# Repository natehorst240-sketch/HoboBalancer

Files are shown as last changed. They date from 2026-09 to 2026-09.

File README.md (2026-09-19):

# HoboBalancer

Hobby helicopter rotor-balancing instrumentation. KiCad 10 projects plus ESP32-S3
firmware.

> **Reference and troubleshooting only.** These boards report approximate RPM, 1/rev
> vibration magnitude, phase, stability and trends. Maintenance balancing remains with
> calibrated MicroVib / DynaVibe equipment. Neither the firmware nor the physical
> measurement accuracy has been validated on a bench, let alone on an aircraft. Nothing
> here is airworthiness-approved.

Open the projects in **KiCad 10.0.3 or later**. They use the KiCad 10 file format and
KiCad 9 will not open them.

## Projects

| Directory | Board | Revision | State |
|---|---|---|---|
| `.` (root) | `Balancer` — STM32 balancer | Rev A | Schematic only; `Balancer.kicad_pcb` is an empty stub |
| `BalancerREF/` | **HOBOVibe** — ESP32-S3 reference puck | **Rev G** | 50 × 50 mm, 4 layer, fully routed, DRC clean apart from three accepted warnings (see below) |
| `BalancerREF_OptHead/` | Optical tach head | **Rev B** | 25 × 50 mm, 2 layer, routed; no mounting holes yet |

Both boards are routed. On the main board `SYS`, `SYS_SW`, `BAT` and `USB_VBUS` had been
routed across In2.Cu, which is the +3V3 plane; those tracks were removed on 2026-09-18 so
the plane is whole again, and those four nets were then re-routed on the outer layers (PR #7,
merged with Rev G on 2026-09-19). The Rev G connections (U7 pass-through, R39) are routed too.
`BalancerREF/review/drc-review.rpt` (KiCad 10.0.6) shows 0 errors and 0 unconnected; what is
left is the GCT USB-C footprint's own peg-to-pad spacing (4), the ESP32 antenna overhanging
the edge by design (2) and the locally edited U1 footprint (1).
Placement was machine-generated and then adjusted by hand; look at it in pcbnew before
trusting it.

Both carry pick-and-place **fiducials** (1 mm dot, 2 mm mask opening): three per
populated face, at three of the four corners. Never four — a symmetric set gives the
placement machine no way to tell a 180°-rotated panel from a correct one. The main
board has them on both faces; the optical head is single-sided so its back has none.

### Track widths

Net classes are set in each `.kicad_pro`, sized from IPC-2221 at 1 oz outer copper and
a 10 °C rise (0.20 mm ≈ 0.74 A, 0.50 mm ≈ 1.45 A, 0.80 mm ≈ 2.03 A):

| Class | Track | Nets |
|---|---|---|
| Default | 0.20 mm | everything else |
| Power | 0.50 mm | `+3V3` `SYS` `SYS_SW` `BAT` `USB_VBUS` `GND` |
| Switch | 0.80 mm | `U6-L1` `U6-L2` — main board only |
| USB | 0.20 mm | `D+`/`D-` both sides, diff pair 0.20/0.15 |
| Emitter | 0.80 mm | `SYS_SW` `D1-A` `D1-K` — head board only |

The emitter resistor is sized at the **top** of the SYS_SW range, not at the battery.
The BQ24075 regulates OUT to 5.5 V, so R18 is 3.9 Ω for about 0.49 A at a full cell and
about 0.90 A worst case — under D1's 1 A absolute maximum. At the old 3.0 Ω the USB case
reached roughly 1.1 A.

Two caveats. **Switch clearance stays at 0.20 mm**, not the 0.25 the wider track might
suggest: the TPS63031's WSON-10 places its own L1/L2 pads 0.20 mm from its thermal
pad, so anything stricter fails inside the package and no routing choice can fix it.
And the **USB numbers are not an impedance solution** — real 90 Ω differential needs
the fab's actual stackup. The ESP32-S3's native USB is Full Speed (12 Mbps), where
that matters far less than it would at High Speed.

### BalancerREF (HOBOVibe)

The main puck. ESP32-S3-MINI-1, IIS3DWB vibration sensor on SPI, LM1815 magnetic tach
front end, BQ24075 charger with an integrated dynamic power path, TPS63031 buck-boost, and a
1x05 header for an optional u-blox-class GPS used by the in-flight logging mode.

Two measurement profiles: **MR-VERT** uses an external isolated two-wire VR pickup;
**TR-VERT** uses the optical tach against retroreflective tape.

50 × 50 mm, four layers, components on both faces: ICs, connectors, switches and test
points on the front, passives on the back so each decoupling cap sits under its IC's
power pins. M2.5 mounting holes at the four corners, on a 43.40 × 42.90 mm rectangle
centred on the board. U1's antenna deliberately overhangs the top edge, which puts
almost all of its keepout off the board — the wide band still reaches 0.44 mm inside
the top edge, which is why the mounting-hole rectangle is 0.5 mm shorter than it is
wide. The overhang is required anyway, because the aluminium bracket must not sit
behind a PCB antenna.

The puck mounts **vertically, ESP32 to the left and USB-C to the right**. `UP` and
`LEFT` markers on the front silkscreen record that; with the board vertical the
accelerometer's vertical axis is in-plane (stiff) and the flexible out-of-plane axis
carries lateral instead. Which sensor channel that is still needs recording from
DS12569's orientation figure — firmware can also identify it at runtime, since the
vertical axis reads a static 1 g when the puck is mounted upright.

Three switches: SW1 power slide, SW2 acquire, SW3 boot. There is no reset button —
SW1 feeds U6's VIN and EN, so the power slide already power-cycles the MCU. SW1 is a
Würth WS-SLTV rated 300 mA switching; steady draw through it is about 180 mA, but BLE
TX bursts and switch-on inrush exceed that briefly. That is accepted as reduced switch
life rather than designed out — see DATASHEET-VERIFICATION.md.

**Sleep is not low power.** The LM1815 draws 3.6 mA typical (6 mA max) and sits on the
always-on 3V3 rail, as do the head's op-amp and comparator, so a sleeping puck draws
milliamps and a 500 mAh cell lasts days rather than months. If flight logging ever
depends on long sleeps, the fix is a load switch on the LM1815 and the head supply.

**Power path and charging.** A BQ24075 runs the input: it charges the cell and powers
the system from the same input independently, so charge termination is correct while
the puck is running, and it will run with a defective or absent pack. R3 (3.57 k)
sets fast charge to about 249 mA — 0.5C for a 500 mAh cell — and R35 (1.6 k) sets the
resistor-programmed input limit to about 1.0 A.

Four pins go to the MCU. `CHG_EN1` (GPIO5) and `CHG_EN2` (GPIO18) select the input
current limit; `PGOOD_N` (GPIO21) and `CHG_STAT` (GPIO38) are open-drain status inputs
with 100 k pull-ups, both **active low**. Two things are easy to get wrong here:

- The datasheet's current-limit table is indexed **(EN2, EN1)**, the reverse of the
  order the pins are named in.
- Both EN pins have 285 k internal pulldowns, so the limit is USB100 — **100 mA** —
  until firmware deliberately raises it.

`PGOOD_N` is the USB-present signal. Earlier revisions tried to infer that by comparing
two ADC dividers, because a single reading of `SYS_SW` cannot answer it: SYS was fed
either from USB through a Schottky or from the cell through a PFET, and the ranges
overlap. The BQ24075 arbitrates the input itself and simply reports the answer, so
Rev E deleted the second divider (`BAT_SENSE`, R33/R34/C31) along with its 500 k ADC
source impedance and its ~2 µA standing drain on the cell.

`SUPPLY_SENSE` (`SYS_SW/2` on GPIO12) survives as the supply-voltage reading. While the
puck runs unplugged the BQ24075 connects OUT to the battery, so it reads the cell; while
charging it reads the input-derived rail instead, not the cell. It is on ADC2_CH1, the
converter shared with the radio — worth knowing, because it is now the only supply
measurement on the board.

See [`BalancerREF/README.md`](BalancerREF/README.md) for the circuit description and
[`BalancerREF/DATASHEET-VERIFICATION.md`](BalancerREF/DATASHEET-VERIFICATION.md) for
every pin mapping checked against the manufacturer tables.

### BalancerREF_OptHead

The optical tach front end, split onto its own board on 2026-09-11. It mounts at 90° to
the main PCB on the second leg of an aluminium L-bracket, on a pivot bolt so the emitter
can be aimed at the tape. The split exists because neither optical part has leads to
form — the XPEBRD-L1 is a ceramic SMD LED and the BPW34S is the surface-mount BPW34 — so
they need their own copper.

The cut is deliberately placed **after** the comparator. The cable then carries only DC
rails and digital edges; cutting at the photodiode would have put the 10 kΩ
transimpedance summing junction on a flying lead beside a wire switching 500 mA at
20 kHz.

Connected to the main board by a 7-way cable (`J5` on both). Ground is interleaved
between the two digital lines: emitter-pulse crosstalk onto `OPT_COMP` arrives inside
the synchronous gating window by definition, so the detection logic cannot reject it and
it has to be stopped at the connector.

25 × 50 mm, two layers, **every part on the front** so B.Cu can be a ground pour. Five
short signal crossings (`AMP_INV`, `OPT_AMP`, `CMP_OUT`, `OPT_COMP`, `OPT_LED_EN`) still
run on B.Cu, two of them directly under U8, and should move to the front before fab. The
board also has **no mounting or pivot hole yet**; the position depends on the bracket. A
solid back-side ground is worth more than a clean optical face: the transimpedance summing node is
the highest-impedance point in the design and sits beside a wire switching 500 mA at
20 kHz. The cost is that the baffle and the red acrylic window have to clear the
electronics.

D1 sits centred on the optical axis with PD1 18 mm directly below it. **That spacing
and the lens keepout radius are estimates** — both are constants at the top of
`scripts/build_pcb.py` and should be set from the real Ledil TINA holder before anyone
commits to them. The spacing is the one that affects performance: it sets baffle depth
and the parallax back to the tape at the 18–24 in working range.

Refill zones (`Edit → Fill All Zones`) after any edit made outside pcbnew; the scripts
here cannot drive KiCad's zone filler.

## Verification

Both boards carry a connectivity checker that compares an exported netlist against
circuit specifications written by hand — exact net membership, so an unintended short, a
bypassed series part or a reversed two-terminal part fails rather than passing quietly.

```bash
# main board
cd BalancerREF
kicad-cli sch export netlist --format kicadsexpr -o review/BalancerREF.net BalancerREF.kicad_sch
python scripts/verify_netlist.py     # PASS: 49 exact circuit nets, 293 pin endpoints

# optical head
cd ../BalancerREF_OptHead
kicad-cli sch export netlist --format kicadsexpr -o review/OptHead.net BalancerREF_OptHead.kicad_sch
python scripts/verify_head.py        # PASS: 16 exact circuit nets, 63 pin endpoints
```

Each board has its own spec. The main board's covers everything except the optical
chain and asserts that *every* pin in the netlist belongs to some named net, so a
wrong connector pinout or a missed part fails rather than passing quietly. Run these
against a freshly exported netlist — a stale `.net` will report a green that means
nothing.

Both sheets pass ERC at **0 errors and 0 warnings**. Removing a part leaves the wires
that used to reach its pins, so `BalancerREF/scripts/fix_dangling_wires.py` sweeps those:
it removes a wire only when one end touches nothing at all, never removes a wire carrying
a label (labels attach to wire bodies, so that would silently split a net - trimming the
dead tail back to the label is the fix there), and exports the netlist before and after
to prove no pin changed net. It checks its own geometry against KiCad's ERC first and
aborts if the two disagree.

Generator scripts under `scripts/` are guarded and refuse to run without
`--overwrite-hand-layout`: both sheets were laid out by hand after generation, and the
`.kicad_sch` files are the source of truth.

## Revisions

Hardware revisions are marked with git tags rather than in filenames, so the KiCad
project names stay stable across revisions. `git tag` lists them; `git checkout revD`
gets that snapshot.

| Tag | Board state |
|---|---|
| `revC` | single board, optical front end on the main PCB, no layout |
| `revD` | optical head split out; SW4 and R5 dropped; BAT sense divider added; both boards placed |
| `revE` | MCP73831 + D2 + Q3 + R27 + R31 replaced by a BQ24075; BAT sense divider removed |
| `revF` | PD1 polarity fix; R18 3.9 ohm; U9 Schmitt NAND; switcher and TIA placement |

Rev D was defined by the **battery/supply sensing change** — `BAT_SENSE` on GPIO4
alongside `SUPPLY_SENSE`, to let firmware tell USB from battery. The board split and the
two part deletions rode along in the same revision.

Rev E is the **charge-management change**, and it removed Rev D's divider again: with a
BQ24075 arbitrating the input, `PGOOD` answers "am I on USB?" directly and the
two-divider comparison had nothing left to do. Five discrete parts went with it.

Rev F is the **repo-review revision** — no new function, but a set of corrections that
had to land before any copper is routed. One of them cleans up after Rev E: removing the
USB Schottky raised `SYS_SW`, which pushed the head's emitter resistor past D1's absolute
maximum current. The others are a logic part run outside its input-transition spec and
three placement problems, the worst being a 2.4 MHz switching loop routed through vias.
Rev F is also the first revision of the optical head since it was created, so that board
moves from Rev A to **Rev B**.

Rev F also carries the one outright **functional** defect found so far: PD1 was wired
with its anode on the transimpedance summing node, which sends the signal the wrong way
through two inverting stages and leaves the comparator unable to trip at any light level.
The optical tach could never have worked. Flipping the detector fixes it without changing
anything else; `BalancerREF/DATASHEET-VERIFICATION.md` traces the chain stage by stage,
including why the connectivity checkers passed the whole time — they prove the netlist
matches the intent, not that the intent works.

Rev G is the **Reddit-review revision** (2026-09-19). Three schematic corrections on the
main board: the USB VBUS TVS (D3) was drawn forward biased, the USB data lines now pass
through the ESD array (U7) instead of hanging off it as stubs, and U9's OPT_COMP input
gets a pull-down so it does not float when the optical head is unplugged. The board
carries the new pad nets, and the USB pass-through and the new resistor are routed.

Two review items were checked and deliberately **not** changed — SW1's current rating
and U1's footprint. `BalancerREF/DATASHEET-VERIFICATION.md` records why, so they are not
re-raised at the next review.

## Not in this repo

Build output (`.pio/`, `build/`, `release/`), the firmware virtualenv, and the
point-in-time `*-backups/` and `archives/` zips are excluded — git tracks history
itself. Manufacturer datasheets in `BalancerREF/sources/` are included for reference
alongside the pin audits; `scripts/fetch_sources.py` re-fetches them from the URLs in
`sources/urls.json`.

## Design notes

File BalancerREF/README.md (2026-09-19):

# BalancerREF (HOBOVibe) — reference rotor-vibration puck

ESP32-S3 firmware is in [firmware/README.md](firmware/README.md), including build/flash instructions, MR-VERT/TR-VERT controls, BLE/USB protocol, and a MicroVib comparison logger. Its measurement accuracy remains subject to bench validation.

Open **BalancerREF.kicad_pro**, then **BalancerREF.kicad_sch**, in KiCad 10.0.3 or later (KiCad 10 format; KiCad 9 will not open it). One A2 schematic sheet, Rev G (2026-09-19), hand-laid-out in KiCad (title "HOBOVibe Hobby Helicopter Dynamic Balancer"). The PCB is 50 x 50 mm, four layers (In1 GND plane, In2 +3V3 plane), fully routed with both inner planes uncut (the power nets that had crossed the +3V3 plane were moved to the outer layers on 2026-09-18). The custom library and project library table travel with the schematic. Most symbols are standard KiCad 10 symbols; IIS3DWB, SN74LVC1G123, LM1815, TS3021 and BQ24075RGT have local definitions with pin mappings verified against the manufacturer tables (see DATASHEET-VERIFICATION.md). The embedded USB-C receptacle and potentiometer symbols were re-synced from the KiCad 10 library (`scripts/sync_kicad10_symbols.py`) because KiCad 10 renamed the USB-C shield pin and footprint pad from S1 to SH; the pre-sync project is archived in `archives/RevB-before-kicad10-symbol-sync-20260907-214948.zip`.

This is a reference/troubleshooting instrument for approximate RPM, 1/rev vibration magnitude, phase, stability and trends. Maintenance balancing remains with calibrated MicroVib/DynaVibe equipment. Firmware and physical performance have not been validated by schematic ERC.

## Review files

- `review/BalancerREF.pdf`: searchable vector rendering of the one-sheet schematic.
- `review/erc.rpt`: KiCad 10 ERC report, all severities included.
- `review/connectivity-check.txt`: independent exact-net comparison against the intended circuits.
- `review/IC-pin-audit.csv`: every IC physical pad, manufacturer function, resulting net and unused-pin explanation.
- `review/pin-net-connections.csv`: all component pin/net connections.
- `review/unused-pins.json`: reasons for every NC marker.
- `DATASHEET-VERIFICATION.md`: manufacturer sources, pinout decisions and calculations.

All local functional circuits use real wires. Labels carry signals between complete blocks. Test points stay beside their measured circuits. Ground symbols all represent the same common ground.

## Operating intent

| Profile | Tach input | IR emitter | Vibration |
|---|---|---|---|
| MR-VERT | External isolated two-wire VR pickup at J3 / J_MAG | Off | Internal IIS3DWB on SPI, all axes available |
| TR-VERT | Onboard pulsed-red synchronous-detection optical tach (retroreflective tape) | 20 kHz pulses | Same sensor |

### Rev G changes (2026-09-19)

Three corrections from a Reddit review of the Rev C sheet, all of which still applied
to Rev F. `scripts/rev_g_usb_esd_tvs_u9.py` edits the schematic and
`scripts/sync_board_rev_g.py` carries the result into the board.

- **D3 was backwards.** The SMF5.0A is a unidirectional TVS, and DATASHEET-VERIFICATION.md
  had recorded it as bidirectional with "either orientation valid". It was drawn cathode
  to GND, anode to VBUS: forward biased, so it would have clamped USB VBUS at a diode
  drop as soon as a cable went in. Cathode (pin 1) is now on USB_VBUS and the board
  footprint is rotated 180 to match.
- **USB data lines now go through U7.** The SRV05-4's pins 4 and 6 were marked NC, so
  D+/D- reached the array as stubs. Pin 6 is directly across from pin 1 and pin 4 across
  from pin 3, so the drawing now takes D- in at pin 1 and out at pin 6, D+ in at pin 3
  and out at pin 4, and the pads on the board carry those nets. The SRV05-4 has no
  internal path between its I/O pins, so both ends of each pair keep the same net name
  and the trace itself makes the through-connection: `scripts/route_rev_g.py` runs a
  0.2 mm track straight across the package from pin 3 to pin 4 and from pin 1 to pin 6.
- **U9 pin 1 no longer floats when the head is unplugged.** OPT_COMP arrives from the
  optical head through J5 pin 5 (driven via R32 on the head). In MR-VERT the head is
  normally not connected, leaving a CMOS input open. R39 100k to GND holds it low; it is
  placed on the back directly under the OPT_COMP trace just left of U9, so one via at each
  pad connects it. U9 pin 2 (via R29 from OPT_LED_EN) floats
  only during ESP32 reset, when the GPIO is still an input, and was left alone.
- `review/reddit/` re-rendered from the Rev G sheet at higher resolution (the old set
  was Rev C at roughly 200 DPI; see `scripts/render_review_images.py`).

### Rev F changes (2026-09-13)

Rev F is the **repo-review revision**: no new function, but several things that had to
be right before any copper is routed. Every claim was checked against the manufacturer
source, and two of them did not survive that check (see DATASHEET-VERIFICATION.md for
the full record, including what was deliberately NOT changed).

- **PD1 polarity corrected - the optical tach could never have worked.** The detector
  was wired cathode to +3V3 and anode to the transimpedance summing node. Reverse bias
  is correct that way, which is why it survived this long, but photocurrent leaves the
  ANODE, so it was injected into the summing node instead of pulled out of it. The
  inverting TIA then drove TIA_OUT down, the inverting second stage drove OPT_AMP UP
  from its 1.65 V idle, and U4 has OPT_AMP on IN- against a 1.016 V threshold on IN+.
  The comparator input sat 634 mV above the threshold and light pushed it further away,
  so the output never left its low state and TR-VERT had no tach at all. Cathode now
  goes to PD_TIA_IN and the anode to GND: same 1.65 V reverse bias, but TIA_OUT rises,
  OPT_AMP falls through the threshold, and the 470k hysteresis works as drawn. About
  5.3 uA of photocurrent trips it. Bonus: the emitter turn-off edge, which lands inside
  the gate window and cannot be rejected, now couples into the summing node in the
  non-detection direction - which matters because this revision also moved Q1 nearer
  PD1.
- **R18 3.0 -> 3.9 ohm on the head board.** The emitter runs from SYS_SW, and the
  BQ24075 regulates OUT to 5.5 V, so the old value gave about 1.1 A peak into D1's 1 A
  absolute maximum. The BOM note had only checked the 4.2 V battery case. This is a
  regression introduced by Rev E: the Schottky it removed had been holding SYS near
  4.55 V. 3.9 ohm keeps the 500 mA design point at a full cell and lands at about
  0.90 A worst case.
- **U9 SN74LVC1G08 -> SN74LVC1G132.** R29/C26 fed the AND gate a 0.47 us edge against a
  10 ns/V input transition spec. The 1G132 is a Schmitt NAND on the identical SOT-23-5
  pinout, so the footprint is untouched, and it conditions both inputs rather than only
  the RC branch. It inverts, so U10's trigger moved from B rising to ~A falling - the
  SN74LVC1G123 supports both edges.
- **Switching loop off the vias.** L1 and C4-C7 were on the back with U6 on the front,
  so a 2.4 MHz switching node and both its input and output caps reached the IC through
  vias. They moved to U6's face, and C1/C2/C3/C30 followed for the BQ24075. The
  "ICs front, passives back" rule does not survive contact with a switching converter.
  Two follow-on corrections came out of review: aim at the **pin**, not the net, and
  place the fastest part first. U6 pins 5-8 are all on SYS_SW, so targeting "the input
  net" had put the caps next to EN and PS/SYNC - logic inputs that happen to be strapped
  high - rather than VIN and VINA; and the 10u bulk had taken the close spot while the
  100n sat 4.4 mm out. C5 now sits 2.07 mm from VINA and C4 2.68 mm from VIN. C1, the
  100n bypass on the BQ24075's IN pin, turned out to be **24 mm away on the back of the
  board**, which is the same as not fitting it; it is now 5.3 mm out on the front.
  TP6 and TP10 were squatting immediately left of U6 - the side VIN and PGND are on -
  and were the reason the bulk input cap could not get near its pins. They moved beside
  the circuits they actually probe.
- **U1 decoupling at the pad.** C8 is now 0.38 mm from the 3V3 pad rather than about
  9 mm. Both caps stay on the back, since U1's body owns that part of the front.
- **Head board loop and TIA.** C20/R18/Q1 now cluster in 6.9 x 3.3 mm instead of
  spanning the board width, and R21/C21 moved from 4 mm off Q1 to 16 mm, sitting
  3.6/3.9 mm from U8 pins 1 and 2. The remaining ~8 mm up to D1 is set by its
  provisional lens keepout, which is why those parts sat at the board edges to begin
  with.
- **Firmware drives the charger.** EN1/EN2 were left to their internal pulldowns, so the
  input limit sat at USB100 - 100 mA covering system load and charge current together.
  `setupCharger()` selects USB500 at boot and status reports `input_present`/`charging`.
- Accepted rather than fixed, both recorded with numbers: SW1's 300 mA switching rating
  against a ~180 mA steady draw with larger transients, and the LM1815's 3.6 mA on the
  always-on rail making deep sleep a milliamp affair.

The head board is **Rev B** as of this revision - its first change since creation.

### Rev E changes (2026-09-13)

- **BQ24075 replaces the MCP73831 charger**, and D2, Q3, R27 and R31 go with it. The
  discrete Schottky-plus-PFET arrangement OR-ed USB against the battery; the BQ24075
  has an integrated dynamic power path (DPPM) that does it properly - system and
  charging powered independently, operation with a defective or absent cell, USB-IF
  inrush limiting, and VIN-DPM so a weak port sags instead of collapsing. Support
  parts: R3 3.57k sets ~249 mA fast charge (about 0.5C for a 500 mAh cell), R35 1.6k
  sets the ~1.0 A resistor-programmed input limit, R36 10k stands in for the absent
  pack thermistor on TS, R37/R38 100k pull up the open-drain status pins, C30 10 uF on
  OUT. TMR is deliberately left open for the default safety timers; CE and SYSOFF are
  tied low. All seventeen pins are checked against SLUS810N in DATASHEET-VERIFICATION.md.
- **Charger control on four GPIOs**: EN1 = GPIO5, EN2 = GPIO18, PGOOD = GPIO21,
  CHG = GPIO38. Note that the datasheet's current-limit table is indexed (EN2, EN1),
  the reverse of the naming order. Both EN pins have 285k internal pulldowns, so the
  part powers up in USB100 (100 mA). *Rev F added `setupCharger()`, which selects
  USB500 at boot; before that, firmware never drove these and the puck charged at
  100 mA - a limit that covers system load and charge current together.*
- **BAT sense divider removed**: R33, R34, C31 and the `BAT_SENSE` net are gone. They
  existed only to infer USB presence by comparing SYS_SW against BAT. PGOOD reports a
  valid input source directly from the device that arbitrates it, which is both simpler
  and more trustworthy, and dropping the divider retires a 500k ADC source impedance
  and a ~2 uA permanent drain on the cell. GPIO4 is an unused pin again.
  The trade is that `SUPPLY_SENSE` (GPIO12, ADC2_CH1) is now the board's only supply
  measurement, and ADC2 is the unit shared with the radio - which is precisely why the
  removed divider had been put on ADC1.
- **Wire stubs swept**: the optical split, SW4, R5 and the charger swap each left the
  wires that used to reach the deleted pins, connected to a live net at one end and to
  nothing at the other - 19 of them, plus one orphaned no-connect flag. 23 wires were
  removed and 2 were trimmed back to the label they carry (`BAT` and `OPT_LED_EN`,
  where deleting the wire would have taken the label with it). `scripts/fix_dangling_wires.py`
  exports the netlist before and after and refuses to keep any edit that moves a single
  pin to a different net. **ERC is now 0 errors and 0 warnings**, down from 20.
- **`/SYS` added to the Power net class** (0.50 mm). It is the BQ24075's OUT rail and
  carries the entire system load; it did not exist under the old topology and would
  otherwise have routed at the 0.20 mm default, rated 0.74 A.

**At Rev E firmware did not drive the charger.** `board.hpp` carried the four pins and
`tests/check_pinmap.py` verified them against the KiCad pad audit, but nothing read
PGOOD or raised the input current limit. Rev F fixed that - see the Rev F section
above.

### Rev D changes (2026-09-13)

- **BAT sense divider added** *(removed again in Rev E - the BQ24075's PGOOD pin
  reports input power directly)*: R33/R34 (1M) and C31 (100n) put `BAT/2` on GPIO4
  (ADC1_CH3) as `BAT_SENSE`. `SUPPLY_SENSE` alone cannot distinguish USB from battery
  because SYS is fed either from USB through D2 or from the cell through Q3, and the
  ranges overlap - a USB port at the low end of spec minus D2's drop sits near 4.30 V
  against a full cell at 4.20 V, inside divider tolerance plus ADC error. Comparing the
  two separates them: `SYS_SW > BAT + ~0.3 V` means USB present. 1M/1M rather than
  SUPPLY_SENSE's 100k/100k because this divider hangs on the cell even when the puck is
  switched off (~2 uA against ~21 uA); the resulting 500k source impedance means
  firmware must use a long sample time and multisample.
- **Optical front end split out** to `BalancerREF_OptHead` (2026-09-11), leaving J5, a
  7-way cable connector. D1/PD1 have no leads to form, so they need their own copper on
  the bracket's second leg. The cut sits after the comparator so the cable carries only
  DC rails and digital edges.
- **SW4 (RESET) removed**: SW1 feeds U6's VIN and EN, so the power slide already
  power-cycles the MCU. R4/C10/TP13 still hold EN high and keep it probeable.
- **R5 removed**: it duplicated R9's 10k BOOT pull-up on the same net. The BOOT net is
  now U1.4, R9.2, SW3.2, TP14.1.
- Board work: 50 x 50 mm four-layer, M2.5 corner mounting holes, fiducials on both
  faces, `UP`/`LEFT` orientation silkscreen, and net classes for track widths.

**Firmware 0.4.0 predates this revision.** It never gained a `BAT_SENSE` reader, which
Rev E made moot. The pin-map test no longer passes vacuously: it now asserts that every
pin in `board.hpp` is covered by the test.

### Rev C changes (2026-09-09)

- **Accelerometer**: LIS2DW12 (I2C) replaced by the ST IIS3DWB vibration sensor on 4-wire SPI: GPIO14 SCK, GPIO15 MOSI, GPIO16 MISO, GPIO17 CS, INT1 data-ready still on GPIO6. RES pads 2/3 to GND, 10/11 open, per DS12569. The IIS3DWB has no wake-on-motion, so deep-sleep wake moves to EXT1 on MAG_TACH (GPIO7) or the acquire button (GPIO10). Firmware 0.3.0 still targets the LIS2DW12 and needs the driver port before this revision is flashed.
- **Optical tach**: the DC infrared pair and trimpot are gone. D1 is a Cree XP-E2 red LED pulsed at 20 kHz / 5 us / about 500 mA from SYS_SW through Q1 (3 ohm 1206 series, 100 uF local reservoir). PD1 BPW34S is reverse-biased into a 10k transimpedance stage referenced to 1.65 V (U8A), then a x12 inverting AC stage (U8B, TLV9062). In the detection row, U4 TS3021 compares against a fixed 1.03 V threshold with 470k hysteresis, U9 (74LVC1G08) accepts a hit only while the RC-delayed emitter pulse is high (synchronous detection), and U10 (74LVC1G123, 100k / 1 nF, about 100 us retriggerable) stretches consecutive hits into one OPT_TACH edge per tape pass. Working range 18-24 in with retroreflective tape and the Ledil TINA lens; see PhotoTach-BOM.csv for the Digi-Key sourced parts. Threshold and delay values are bench-set.
- **Battery**: Q4 AO3401A between J2 and the BAT node blocks a reversed pack (gate to GND; body diode conducts at first contact, then the channel).
- **USB**: D3 SMF5.0A TVS on VBUS at the connector *(drawn reversed until Rev G)*.
- **ADC**: 100 nF on SUPPLY_SENSE at GPIO12.
- **GPS header J4** (added 2026-09-07) unchanged.
- The Rev C circuits were first produced by `scripts/build_schematic.py` (Rev B generator retained as `build_schematic_revb.py`, transformation in `patch_rev_c.py`) followed by `scripts/add_gps.py`, then the sheet was re-laid-out by hand in KiCad on 2026-09-09 into five blocks on A2 with the same connectivity (verified identical net membership). The generators are now guarded and refuse to run without `--overwrite-hand-layout`; the schematic file is the source of truth. Rev B final state archived in `archives/RevB-final-before-revc-20260909-030859.zip`.

J4 is a 1x05 2.54 mm header for an optional 3.3 V u-blox class GPS module used only by the in-flight logging mode: 1 VCC, 2 GND, 3 GPS TX to GPIO2 (UART1 RX), 4 GPS RX from GPIO1 (UART1 TX), 5 PPS to GPIO13. UART1 was chosen over the UART0 pads so ROM boot output never reaches the GPS. Added 2026-09-07 with `scripts/add_gps.py`; the pre-GPS project is archived in `archives/RevB-before-gps-20260907-230803.zip`.

J3 is two plated wire holes, not an aircraft connector: pin 1 MAG+, pin 2 MAG-. Its final hole spacing/strain relief is a PCB decision. The mating aircraft connector belongs on the external twisted-pair pigtail. MAG- is common ground; this front end is for a passive, isolated pickup, not an energized aircraft signal.

The 500 mAh battery must be a protected single-cell 4.2 V-charge LiPo pack. J2 pin 1 is positive; pin 2 is negative. Confirm the pack's JST polarity before connection. The PCB charger is not an overdischarge/protection circuit.

Revision B charges with SW1 either ON or OFF, at approximately 249 mA nominal. D2 and Q3 provide USB/battery power sharing: USB supplies the puck separately from the charger, allowing normal charge termination while running. SW1 is after the combined SYS rail and controls only the puck. Without USB, the battery automatically supplies SYS through Q3. With USB and SW1 ON, programming can work without a battery; hold BOOT while resetting if needed. Use a regulated 5 V USB source rated at least 1 A. This revision has no USB current-negotiated charging controller; unrestricted operation from a legacy computer port is not established.

The GPIO12 divider now measures switched supply voltage (`SUPPLY_SENSE = SYS_SW / 2`), rather than directly sensing USB VBUS. This prevents the divider from feeding an unpowered MCU with SW1 OFF. It is not a dedicated USB-presence signal. The original revision is preserved in `archives/RevA-before-independent-charging.zip`. Use `BalancerREF-Schematic-RevC.pdf` for the current preview; older RevB PDFs may still be open in a viewer.

The optical tach is modelled on an industrial retroreflective photoelectric sensor: pulsed emitter, synchronous detection, fixed threshold. Ambient light cannot coincide with the 5 us emitter windows, so sunlight and flickering lighting are rejected rather than trimmed out. A red acrylic window and an internal baffle between D1 and PD1 are still required. Insufficient reflection must produce an invalid measurement, not a balancing recommendation.

## GPIO allocation

| Signal | ESP32 GPIO | MINI-1 physical pad |
|---|---:|---:|
| ACCEL_SCK | 14 | 18 |
| ACCEL_MOSI | 15 | 19 |
| ACCEL_MISO | 16 | 20 |
| ACCEL_CS | 17 | 21 |
| ACCEL_DRDY | 6 | 10 |
| MAG_TACH | 7 | 11 |
| OPT_TACH | 8 | 12 |
| OPT_LED_EN (20 kHz PWM, emitter) | 9 | 13 |
| ACQUIRE_BUTTON | 10 | 14 |
| STATUS_LED | 11 | 15 |
| SUPPLY_SENSE | 12 | 16 |
| USB D- | 19 | 23 |
| USB D+ | 20 | 24 |
| GPS_UART_TX (to GPS RX, J4.4) | 1 | 5 |
| GPS_UART_RX (from GPS TX, J4.3) | 2 | 6 |
| GPS_PPS (J4.5) | 13 | 17 |
| BOOT | 0 | 4 |
| EN / RESET | — | 45 |

Use GPIO-matrix routing to MCPWM capture or RMT for tach timing. Keep Wi-Fi disabled during normal BLE acquisition. Sample the IIS3DWB at its fixed 26.7 kHz ODR (or decimate in firmware) and timestamp INT1 data-ready; its response is flat to 6.3 kHz so filter phase at rotor frequencies is negligible. Account for sensor/filter and optical delays when estimating phase. There is no hardware absolute-phase calibration.

## Scope before PCB (historical, written before Rev D; the PCB now exists)

Future target is approximately 50 × 40 mm. Place MEMS near the rigid mounting point, reserve the Espressif antenna keepout, and point the formed-lead optical parts through the LEFT edge. No board outline, copper, routing or PCB file is included. Inductor, formed-lead optics, switches and wire-hole footprints are intentionally left for mechanical selection in the PCB phase; IC footprints and the USB/JST connectors use library assignments.

Bench verification must establish useful pickup amplitude/range, optical working distance and ambient tolerance, RPM/phase repeatability, vibration noise floor and power/charging behavior. ERC checks wiring classes and connectivity; it does not establish measurement accuracy or EMC performance.

## Reproduce verification

The scripts use Python 3 with `sexpdata` and `pymupdf`, and an installed KiCad 10 symbol library. `build_schematic.py` is retired (guarded) because the sheet is hand-maintained; `final_review.py` runs the whole chain below on the current file and refreshes the review PNGs, hashes and PDF copies.

```powershell
& 'C:\Program Files\KiCad\10.0\bin\kicad-cli.exe' sch erc BalancerREF.kicad_sch -o review/erc.rpt --severity-all --exit-code-violations
& 'C:\Program Files\KiCad\10.0\bin\kicad-cli.exe' sch export netlist BalancerREF.kicad_sch -o review/BalancerREF.net
python scripts/verify_netlist.py
& 'C:\Program Files\KiCad\10.0\bin\kicad-cli.exe' sch export pdf BalancerREF.kicad_sch -o review/BalancerREF.pdf
```

The verifier checks complete net membership, not just that expected pairs connect. This catches unintended shorts, bypassed series components and supply capacitors accidentally attached to switching nodes. No ERC exclusions or severity downgrades are used. Three PWR_FLAG symbols identify USB input power, common source ground and power arriving through SW1. The regulator and charger outputs already declare their own power sources.

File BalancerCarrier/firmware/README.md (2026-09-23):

# BalancerCarrier firmware

Bench-test firmware for **BalancerCarrier**, the puck rebuilt as a carrier board around an **Unexpected Maker FeatherS3[D]** (ESP32-S3, 16 MB flash, 8 MB QSPI PSRAM). It is not interchangeable with the BalancerREF firmware: the pin map differs (see `src/board.hpp`), and a BalancerREF image drives pins that are inputs on this board. It is separate from the full analyzer project. The schematic and PCB files are not changed by this firmware project. No aircraft weight corrections are automatically calculated or applied.

Implemented: MR-VERT magnetic tach, TR-VERT optical tach/emitter, all three IIS3DWB axes over SPI, hardware timestamps, finite and continuous back-to-back acquisitions, autonomous in-flight logging with GPS tagging and tach/button-wake deep sleep, approximate 1/rev velocity magnitude and phase, stability flags, run trends, BLE, native USB JSON console, persistent per-profile settings, and MicroVib comparison proposals. Wi-Fi is never initialized.

The code can check signal consistency but cannot certify IPS accuracy. Physical sampling latency, sensor frequency response, tach integrity, BLE operation, power behavior, and comparison with calibrated equipment remain hardware acceptance tests. Default gain is 1 and phase offset is 0. The provisional Z axis must be explicitly confirmed or changed before a run is marked stable.

## Hardware support status

The FeatherS3[D] owns power, so the carrier has no charger pins:

- **Charging and USB** are the module's. There are no EN1/EN2/PGOOD/CHG signals; `status.charging` comes from the fuel gauge.
- **Battery voltage and charge state** come from the module's MAX17048 fuel gauge on its I2C bus (GPIO8 SDA, GPIO9 SCL, address 0x36; pull-ups fitted on the module). `battery_v` is the cell itself, including while charging.
- **USB present** is the module's VBUS divider on GPIO34 (`status.input_present`).
- **GPS power** is the module's LDO2 (NCP167, 700 mA) on GPIO39. It is off at reset, so the GPS is dead until firmware raises it; it is fed from VBUS, which ORs USB and battery, so it runs on battery.

`tests/check_pinmap.py` checks `board.hpp` against the carrier schematic's netlist, and the module-internal pins against their documented values.

## Carrier hardware

GPIO numbers are ESP32-S3 GPIOs, not FeatherS3 header pins. Accelerometer: ST IIS3DWB on SPI2 (GPIO12 SCK, 11 MOSI, 14 MISO, 17 CS, mode 3, 10 MHz), SPI-only per DS12569, fixed +/-16 g (see `src/accelscale.hpp`), LPF2 at ODR/10 (2.67 kHz). The sensor streams its fixed 26.667 kHz ODR into its FIFO with the watermark at 16 samples; INT1 (GPIO18) is the FIFO-threshold line and is timestamped by the same MCPWM capture channel that timestamped data-ready before. Each block is read in one 112-byte SPI transfer and averaged into a single 1666.7 Hz measurement sample whose timestamp is the capture tick minus 7.5 sample periods (the block mean). A block that is not exactly 16 entries, carries a non-accelerometer tag, or is read more than 500 us late is discarded and counted, so a missed interrupt shows up as a sample gap rather than a wrong number. The boxcar average adds 0.28 ms of deterministic delay (about 0.7 degrees at 390 RPM), the same class as the old LIS2DW12 filter lag and absorbed by the same calibration. The optical comparator input is GPIO35 and the status LED GPIO37. Emitter GPIO36 is a 20 kHz, 10 percent LEDC PWM when the TR-VERT profile is active and 0 otherwise; the receiver's synchronous detector uses the same pulse. The IIS3DWB has no wake-on-motion, so deep sleep wakes on EXT1 when MAG_TACH (GPIO1) or the acquire button (GPIO5) pulses low; both must stay on RTC GPIOs 0-21 for EXT1 to arm; the optical profile has no wake source while its emitter is off, which is fine because flight logging uses MR-VERT. The vendored driver is `vendor/iis3dwb_reg.c` (see UPSTREAM.txt); the LIS2DW12 driver is gone.

## Build and flash

Pinned platform: PlatformIO `espressif32@6.12.0`, ESP-IDF 5.5 family. The generic `esp32-s3-devkitc-1` board definition is used deliberately, with flash size (16 MB), PSRAM mode (quad) and console pinned in `platformio.ini` and `sdkconfig.defaults`; actual GPIOs are set for the carrier schematic in `src/board.hpp`. `esp_lcd` is excluded in `CMakeLists.txt`: it is unused, and xtensa GCC 14.2.0 segfaults compiling it. DIO flash is selected conservatively. The unmodified ST driver is vendored at a recorded commit with its license.

From this directory, using Python 3.11:

```powershell
python -m pip install platformio
python -m platformio run
python -m platformio run --target upload --upload-port COM5
```

The carrier build compiles cleanly (verified 2026-09-23, PlatformIO 6.2.0: RAM 15.7%, flash 22.8% of the 3 MB app partition, no warnings in project sources). `tools/package_release.py` copies the images from `.pio/build/balancercarrier`, a manifest and flashing instructions into `release/`.

Replace COM5 with the FeatherS3[D]'s native USB port. On first flash: hold BOOT on the module, tap RST, release BOOT, then upload. Reset once after flashing if it remains in download mode. The module powers and programs from USB with no battery, and charges the cell in hardware regardless of firmware.

Do not flash a whole merged image over an existing board if you intend to preserve its settings without first reviewing the image's NVS region. Normal PlatformIO upload leaves the NVS partition intact. No device has been flashed during development here.

## Controls

- Short acquire-button press: start a timed run; during a run, cancel it. Cancelled results are explicitly invalid.
- Hold acquire for two seconds while idle: switch MR-VERT/TR-VERT and save the profile. A hold during acquisition does not change profile.
- MR-VERT: optical emitter OFF; magnetic conditioner leading **falling** edge.
- TR-VERT: optical emitter ON, including idle; optical comparator **rising** edge as reflection pulls OPT_RAW down.
- One selected edge per revolution is assumed. Multiple teeth, multiple tape patches, or extra reflections must be corrected at the test setup; automatic harmonics identification is not implemented.
- LED: 2 Hz blink acquiring; solid after a stable run; fast blink for fault/poor quality; short periodic pulse while idle (faster heartbeat when BLE connected).

Sensor/sampling runs continuously so each acquisition begins with an already settled filter. A profile or configuration change requires idle state. The optical emitter follows the selected profile, so use MR-VERT or switch OFF when finished testing to conserve battery.

## USB or BLE commands

USB uses UTF-8 JSON, one object per newline, 115200 nominal baud. BLE advertises **BalancerREF** using Nordic UART Service:

| Function | UUID |
|---|---|
| Service | `6e400001-b5a3-f393-e0a9-e50e24dcca9e` |
| RX: write with response | `6e400002-b5a3-f393-e0a9-e50e24dcca9e` |
| TX: subscribe to notifications | `6e400003-b5a3-f393-e0a9-e50e24dcca9e` |

Each BLE write contains one complete JSON command, at most 255 bytes. Negotiate a sufficient MTU or use a client supporting long writes; small commands work at the default MTU. Results are fragmented to the negotiated MTU, at most 180 bytes per notification, and end with newline. Reassemble bytes through newline before decoding JSON; discard malformed/truncated lines. A dropped line is not a measurement. Disconnecting does not stop acquisition, but notifications are not replayed; `history` retains the last 20 stable results per profile in RAM. Settings persist across reboot, history does not. BLE has no pairing/authentication in this bench revision and accepts commands from its one connected client.

```json
{"cmd":"status"}
{"cmd":"profile","value":"TR-VERT"}
{"cmd":"config","axis":"Z","sign":1}
{"cmd":"start"}
{"cmd":"start","continuous":true}
{"cmd":"stop"}
{"cmd":"history"}
```

### Continuous acquisition

`{"cmd":"start","continuous":true}` acquires back to back: each `duration_s` window ends with a `result` and the next window begins immediately, with no settling gap because sampling never stops. Every result and status carries `continuous` and a `sequence` counter (1 for the first window of a session) so a client can detect a missed notification. Each window is an independent coherent average over its own revolutions; nothing is averaged across windows, and only stable windows enter `history`. The session ends on `stop`, on a short acquire-button press, or if the sensor fails; `stop` cancels the window in progress and returns it as a final result flagged `2048` (cancelled, invalid). Configuration, profile and history commands are refused for the whole session, exactly as during a single run. A single `start` without the flag behaves as before.

Select X/Y/Z only after matching package/PCB orientation to vertical. The `sign` setting maps the chosen sensor direction to positive up. A static orientation check can establish sign; it does not calibrate dynamic IPS or chart phase.

Configuration updates affect only the active profile, are checked before application, and commit atomically through NVS. A failed save keeps the prior active configuration. Unknown/duplicate keys, nonfinite numbers, and out-of-range values are rejected. Supplying `axis` explicitly confirms it. Configuration changes clear that profile's RAM history to avoid comparing incompatible settings.

| Key | Default | Accepted values |
|---|---:|---|
| `axis` | Z, unconfirmed | X, Y, Z |
| `sign` | +1 | +1 or -1 |
| `gain` | 1 | 0.1–10 |
| `phase_direction` | +1 | +1 or -1 |
| `phase_offset_deg` | 0 | -360–360 |
| `duration_s` | 12 | 6–30 |
| `min_rpm` | 120 | at least 120, below max_rpm |
| `max_rpm` | 6000 | at most 6000, above min_rpm |

Limit the RPM range to the test regime where a saved calibration was established. A constant phase offset is not assumed valid over all speeds. Configuration values are user-entered transforms, not evidence of calibrated accuracy.

## What IPS and phase mean here

The IIS3DWB runs at its fixed **26.667 kHz ODR, fixed +/-16 g, LPF2 ODR/10**, decimated by 16 in firmware to **1666.7 Hz** measurement samples (see the Carrier hardware section). Full scale, batch rate and FIFO mode are read back after configuration. SPI at 10 MHz.

The range is fixed at +/-16 g and never switched during a session, so no run can mix differently scaled samples. DS12569 states noise density is independent of full scale; at 0.488 mg/LSB the step is about 1/28 of the ~3.9 mg RMS per-sample noise, so the wide range costs no usable resolution (0.08 IPS at 300 RPM is ~6.5 mg peak). Clipping is judged on every raw FIFO sample before the 16-sample average, at 95% of full scale because LPF2 can round a saturated peak slightly low, and is tracked per axis. The per-revolution fit models DC and 1..4/rev together so strong 2/rev content does not leak into the 1/rev vector. Each tach edge is held until the first sample at or after it arrives, because a block's mean timestamp can precede an edge that was delivered first.

The two tachs and the FIFO-watermark line are captured by three channels of one MCPWM capture timer. ISR code only queues timestamps. A priority-22 task reads the sensor; analysis and USB/BLE use separate lower-priority tasks. Delayed sensor reads (>500 microseconds after the ISR timestamp), queue overflows, missing samples, and read failures invalidate the acquisition. Hardware timestamps do not remove the accelerometer's internal filter delay or an interrupt serviced too late; both are bench checks.

For each complete revolution, each axis is least-squares fitted to `DC + C*cos(theta) + S*sin(theta)` using sample angles interpolated between the actual bounding tach edges. DC/gravity is retained separately. This extracts the synchronous **1/rev component**, not overall broadband vibration. The three axes remain separate; vertical is not an XYZ vector magnitude.

For sinusoidal 1/rev motion, `velocity_peak = acceleration_peak / (2*pi*RPM/60)`. Acceleration is converted from g to inches/s². Velocity coefficients are integrated with the corresponding 90-degree phase shift. Peak IPS and RMS IPS are both output; for this fitted sinusoid RMS=peak/sqrt(2). There is no assumed MicroVib peak/RMS convention.

**Raw phase** means degrees of elapsed rotation from the selected tach edge to the positive velocity peak, increasing with time: `v(theta)=Vpeak*cos(theta-phase)`. It is not automatically a clock position on the manufacturer's balance chart. Signed acceleration phase is also included to distinguish acceleration and velocity conventions.

The adjusted outputs apply:

```
ips_peak = raw_axis_ips_peak * gain
ips_rms = ips_peak / sqrt(2)
signed_phase = wrap(raw_axis_velocity_phase + (sign < 0 ? 180 : 0))
adjusted_phase = wrap(phase_direction * signed_phase + phase_offset_deg)
```

Raw XYZ magnitudes/phases remain unchanged in every result. No 30-degree or two-o'clock geometric correction is silently inserted. Your provided rotor/weight information is preserved in `config/tail-rotor-reference.json` as user-supplied metadata for future reference visualization; it is not compiled into a correction algorithm.

## Reading quality flags

`valid` means no detected hard acquisition fault, not calibrated accuracy. `stable` additionally requires confirmed axis, period CV <=2%, and reasonably consistent per-revolution vibration vectors. `phase_valid` additionally requires a usable amplitude. `quality` summarizes the result:

- `stable_vector` (`phase_valid`): amplitude and phase both repeat. Only these runs feed run-to-run delta and the `compare` calibration.
- `direction_only` (`direction_valid` but not `stable`): phase repeats per revolution but amplitude varies (flag 128 without 4096). The phase is published for a rough correction; the amplitude must not be used for calibration or a final acceptance decision.
- `unreliable`: a hard fault (including selected-axis overrange), bad tach, unconfirmed axis, weak signal, or inconsistent angle (flag 4096). The adjusted phase is JSON null.

`raw_amplitude_scatter_ips_peak` and `per_rev_phase_scatter_deg` split `raw_vector_scatter_ips_peak` into its along-vector and across-vector parts. Each axis in `raw_axes` reports `clipped`; clipping on an unused axis is reported but does not invalidate the run. Raw values remain available for diagnosis and must be considered together with the flags.

| Bit | Meaning |
|---:|---|
| 1 | Missing/stale/out-of-range tach |
| 2 | Fewer than 8 usable complete revolutions |
| 4 | Sample gap, inconsistent sample count, or buffer capacity exceeded |
| 8 | Selected axis reached 95% of +/-16 g on any raw sample, including gravity (message: overrange) |
| 16 | Sensor I2C error |
| 32 | Capture or sample queue overflow |
| 64 | RPM period variation >2% |
| 128 | Vibration vector scatter (amplitude and phase combined) >20% of coherent amplitude, with 0.005 IPS floor |
| 256 | Weak phase: amplitude below 0.005 IPS or insufficient relative to measured vector scatter |
| 512 | Vertical axis not explicitly confirmed |
| 1024 | Late sample read, invalid time ordering, or degenerate fit |
| 2048 | Run cancelled |
| 4096 | Phase unstable: across-vector per-revolution scatter >20% of coherent amplitude (about 11 degrees), with 0.005 IPS floor |

Scatter is a repeatability metric, not a calibrated noise floor or statistical accuracy interval. There is no universal accept/reject balancing threshold. A periodic interference or extra tach pattern can be consistent yet wrong. The +/-16 g range includes static gravity: a clipped selected axis always invalidates the run and is never reported as a lower IPS result. Run-to-run delta is provided only for stable runs within 2% RPM under the same profile settings; the operator must also maintain the same physical mounting.

## In-flight logging (flight mode)

`{"cmd":"flight","value":true}` turns the puck into an autonomous logger; the setting persists and survives sleep. On every boot or wake in flight mode it starts continuous acquisition on the active profile, tags each window with the latest GPS fix, appends one terse JSON line per window to the `storage` SPIFFS partition (about 4.9 MB, roughly 16,000 windows), and never overwrites: once the partition passes 95 percent it stops recording and `status` reports `log.full`. BLE is not started in flight mode. The acquire button is inert; hold it two seconds to change profile only while idle. `{"cmd":"flight","value":false}` returns to bench behaviour (BLE comes back after a reboot).

**USB rules.** A USB data connection pauses autonomous acquisition and blocks sleep so the puck can be commanded and downloaded; unplugging resumes. A plain charger does not enumerate and does not pause it.

**Sleep.** After 3 minutes without a tach edge (and at least 3 minutes awake) the puck sends the GPS to backup mode, powers the IIS3DWB down and enters deep sleep armed on EXT1 (MAG_TACH GPIO1 or the acquire button GPIO5 going low). Rotor spin-up on the magnetic pickup or a button press wakes it; handling alone does not. The LM1815 stays powered, so sleep current is dominated by it (a few mA); budget about 260 mAh for a day of two flight hours plus eight dormant hours. Wake cause is written as a `boot` record and shown in `status.wake`.

**Level-flight gate.** Each record carries `lvl`, true only when the window was `stable`, at least 3 valid fixes arrived, mean ground speed was at least 2 m/s, speed spread was at most 1.5 m/s, circular course spread at most 10 degrees, and the sign-adjusted vertical DC was within 6 percent of 1 g. Turns, climbs, descents, hover and ground runs therefore log with `lvl:false` and can be filtered out. GPS gives ground speed, not airspeed; fly reciprocal headings if wind matters.

**Record format**, one line each, raw uncalibrated values:

```json
{"type":"log","seq":12,"run":40,"t":"2026-09-07T18:02:11Z","up":812345,"prof":"MR-VERT","ax":"Z","sg":1,"v":true,"s":true,"pv":true,"f":0,"rpm":388.20,"cv":0.0031,"m":[0.0120,0.0210,0.2345],"p":[10.0,20.0,123.4],"dc":[0.010,-0.020,0.998],"sc":0.0120,"fix":true,"lat":40.123456,"lon":-111.123456,"gs":20.30,"crs":84.0,"alt":1400.0,"sat":9,"lvl":true,"nfix":6,"gsm":20.30,"gss":0.60,"css":2.1}
{"type":"boot","t":null,"up":15,"note":"wake:motion"}
```

`m`/`p`/`dc` are per-axis X, Y, Z peak IPS, velocity phase in degrees and DC in g; `sc` is vector scatter; `gsm`/`gss`/`css` are the gate's mean speed, speed spread and course spread; `t` is GPS UTC or null before a fix. Flags `f` are the same bits as bench results.

**Download and erase.** `{"cmd":"download"}` streams `download_begin`, every stored line unchanged, then `download_end` with `complete` and the record count; a truncated last line from a power loss is skipped. `{"cmd":"erase"}` deletes the log and is never implied by a download. Both are refused while acquiring, so in flight mode plug in USB first. From the laptop:

```powershell
python tools/puck.py --port COM5 --flight on
python tools/puck.py --port COM5 --download flight.jsonl
python tools/puck.py --port COM5 --erase
```

The tool refuses to report success, and tells you not to erase, if the received count differs from the puck's.

**GPS.** J4 on the schematic: UART1, GPIO10 TX to module RX, GPIO7 RX from module TX, GPIO6 PPS (wired, unused by firmware), 3.3 V from the FeatherS3[D]'s LDO2 (enabled by firmware), 8N1 NMEA. Only RMC, which carries speed and course, feeds the level-flight gate, once per epoch; a GGA reporting no fix clears the fix so a lost RMC stream cannot leave a stale position counted as current. The reader auto-detects 38400 (u-blox M10/F10 default) or 9600 (Quectel L76-K, u-blox M8) by cycling every 4 s until checksum-valid sentences arrive; `status.gps.baud` shows the rate in use. Sleep sends both UBX-RXM-PMREQ (u-blox backup, wake on UART) and `$PMTK161,0` (Quectel standby, wake on any byte); each vendor ignores the other. Candidate modules: u-blox NEO-F10N (Digi-Key 672-NEO-F10N-00B-TR-ND is the bare LCC module and needs a carrier with an L1/L5 antenna path; the SparkFun NEO-F10N breakout is the drop-in form) or Quectel L76-K (2.7-3.4 V, internal LNA, passive patch antenna, about 25 mA tracking, roughly 0.5 mA in standby; the Waveshare L76K breakout brings out VCC/GND/TX/RX/PPS). RMC and GGA from any talker are parsed with checksum verification; `status.gps` reports presence, fix, satellites, speed and rejected sentences. Backup mode uses UBX-RXM-PMREQ and wakes on UART activity, which the firmware sends at boot; a non-u-blox module will simply ignore the sleep request and keep drawing its normal current. PPS is not used yet.

Nothing in this mode has run on hardware. Bench checks before trusting a flight log: GPS sentences appear in `status`, a window logs with a plausible `t`, sleep entry and motion wake, resume after USB unplug, and that `lvl` goes false when the puck is carried around by hand.

## MicroVib comparison and logging

Install the host tool dependencies in a virtual environment, then:

```powershell
python -m pip install -r tools/requirements.txt
python tools/puck.py --port COM5 --command '{"cmd":"config","axis":"Z","sign":1}'
python tools/puck.py --port COM5 --profile TR-VERT --acquire --log tail-runs.jsonl
python tools/puck.py --ble --profile MR-VERT --acquire --log main-runs.jsonl
python tools/puck.py --ble --acquire --continuous --runs 10 --log series.jsonl
```

`--continuous` collects `--runs` results (0 = until Ctrl+C) and then sends `stop`, logging the final cancelled partial as well.

The logger appends UTC receipt times around the untouched firmware objects. `tools/comparison-template.csv` records the reference instrument, mounting, tach, installed weights, RPM, and amplitude convention alongside a puck run. Pair measurements under matching conditions and repeat at multiple amplitudes/speeds. Do not assume two physically separate sensor mounts have identical response.

After a stable run, a reference comparison can propose a transform without applying it:

```json
{"cmd":"compare","reference_ips_peak":0.25,"reference_phase_deg":120}
```

These numbers are examples, not measured results. Enter peak IPS (convert RMS for the 1/rev sinusoid if necessary). A proposal reports `gain = reference_peak / raw_selected_peak` and the phase difference under the selected axis/sign/direction convention. Verify multiple paired measurements; then apply a chosen transform explicitly with `config`. A reference comparison does not establish a weight influence coefficient or authorize a maintenance balancing correction. A persistent opposite angle direction requires `phase_direction`, not merely a constant phase offset.

## Verification and first hardware checks

`tests/run_host_tests.sh` compiles and runs the exact firmware DSP code on a Linux host with GCC, AddressSanitizer and UndefinedBehaviorSanitizer. On this Windows workstation it runs under WSL. Tests cover synthetic velocity/phase recovery, DC and 2/rev rejection, raw/calibrated separation, sign/direction, timer rollover, missing samples/tach, glitches, clipping, weak signal, amplitude variation and RPM endpoints. A raw-path generator feeds int16 samples at the full 26.667 kHz ODR (gravity, 2/3-rev harmonics, datasheet noise, quantization and rail saturation) through the same `decodeBlock` and `Measurement` code across 300/500/1900/2200 RPM and 0.08/0.5/2.0 IPS, plus overrange, single-sample impacts on used and unused axes, and phase wander. `tools/sim.sh` runs the same raw-path generator (`tests/rawsim.hpp`) as a bench simulator, so vibration cases can be tried before live runs. With no arguments it runs every preset (clean, main-rotor minimum, tail-rotor maximum, heavy 2/rev, overrange, impacts, amplitude and phase wander, RPM drift, tach jitter/dropout/glitch, sample gap, weak signal, extra noise, unconfirmed axis) and checks each against its expected quality; `list` shows presets and settings; a preset name and/or `key=value` settings print one full result, e.g. `wsl sh tools/sim.sh rpm=390 ips=0.8 h2=1.2 tach_jitter=100`. It exercises the measurement code only, not task timing, SPI or the tach front end.

`tests/test_tools.py` checks fragmented transport parsing and logger protocol behavior.

Before useful rotor comparison, verify: sensor initialization and static XYZ sign; regular 1666.7 Hz FIFO-block interrupts and sub-500 us block reads with BLE active; known tach pulse frequency and single edge per revolution; injected vibration magnitude/phase over the intended RPM range; optical polarity and magnetic leading edge; button/LED operation; USB/BLE disconnects; retained settings after reset. Keep the mounting axis and measurement convention in every comparison record. No physical prototype results are claimed by software tests.

Source references: [ST IIS3DWB datasheet](https://www.st.com/resource/en/datasheet/iis3dwb.pdf), [ST driver repository](https://github.com/STMicroelectronics/iis3dwb-pid), [Espressif MCPWM capture](https://docs.espressif.com/projects/esp-idf/en/v5.5/esp32s3/api-reference/peripherals/mcpwm.html), [Espressif NimBLE](https://docs.espressif.com/projects/esp-idf/en/v5.5/esp32s3/api-reference/bluetooth/nimble/index.html). Upstream driver license/commit are included under `vendor/`.

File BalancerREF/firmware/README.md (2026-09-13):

# BalancerREF ESP32-S3 firmware

Bench-test firmware for the **BalancerREF Rev B reference puck**, ESP32-S3-MINI-1-N8, 8 MB flash, no PSRAM. It is separate from the full analyzer project. The schematic and PCB files are not changed by this firmware project. No aircraft weight corrections are automatically calculated or applied.

Implemented: MR-VERT magnetic tach, TR-VERT optical tach/emitter, all three IIS3DWB axes over SPI, hardware timestamps, finite and continuous back-to-back acquisitions, autonomous in-flight logging with GPS tagging and tach/button-wake deep sleep, approximate 1/rev velocity magnitude and phase, stability flags, run trends, BLE, native USB JSON console, persistent per-profile settings, and MicroVib comparison proposals. Wi-Fi is never initialized.

The code can check signal consistency but cannot certify IPS accuracy. Physical sampling latency, sensor frequency response, tach integrity, BLE operation, power behavior, and comparison with calibrated equipment remain hardware acceptance tests. Default gain is 1 and phase offset is 0. The provisional Z axis must be explicitly confirmed or changed before a run is marked stable.

## Hardware support status

The BQ24075 charger **is** driven, as of schematic Rev F. `board.hpp` carries the
four pins (`chgEn1`, `chgEn2`, `pgood`, `chgStat`), `tests/check_pinmap.py` verifies
them against the KiCad pin audit, and `setupCharger()` runs at boot:

- **Input current limit is set to USB500 at boot.** EN1/EN2 have 285 kOhm internal
  pull-downs, so the part powers up in USB100 - a 100 mA limit that has to cover
  system load *and* charge current, which an ESP32-S3 with BLE up largely consumes
  on its own. USB500 is the ceiling on purpose: 500 mA is the most a non-negotiated
  port must supply, and this board has no USB-PD or BC1.2. The resistor-programmed
  ~1.0 A setting stays a deliberate opt-in for a known wall adapter.
  SLUS810N Table 7-2 is indexed **(EN2, EN1)**, the reverse of the naming order.
- **`pgood` is the input-present signal**, and `chgStat` reports charging. Both are
  open-drain and **active low**, with 100k pull-ups on the board. `status` reports
  them as `input_present` and `charging`. `chgStat` goes high both when charging
  completes and when the charger is disabled, so it is not an input-present signal
  on its own.
- The Rev D SYS_SW-versus-BAT comparison and its divider are gone from the hardware,
  so `pgood` is the only way to detect an input. `supplyVolts()` reads the cell only
  while running on battery - while charging, OUT is driven from IN.

The rest of the firmware still targets Rev C behaviour; the sections below are
unchanged.

## Rev C hardware (firmware 0.4.0, 2026-09-09)

Firmware 0.4.0 targets schematic Rev C only. Accelerometer: ST IIS3DWB on SPI2 (GPIO14 SCK, 15 MOSI, 16 MISO, 17 CS, mode 3, 10 MHz), SPI-only per DS12569, +/-2 g, LPF2 at ODR/10 (2.67 kHz). The sensor streams its fixed 26.667 kHz ODR into its FIFO with the watermark at 16 samples; INT1 (GPIO6) is the FIFO-threshold line and is timestamped by the same MCPWM capture channel that timestamped data-ready before. Each block is read in one 112-byte SPI transfer and averaged into a single 1666.7 Hz measurement sample whose timestamp is the capture tick minus 7.5 sample periods (the block mean). A block that is not exactly 16 entries, carries a non-accelerometer tag, or is read more than 500 us late is discarded and counted, so a missed interrupt shows up as a sample gap rather than a wrong number. The boxcar average adds 0.28 ms of deterministic delay (about 0.7 degrees at 390 RPM), the same class as the old LIS2DW12 filter lag and absorbed by the same calibration. Emitter GPIO9 is a 20 kHz, 10 percent LEDC PWM when the TR-VERT profile is active and 0 otherwise; the receiver's synchronous detector uses the same pulse. The IIS3DWB has no wake-on-motion, so deep sleep wakes on EXT1 when MAG_TACH (GPIO7) or the acquire button (GPIO10) pulses low; the optical profile has no wake source while its emitter is off, which is fine because flight logging uses MR-VERT. The vendored driver is `vendor/iis3dwb_reg.c` (see UPSTREAM.txt); the LIS2DW12 driver is gone.

## Build and flash

Pinned platform: PlatformIO `espressif32@6.12.0`, ESP-IDF 5.5 family. The DevKitC N8 board definition supplies the matching processor/flash configuration; actual GPIOs are explicitly set for this custom schematic in `src/board.hpp`. DIO flash is selected conservatively. The unmodified ST driver is vendored at a recorded commit with its license.

From this directory, using Python 3.11:

```powershell
python -m pip install platformio==6.1.18
python -m platformio run
python -m platformio run --target upload --upload-port COM5
```

Firmware 0.4.0-reference compiles cleanly with this pinned toolchain (verified 2026-09-07, PlatformIO 6.1.18 from `../.venv-firmware`; 698 kB image). Earlier source had never been compiled and carried three warnings-as-errors and one driver signature mismatch, all fixed without changing behavior. `tools/package_release.py` copies the images and a manifest into `release/`.

Replace COM5 with the puck's native USB port. On first flash: switch ON, hold BOOT, press/release RESET, release BOOT, then upload. Reset once after flashing if it remains in download mode. GPIO19/20 are native USB D-/D+; BOOT is GPIO0. Rev B can power/program from USB with no battery. Charging is handled by hardware regardless of firmware or switch position. Firmware has no charger STAT input and cannot report charge completion.

Do not flash a whole merged image over an existing board if you intend to preserve its settings without first reviewing the image's NVS region. Normal PlatformIO upload leaves the NVS partition intact. No device has been flashed during development here.

## Controls

- Short acquire-button press: start a timed run; during a run, cancel it. Cancelled results are explicitly invalid.
- Hold acquire for two seconds while idle: switch MR-VERT/TR-VERT and save the profile. A hold during acquisition does not change profile.
- MR-VERT: optical emitter OFF; magnetic conditioner leading **falling** edge.
- TR-VERT: optical emitter ON, including idle; optical comparator **rising** edge as reflection pulls OPT_RAW down.
- One selected edge per revolution is assumed. Multiple teeth, multiple tape patches, or extra reflections must be corrected at the test setup; automatic harmonics identification is not implemented.
- LED: 2 Hz blink acquiring; solid after a stable run; fast blink for fault/poor quality; short periodic pulse while idle (faster heartbeat when BLE connected).

Sensor/sampling runs continuously so each acquisition begins with an already settled filter. A profile or configuration change requires idle state. The optical emitter follows the selected profile, so use MR-VERT or switch OFF when finished testing to conserve battery.

## USB or BLE commands

USB uses UTF-8 JSON, one object per newline, 115200 nominal baud. BLE advertises **BalancerREF** using Nordic UART Service:

| Function | UUID |
|---|---|
| Service | `6e400001-b5a3-f393-e0a9-e50e24dcca9e` |
| RX: write with response | `6e400002-b5a3-f393-e0a9-e50e24dcca9e` |
| TX: subscribe to notifications | `6e400003-b5a3-f393-e0a9-e50e24dcca9e` |

Each BLE write contains one complete JSON command, at most 255 bytes. Negotiate a sufficient MTU or use a client supporting long writes; small commands work at the default MTU. Results are fragmented to the negotiated MTU, at most 180 bytes per notification, and end with newline. Reassemble bytes through newline before decoding JSON; discard malformed/truncated lines. A dropped line is not a measurement. Disconnecting does not stop acquisition, but notifications are not replayed; `history` retains the last 20 stable results per profile in RAM. Settings persist across reboot, history does not. BLE has no pairing/authentication in this bench revision and accepts commands from its one connected client.

```json
{"cmd":"status"}
{"cmd":"profile","value":"TR-VERT"}
{"cmd":"config","axis":"Z","sign":1}
{"cmd":"start"}
{"cmd":"start","continuous":true}
{"cmd":"stop"}
{"cmd":"history"}
```

### Continuous acquisition

`{"cmd":"start","continuous":true}` acquires back to back: each `duration_s` window ends with a `result` and the next window begins immediately, with no settling gap because sampling never stops. Every result and status carries `continuous` and a `sequence` counter (1 for the first window of a session) so a client can detect a missed notification. Each window is an independent coherent average over its own revolutions; nothing is averaged across windows, and only stable windows enter `history`. The session ends on `stop`, on a short acquire-button press, or if the sensor fails; `stop` cancels the window in progress and returns it as a final result flagged `2048` (cancelled, invalid). Configuration, profile and history commands are refused for the whole session, exactly as during a single run. A single `start` without the flag behaves as before.

Select X/Y/Z only after matching package/PCB orientation to vertical. The `sign` setting maps the chosen sensor direction to positive up. A static orientation check can establish sign; it does not calibrate dynamic IPS or chart phase.

Configuration updates affect only the active profile, are checked before application, and commit atomically through NVS. A failed save keeps the prior active configuration. Unknown/duplicate keys, nonfinite numbers, and out-of-range values are rejected. Supplying `axis` explicitly confirms it. Configuration changes clear that profile's RAM history to avoid comparing incompatible settings.

| Key | Default | Accepted values |
|---|---:|---|
| `axis` | Z, unconfirmed | X, Y, Z |
| `sign` | +1 | +1 or -1 |
| `gain` | 1 | 0.1–10 |
| `phase_direction` | +1 | +1 or -1 |
| `phase_offset_deg` | 0 | -360–360 |
| `duration_s` | 12 | 6–30 |
| `min_rpm` | 120 | at least 120, below max_rpm |
| `max_rpm` | 6000 | at most 6000, above min_rpm |

Limit the RPM range to the test regime where a saved calibration was established. A constant phase offset is not assumed valid over all speeds. Configuration values are user-entered transforms, not evidence of calibrated accuracy.

## What IPS and phase mean here

The IIS3DWB runs at its fixed **26.667 kHz ODR, +/-2 g, LPF2 ODR/10**, decimated by 16 in firmware to **1666.7 Hz** measurement samples (see the Rev C hardware section). Full scale, batch rate and FIFO mode are read back after configuration. SPI at 10 MHz.

The two tachs and the FIFO-watermark line are captured by three channels of one MCPWM capture timer. ISR code only queues timestamps. A priority-22 task reads the sensor; analysis and USB/BLE use separate lower-priority tasks. Delayed sensor reads (>500 microseconds after the ISR timestamp), queue overflows, missing samples, and read failures invalidate the acquisition. Hardware timestamps do not remove the accelerometer's internal filter delay or an interrupt serviced too late; both are bench checks.

For each complete revolution, each axis is least-squares fitted to `DC + C*cos(theta) + S*sin(theta)` using sample angles interpolated between the actual bounding tach edges. DC/gravity is retained separately. This extracts the synchronous **1/rev component**, not overall broadband vibration. The three axes remain separate; vertical is not an XYZ vector magnitude.

For sinusoidal 1/rev motion, `velocity_peak = acceleration_peak / (2*pi*RPM/60)`. Acceleration is converted from g to inches/s². Velocity coefficients are integrated with the corresponding 90-degree phase shift. Peak IPS and RMS IPS are both output; for this fitted sinusoid RMS=peak/sqrt(2). There is no assumed MicroVib peak/RMS convention.

**Raw phase** means degrees of elapsed rotation from the selected tach edge to the positive velocity peak, increasing with time: `v(theta)=Vpeak*cos(theta-phase)`. It is not automatically a clock position on the manufacturer's balance chart. Signed acceleration phase is also included to distinguish acceleration and velocity conventions.

The adjusted outputs apply:

```
ips_peak = raw_axis_ips_peak * gain
ips_rms = ips_peak / sqrt(2)
signed_phase = wrap(raw_axis_velocity_phase + (sign < 0 ? 180 : 0))
adjusted_phase = wrap(phase_direction * signed_phase + phase_offset_deg)
```

Raw XYZ magnitudes/phases remain unchanged in every result. No 30-degree or two-o'clock geometric correction is silently inserted. Your provided rotor/weight information is preserved in `config/tail-rotor-reference.json` as user-supplied metadata for future reference visualization; it is not compiled into a correction algorithm.

## Reading quality flags

`valid` means no detected hard acquisition fault, not calibrated accuracy. `stable` additionally requires confirmed axis, period CV <=2%, and reasonably consistent per-revolution vibration vectors. `phase_valid` additionally requires a usable amplitude. The adjusted phase becomes JSON null when phase is not usable; raw values remain available for diagnosis and must be considered together with the flags.

| Bit | Meaning |
|---:|---|
| 1 | Missing/stale/out-of-range tach |
| 2 | Fewer than 8 usable complete revolutions |
| 4 | Sample gap, inconsistent sample count, or buffer capacity exceeded |
| 8 | Any accelerometer axis near +/-2 g full scale, including gravity |
| 16 | Sensor I2C error |
| 32 | Capture or sample queue overflow |
| 64 | RPM period variation >2% |
| 128 | Vibration vector scatter >20% of coherent amplitude, with 0.005 IPS floor |
| 256 | Weak phase: amplitude below 0.005 IPS or insufficient relative to measured vector scatter |
| 512 | Vertical axis not explicitly confirmed |
| 1024 | Late sample read, invalid time ordering, or degenerate fit |
| 2048 | Run cancelled |

Scatter is a repeatability metric, not a calibrated noise floor or statistical accuracy interval. There is no universal accept/reject balancing threshold. A periodic interference or extra tach pattern can be consistent yet wrong. The +/-2 g range includes static gravity: larger vibration can clip and must not be interpreted as a lower IPS result. Run-to-run delta is provided only for stable runs within 2% RPM under the same profile settings; the operator must also maintain the same physical mounting.

## In-flight logging (flight mode)

`{"cmd":"flight","value":true}` turns the puck into an autonomous logger; the setting persists and survives sleep. On every boot or wake in flight mode it starts continuous acquisition on the active profile, tags each window with the latest GPS fix, appends one terse JSON line per window to the `storage` SPIFFS partition (about 4.9 MB, roughly 16,000 windows), and never overwrites: once the partition passes 95 percent it stops recording and `status` reports `log.full`. BLE is not started in flight mode. The acquire button is inert; hold it two seconds to change profile only while idle. `{"cmd":"flight","value":false}` returns to bench behaviour (BLE comes back after a reboot).

**USB rules.** A USB data connection pauses autonomous acquisition and blocks sleep so the puck can be commanded and downloaded; unplugging resumes. A plain charger does not enumerate and does not pause it.

**Sleep.** After 3 minutes without a tach edge (and at least 3 minutes awake) the puck sends the GPS to backup mode, powers the IIS3DWB down and enters deep sleep armed on EXT1 (MAG_TACH GPIO7 or the acquire button GPIO10 going low). Rotor spin-up on the magnetic pickup or a button press wakes it; handling alone does not. The LM1815 stays powered, so sleep current is dominated by it (a few mA); budget about 260 mAh for a day of two flight hours plus eight dormant hours. Wake cause is written as a `boot` record and shown in `status.wake`.

**Level-flight gate.** Each record carries `lvl`, true only when the window was `stable`, at least 3 valid fixes arrived, mean ground speed was at least 2 m/s, speed spread was at most 1.5 m/s, circular course spread at most 10 degrees, and the sign-adjusted vertical DC was within 6 percent of 1 g. Turns, climbs, descents, hover and ground runs therefore log with `lvl:false` and can be filtered out. GPS gives ground speed, not airspeed; fly reciprocal headings if wind matters.

**Record format**, one line each, raw uncalibrated values:

```json
{"type":"log","seq":12,"run":40,"t":"2026-09-07T18:02:11Z","up":812345,"prof":"MR-VERT","ax":"Z","sg":1,"v":true,"s":true,"pv":true,"f":0,"rpm":388.20,"cv":0.0031,"m":[0.0120,0.0210,0.2345],"p":[10.0,20.0,123.4],"dc":[0.010,-0.020,0.998],"sc":0.0120,"fix":true,"lat":40.123456,"lon":-111.123456,"gs":20.30,"crs":84.0,"alt":1400.0,"sat":9,"lvl":true,"nfix":6,"gsm":20.30,"gss":0.60,"css":2.1}
{"type":"boot","t":null,"up":15,"note":"wake:motion"}
```

`m`/`p`/`dc` are per-axis X, Y, Z peak IPS, velocity phase in degrees and DC in g; `sc` is vector scatter; `gsm`/`gss`/`css` are the gate's mean speed, speed spread and course spread; `t` is GPS UTC or null before a fix. Flags `f` are the same bits as bench results.

**Download and erase.** `{"cmd":"download"}` streams `download_begin`, every stored line unchanged, then `download_end` with `complete` and the record count; a truncated last line from a power loss is skipped. `{"cmd":"erase"}` deletes the log and is never implied by a download. Both are refused while acquiring, so in flight mode plug in USB first. From the laptop:

```powershell
python tools/puck.py --port COM5 --flight on
python tools/puck.py --port COM5 --download flight.jsonl
python tools/puck.py --port COM5 --erase
```

The tool refuses to report success, and tells you not to erase, if the received count differs from the puck's.

**GPS.** J4 on the schematic: UART1, GPIO1 TX to module RX, GPIO2 RX from module TX, GPIO13 PPS (wired, unused by firmware), 3.3 V, 8N1 NMEA. The reader auto-detects 38400 (u-blox M10/F10 default) or 9600 (Quectel L76-K, u-blox M8) by cycling every 4 s until checksum-valid sentences arrive; `status.gps.baud` shows the rate in use. Sleep sends both UBX-RXM-PMREQ (u-blox backup, wake on UART) and `$PMTK161,0` (Quectel standby, wake on any byte); each vendor ignores the other. Candidate modules: u-blox NEO-F10N (Digi-Key 672-NEO-F10N-00B-TR-ND is the bare LCC module and needs a carrier with an L1/L5 antenna path; the SparkFun NEO-F10N breakout is the drop-in form) or Quectel L76-K (2.7-3.4 V, internal LNA, passive patch antenna, about 25 mA tracking, roughly 0.5 mA in standby; the Waveshare L76K breakout brings out VCC/GND/TX/RX/PPS). RMC and GGA from any talker are parsed with checksum verification; `status.gps` reports presence, fix, satellites, speed and rejected sentences. Backup mode uses UBX-RXM-PMREQ and wakes on UART activity, which the firmware sends at boot; a non-u-blox module will simply ignore the sleep request and keep drawing its normal current. PPS is not used yet.

Nothing in this mode has run on hardware. Bench checks before trusting a flight log: GPS sentences appear in `status`, a window logs with a plausible `t`, sleep entry and motion wake, resume after USB unplug, and that `lvl` goes false when the puck is carried around by hand.

## MicroVib comparison and logging

Install the host tool dependencies in a virtual environment, then:

```powershell
python -m pip install -r tools/requirements.txt
python tools/puck.py --port COM5 --command '{"cmd":"config","axis":"Z","sign":1}'
python tools/puck.py --port COM5 --profile TR-VERT --acquire --log tail-runs.jsonl
python tools/puck.py --ble --profile MR-VERT --acquire --log main-runs.jsonl
python tools/puck.py --ble --acquire --continuous --runs 10 --log series.jsonl
```

`--continuous` collects `--runs` results (0 = until Ctrl+C) and then sends `stop`, logging the final cancelled partial as well.

The logger appends UTC receipt times around the untouched firmware objects. `tools/comparison-template.csv` records the reference instrument, mounting, tach, installed weights, RPM, and amplitude convention alongside a puck run. Pair measurements under matching conditions and repeat at multiple amplitudes/speeds. Do not assume two physically separate sensor mounts have identical response.

After a stable run, a reference comparison can propose a transform without applying it:

```json
{"cmd":"compare","reference_ips_peak":0.25,"reference_phase_deg":120}
```

These numbers are examples, not measured results. Enter peak IPS (convert RMS for the 1/rev sinusoid if necessary). A proposal reports `gain = reference_peak / raw_selected_peak` and the phase difference under the selected axis/sign/direction convention. Verify multiple paired measurements; then apply a chosen transform explicitly with `config`. A reference comparison does not establish a weight influence coefficient or authorize a maintenance balancing correction. A persistent opposite angle direction requires `phase_direction`, not merely a constant phase offset.

## Verification and first hardware checks

`tests/run_host_tests.sh` compiles and runs the exact firmware DSP code on a Linux host with GCC, AddressSanitizer and UndefinedBehaviorSanitizer. On this Windows workstation it runs under WSL. Tests cover synthetic velocity/phase recovery, DC and 2/rev rejection, raw/calibrated separation, sign/direction, timer rollover, missing samples/tach, glitches, clipping, weak signal, amplitude variation and RPM endpoints. `tests/test_tools.py` checks fragmented transport parsing and logger protocol behavior.

Before useful rotor comparison, verify: sensor initialization and static XYZ sign; regular 1666.7 Hz FIFO-block interrupts and sub-500 us block reads with BLE active; known tach pulse frequency and single edge per revolution; injected vibration magnitude/phase over the intended RPM range; optical polarity and magnetic leading edge; button/LED operation; USB/BLE disconnects; retained settings after reset. Keep the mounting axis and measurement convention in every comparison record. No physical prototype results are claimed by software tests.

Source references: [ST IIS3DWB datasheet](https://www.st.com/resource/en/datasheet/iis3dwb.pdf), [ST driver repository](https://github.com/STMicroelectronics/iis3dwb-pid), [Espressif MCPWM capture](https://docs.espressif.com/projects/esp-idf/en/v5.5/esp32s3/api-reference/peripherals/mcpwm.html), [Espressif NimBLE](https://docs.espressif.com/projects/esp-idf/en/v5.5/esp32s3/api-reference/bluetooth/nimble/index.html). Upstream driver license/commit are included under `vendor/`.

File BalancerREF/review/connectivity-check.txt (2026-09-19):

PASS: 49 exact circuit nets; 288 pin endpoints; 140 IC pads; 30 documented unused pins.

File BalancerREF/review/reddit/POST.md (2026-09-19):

# Draft follow-up for r/PCB "Design and Board Review" (thread 1wjh9hl)

Draft, 2026-09-19, written from the repo docs for the Rev G sheet. Paste-ready but
check it reads like you before posting. Images to attach are in this folder:
`HOBOVibe-RevG-full-sheet.png`, `01`..`05` block crops, `board-main-top.png`,
`board-main-bottom.png`, `board-head-top.png`.

## Replies to the first round

**Sand-Junior** (U9 float, D3 backwards, USB through the ESD IC): all three were
right and are fixed in Rev G. D3 was drawn cathode-to-GND, which would have clamped
VBUS through a forward diode; the SMF5.0A is unidirectional and the design notes had
it down as bidirectional, which is how it survived review. The SRV05-4 now has D-
in on pin 1 / out on pin 6 and D+ in on pin 3 / out on pin 4 (same net both ends, the
part has no internal I/O path, the trace makes the through-connection). U9's
OPT_COMP input comes from the optical head over a cable and floated whenever the head
was unplugged; it now has a 100k pull-down.

**z2amiller** (DPI, two-sided assembly): new images at 400/600 DPI. Your read of the
assembly was right: every IC, connector, switch and test point is on the front (32
parts) and the back is 0603 resistors and capacitors plus one SOT-23 (41 parts). The
exceptions are the switching-loop caps and inductor for the buck-boost and the
charger's input caps, which sit on the front next to their pins. The head board is
single-sided. Plan is PCBA or hotplate the front and hand-solder the back.

**Sam__** (explain each section): below.

## What it is

A rotor track-and-balance instrument for RC helicopters: a 50 x 50 mm "puck" that
straps to the frame and a separate 25 x 50 mm optical tach head. It reports RPM,
1/rev vibration magnitude and phase, over BLE or USB. It is meant for troubleshooting
and trend-watching, not as a replacement for calibrated balancing gear, and nothing
has been bench-validated yet. Second PCB, so please assume nothing is obvious to me.

Two measurement profiles: **MR-VERT** (main rotor) uses an external two-wire
variable-reluctance pickup for the 1/rev; **TR-VERT** (tail rotor) uses the optical
head against a strip of retroreflective tape.

## Section by section (main board, Rev G)

**MCU: ESP32-S3-MINI-1 (U1).** Chosen for BLE plus native USB, and because the
module carries its own antenna and flash. USB goes straight to the module's D+/D-
through 22 R series resistors (R6/R7). The 1x05 header J4 is an optional u-blox-class
GPS (3V3, GND, RX, TX, PPS) for an in-flight logging mode. Three switches: SW1 power
slide, SW2 acquire, SW3 boot. No reset button on purpose: SW1 feeds the regulator's
VIN and EN, so the power slide already power-cycles the MCU.

**USB and power input (J1, U7, D3, U5).** USB-C receptacle with 5.1k CC pull-downs
for a UFP. SRV05-4 ESD array on D+/D- (data lines routed through it, see above) and an
SMF5.0A 5 V TVS on VBUS. The charger is a BQ24075: it has an integrated power path,
so the system is powered from USB while the cell charges independently and the puck
runs with a flat or absent pack. R3 3.57k sets about 249 mA fast charge (0.5C for the
500 mAh cell), R35 1.6k sets the ~1.0 A resistor-programmed input limit. EN1/EN2 go
to GPIOs; the part powers up in USB100 (100 mA) because both pins have internal
pull-downs, and firmware raises it to USB500 at boot. PGOOD (open drain, 100k pull-up)
is the "USB present" signal to the MCU; an earlier revision tried to infer that from
two ADC dividers and it did not work reliably. TS gets a fixed 10k because the pack
has no thermistor; CE and SYSOFF are tied low; TMR left open for the default safety
timers.

**Battery (J2, Q4).** Single-cell 500 mAh LiPo with its own protection. Q4 AO3401A is
reverse-polarity protection in the battery lead (gate to GND: body diode conducts on
first contact, then the channel).

**3.3 V rail (U6).** TPS63031 buck-boost at 2.4 MHz, because a single Li-ion cell
crosses 3.3 V during discharge and the USB case is 5 V. Input 10 u + 100 n, output
2 x 22 u, 1.5 uH inductor. SW1 sits between the charger's SYS output and the
regulator. SUPPLY_SENSE is SYS_SW/2 into GPIO12 (100k/100k, 100 nF); it reads the
cell when unplugged and the input-derived rail when charging.

**Vibration sensor (U2).** ST IIS3DWB on 4-wire SPI. It is a wideband vibration
sensor rather than a motion accelerometer: fixed 26.7 kHz ODR, flat to 6.3 kHz, so
filter phase at rotor frequencies is negligible. INT1 data-ready goes to a GPIO. The
puck mounts vertically (UP / LEFT arrows on the silk) so the stiff in-plane axis is
vertical.

**Main rotor tach (U3).** LM1815 variable-reluctance sensor interface. The VR pickup
arrives on J3 through two 10k 1206 pulse-rated resistors in series into the LM1815's adaptive-threshold input; output
pulled up to 3V3 and read by a GPIO (MAG_TACH). It is the old automotive part but it
handles the huge amplitude range of a VR sensor without a comparator threshold to
tune. Downside noted below: it draws 3.6 mA typical on the always-on rail.

**Optical tach.** Modelled on an industrial retroreflective photoelectric sensor:
pulsed emitter plus synchronous detection, so ambient light and flickering lamps
cannot coincide with the emitter windows. The analog front end lives on the separate
head board (D1 and PD1 have no leads to form, so they need their own copper on the
bracket): D1 Cree XP-E2 red LED pulsed at 20 kHz / 5 us / about 500 mA by Q1 AO3400A
through R18 3.9 R from SYS_SW, with a 100 uF local reservoir; PD1 BPW34S reverse-
biased into a 10k transimpedance stage referenced to 1.65 V (U8A TLV9062), then a x12
inverting AC-coupled gain stage (U8B); U4 TS3021 comparator against a fixed ~1.03 V
threshold with 470k hysteresis. The cut between the boards is after the comparator so
the 7-way cable carries only DC rails and digital edges. Back on the main board U9
(SN74LVC1G132 Schmitt NAND) gates the comparator output against an RC-delayed copy of
the emitter pulse (R29 1k / C26 470 pF, about 0.5 us to match receiver latency) and
U10 (SN74LVC1G123, 100k / 1 nF, about 100 us retriggerable) stretches consecutive hits
into one OPT_TACH edge per tape pass. A red acrylic window and a baffle between D1 and
PD1 are part of the mechanical design.

**Board.** 50 x 50 mm, four layers: outer signal, In1 solid GND, In2 +3V3 plane. ICs,
connectors, switches and test points on the front; passives on the back under their
IC's pins, except the switching-loop parts noted above. Three fiducials per populated
face, deliberately asymmetric. M2.5 mounting holes at the corners; the ESP32
antenna overhangs the top edge so its keepout is off the board and away from the
aluminium bracket. Net classes: 0.2 mm default, 0.5 mm power, 0.8 mm for the
buck-boost switch node. USB pair is 0.2/0.15 but not an impedance solution; the S3's
native USB is Full Speed.

## Known open items (so nobody has to find them)

- Routing is complete and DRC is clean except for three understood warnings (the
  USB-C footprint's own peg-to-pad spacing, the antenna overhang, a locally edited
  module footprint). Placement was machine-generated and then hand-adjusted, so a
  layout eye on it is welcome.
- Sleep is not low power: the LM1815 and the head's op-amp/comparator sit on the
  always-on 3V3 rail, so a sleeping puck draws milliamps.
- SW1 is rated 300 mA switching against about 180 mA steady draw with BLE bursts
  above that; accepted as reduced switch life for now.
- ERC shows 144 "endpoint off grid" warnings from two symbols sitting on a half-grid
  (U7, J1). Cosmetic, not yet cleaned up.

Full KiCad 10 project, ERC/DRC reports, pin audit and datasheet notes:
https://github.com/natehorst240-sketch/HoboBalancer

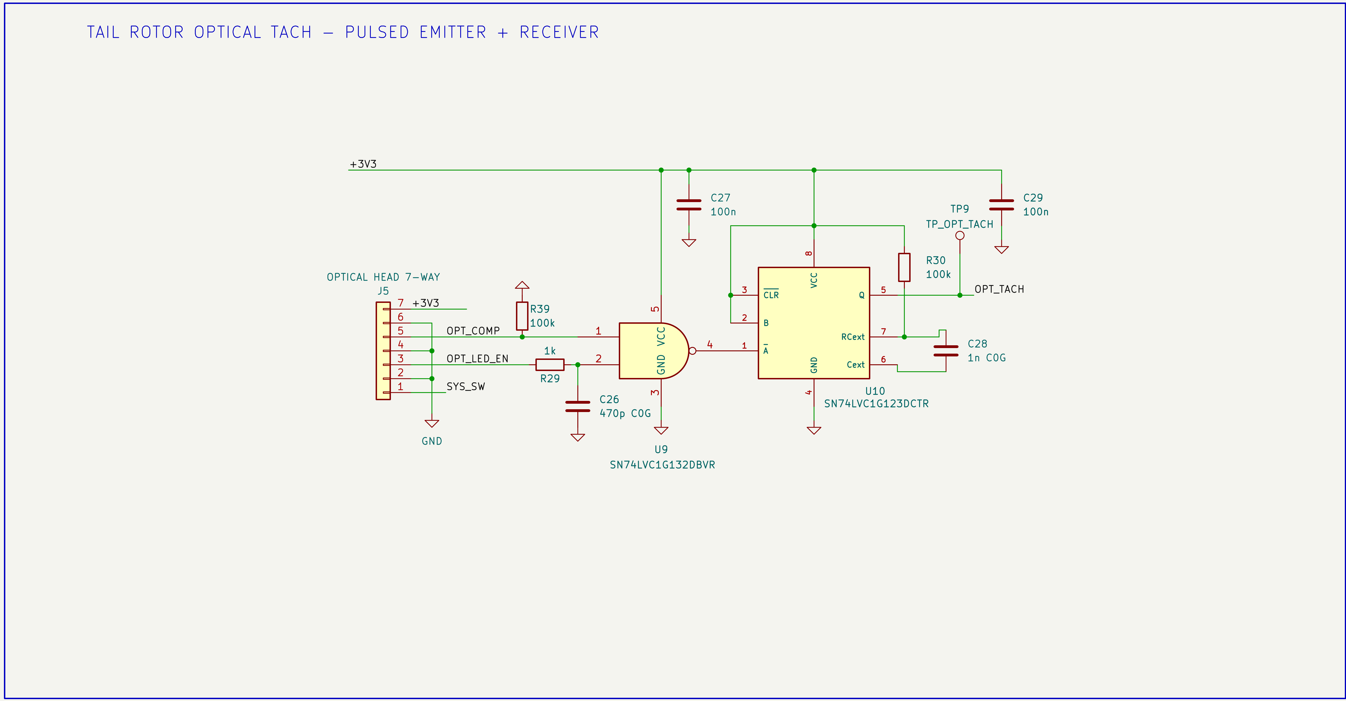
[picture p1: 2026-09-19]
BalancerREF/review/reddit/03-optical-tach.png

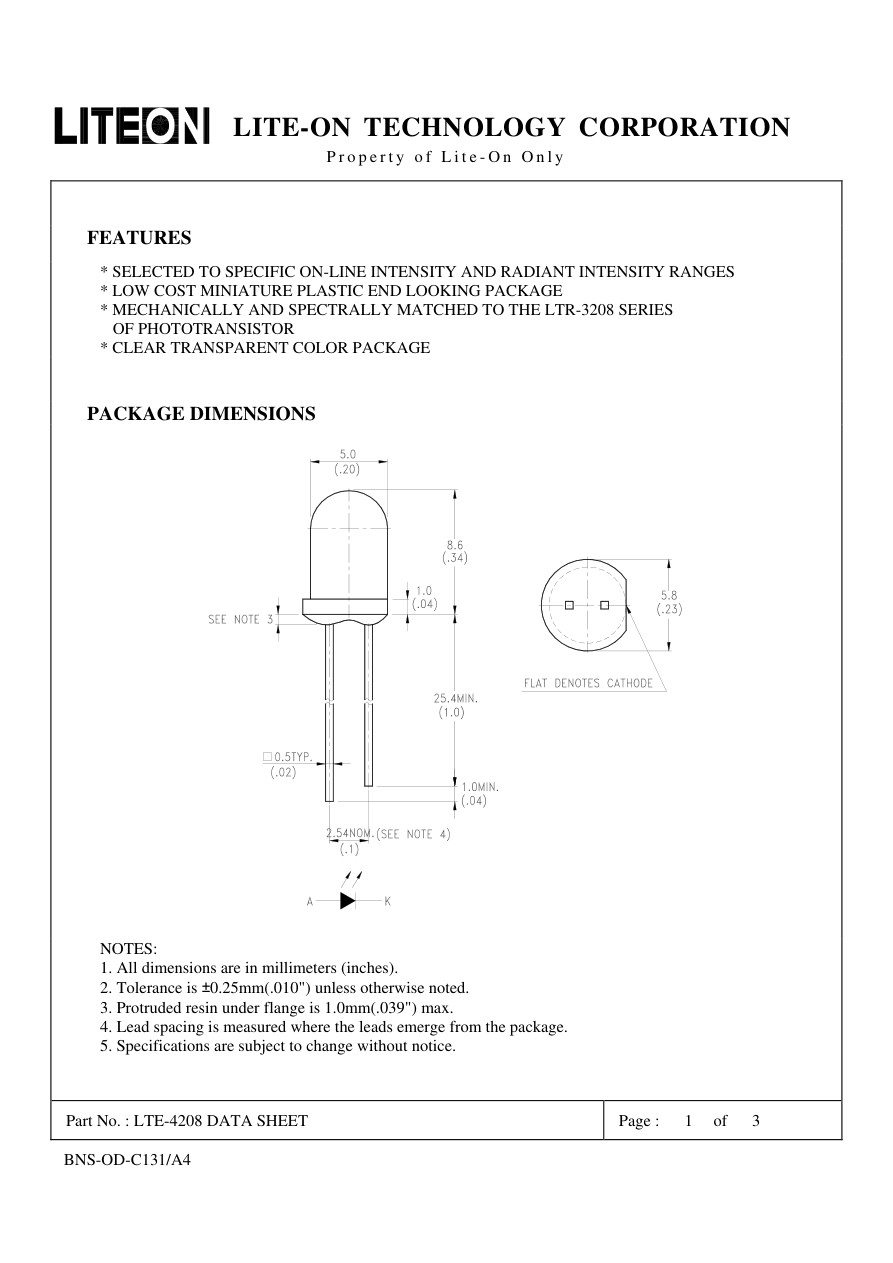
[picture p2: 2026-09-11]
BalancerREF/review/lte-pinout.png

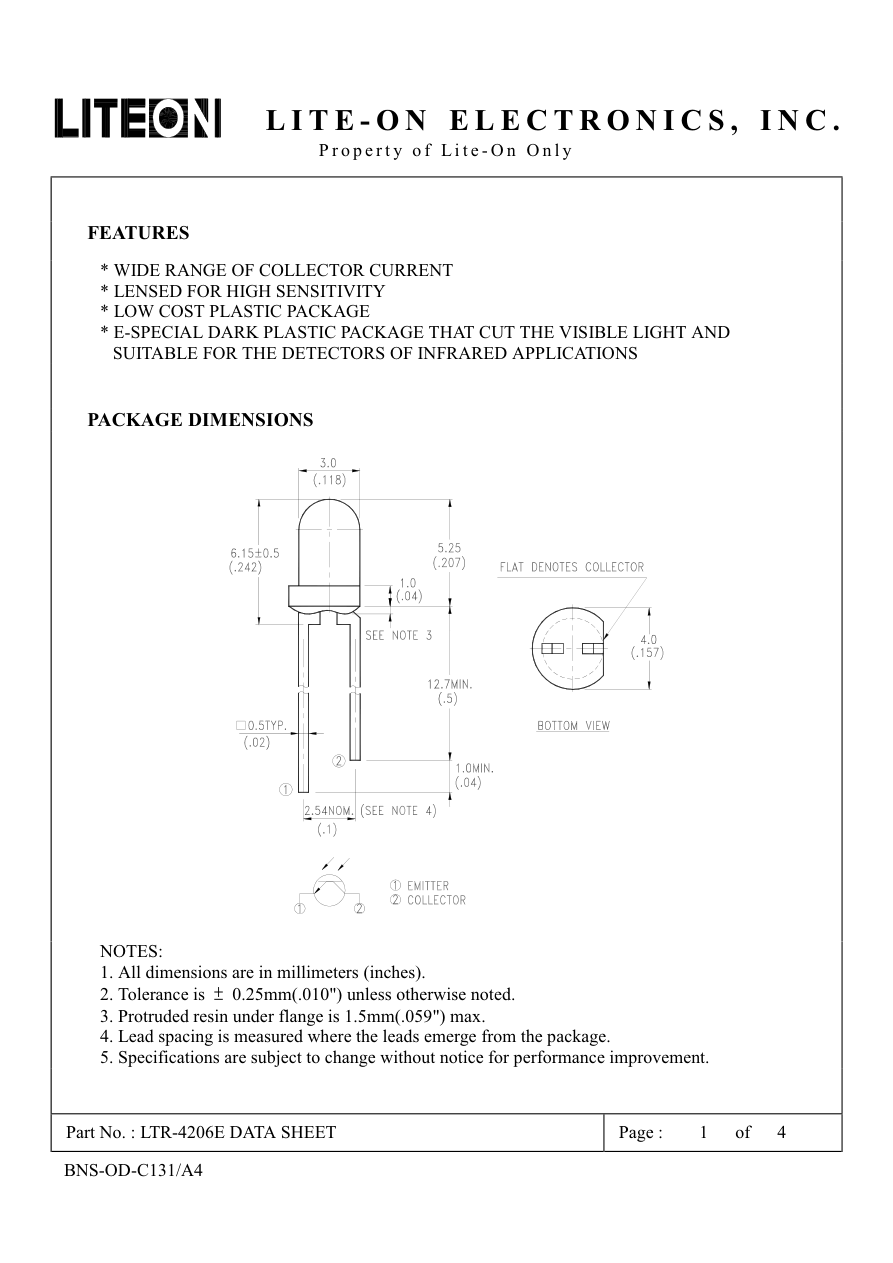
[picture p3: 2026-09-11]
BalancerREF/review/ltr-pinout.png

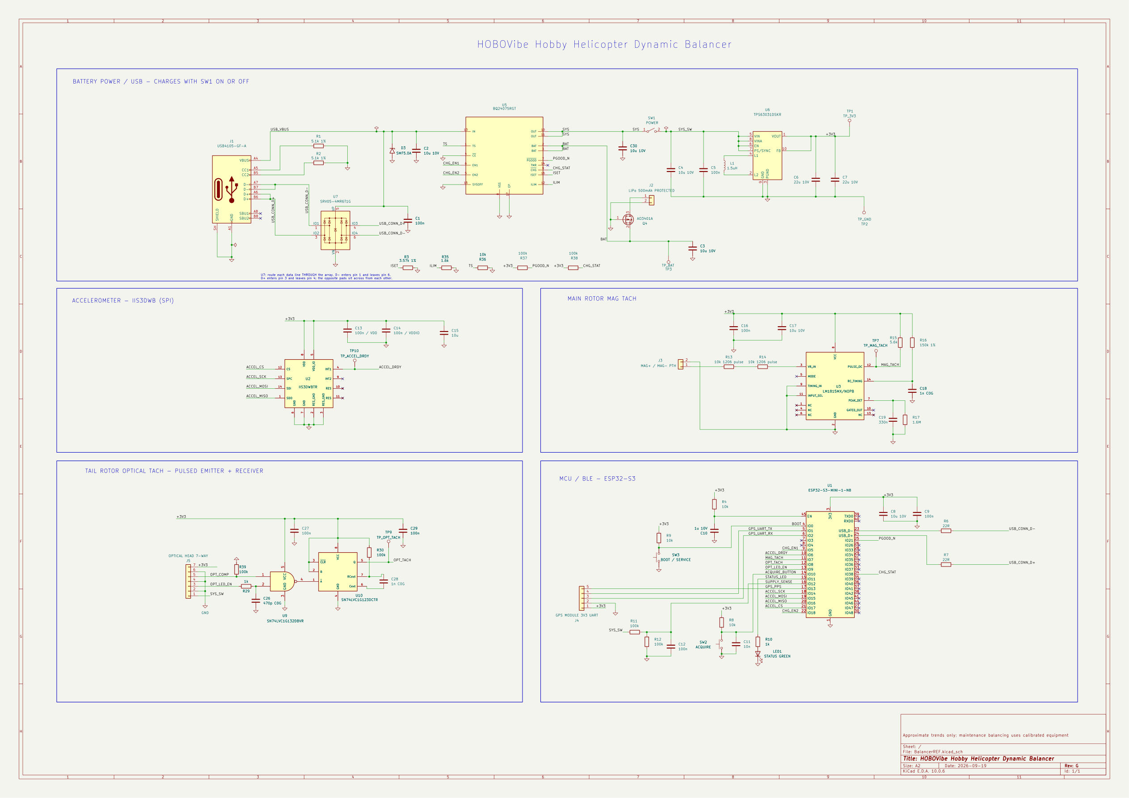
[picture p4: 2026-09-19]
BalancerREF/review/overview.png

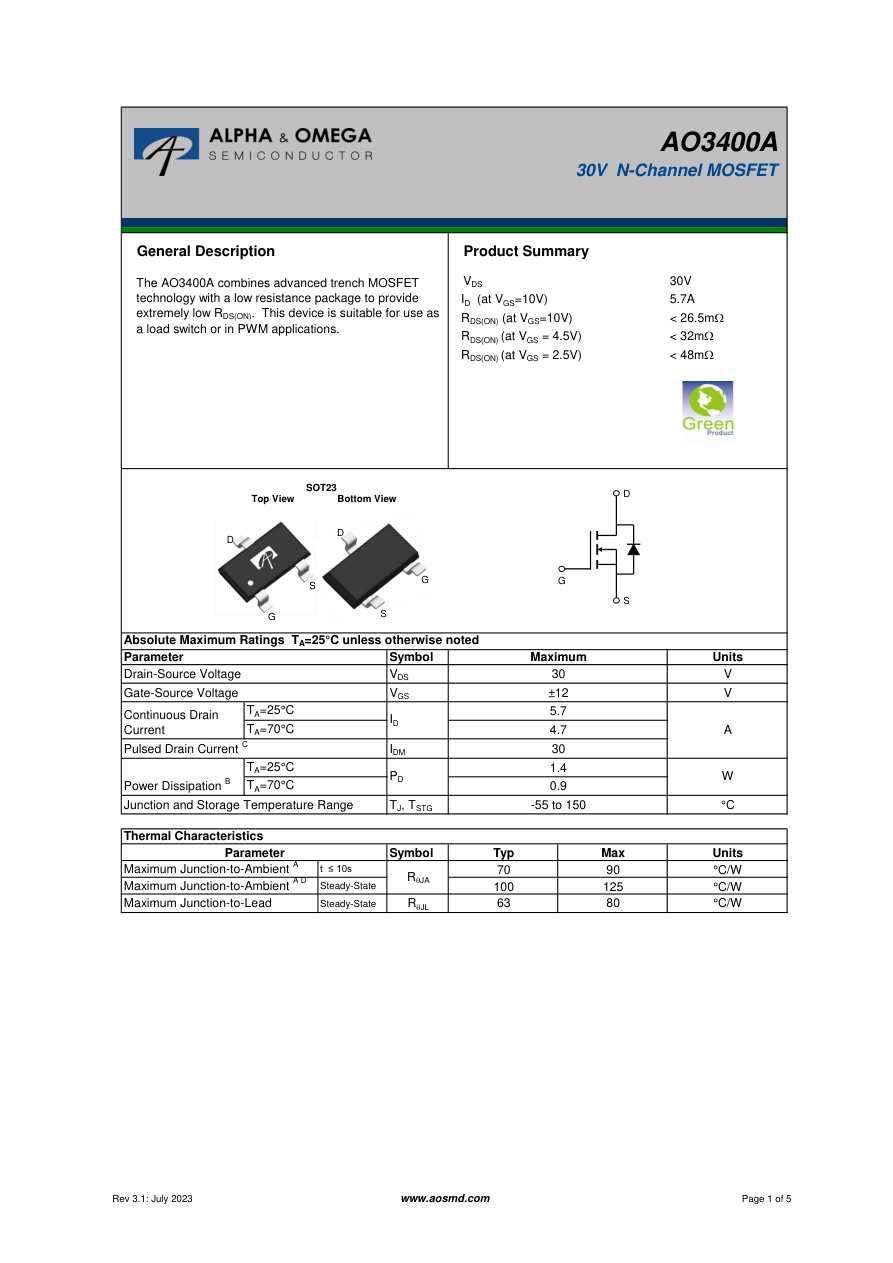
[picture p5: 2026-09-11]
BalancerREF/review/ao-pinout.png

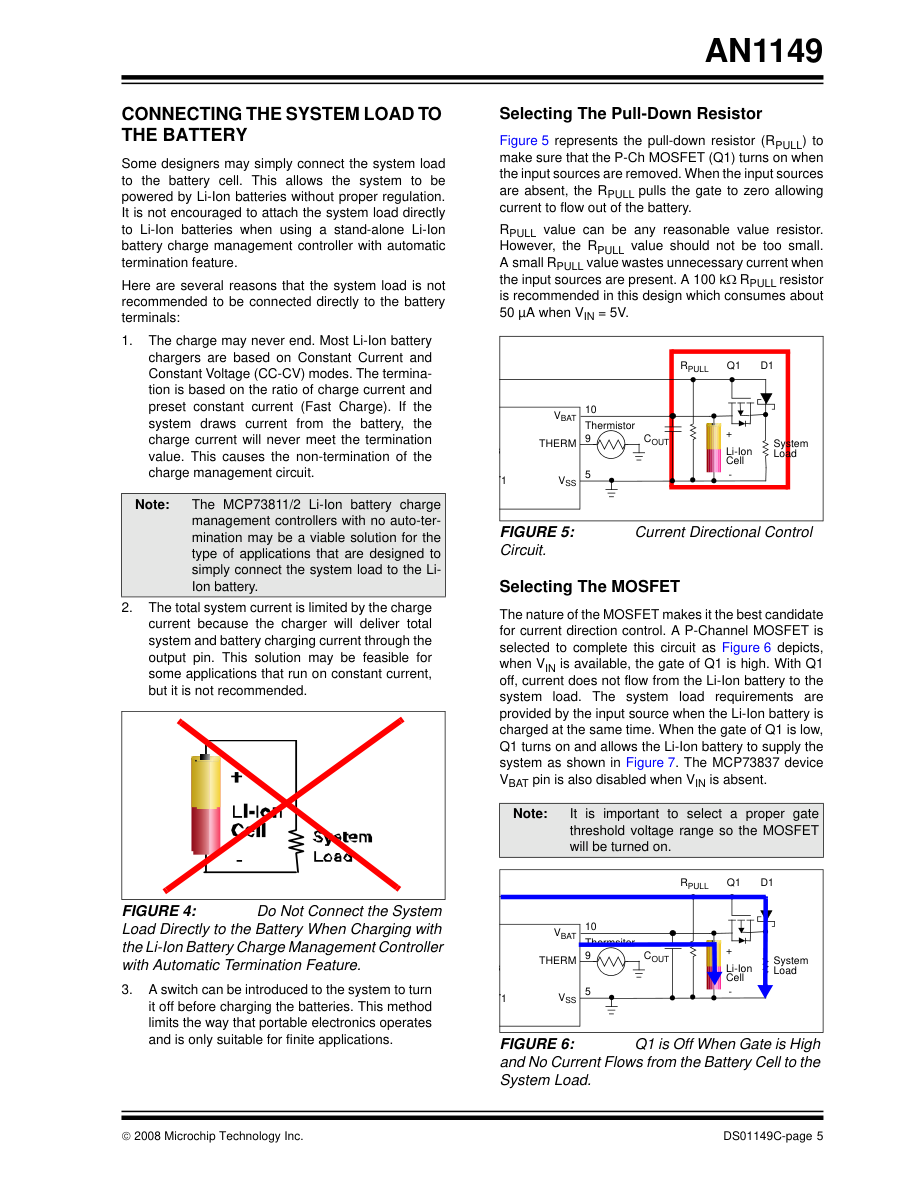
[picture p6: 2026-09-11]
BalancerREF/review/AN1149-pinout.png

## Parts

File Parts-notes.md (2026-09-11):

# Balancer Rev A schematic

The single A1 sheet contains 111 physical components (104 plus the U9 display buck section added 2026-09-08), with real KiCad wire segments and explicit junctions within circuits. Local net labels connect the sections. The separate Hirose microSD socket is removed; the Newhaven module provides microSD. USB-C is charge-only and J5 is the SWD interface. The board file has not been updated from this schematic.

## Display supply

DS1 J2.2 VIN is powered from U9, a TPS62260DDCR 600 mA buck on +5V, output +3V3_DISP = 0.6 x (1 + R32 453k / R33 100k) = 3.32 V, with L3 2.2 uH (DFE322520FD-2R2M), C43 10 uF in, C44 10 uF out, C45 22 pF feed-forward. The NHD-2.8C-CSXP-BREAKOUT datasheet specifies VDD 3.0-3.6 V, 200 mA typical / 280 mA maximum; 5 V must not be applied.

The display signal map uses WRX, J1.3, for LCD D/C. J1.2 is left open because it is the clock alias; J2.13 supplies SCK. For 4-wire SPI, close module R2/R3/R5 and open R1/R4/R6 per the current manufacturer interface table. Touch and card-detect are unused.

## Electrical implementation

- U8 pin 21 is VDDA, not VDD. It and VREF+ pin 20 connect to +3V3_A. MCU VDD pins 24/36/48 and VBAT pin 1 connect to +3V3, with decouplers provided. NRST is the PG10/NRST pin.
- Q1 SST507 is 1.8 mA nominal. Pins 2 and 3 are wired together to ACCEL_ICP. C1 is the specified 1 uF / 50 V AC-coupling part. BAT54S D1 clamps only the ADC-side signal after the OPA2320 and R5; no low-voltage TVS is placed on the raw ICP line. The second BAT54S from the original placement list is omitted because the supplied Rev A circuit uses one.
- The VCM divider capacitors are parallel to ground. The OPA2320 includes both follower circuits and its power unit. C4 connects differentially across ADC inputs 3 and 4. ADC pins 7-10 are explicitly NC, and CAP has 220 nF to GND.
- X1 drives the ADC clock and MCU HSE through separate 33 ohm resistors. MCU firmware must enable HSE bypass and TIM2_CH1 on PA0, and compensate ADC/analog filter delay when calculating phase.
- All analog and digital grounds use one electrical GND net. The analog region is annotated AGND; there is no split ground island or conflicting AGND net.
- BQ24074 EN1 connects to OUT and EN2 to ground for USB500 mode. The 10 kohm TS resistor disables battery temperature sensing as specified. The power switch is after OUT, allowing charging while the instrument is switched off.
- F1 uses Bourns MF-MSMF010-2, 100 mA hold / 300 mA trip, 1812. FB2 filters the tach supply. External button pullups and two LED series resistors are included.

## Footprints and purchasing details

All 100 PCB components have footprints with matching symbol-pin and footprint-pad number sets. Parts-footprint-map.csv lists the current references, values, MPNs, and footprints; RevA-pin-connections.csv lists every physical symbol pin and its connection or NC status.

The specified ICs, oscillator, inductors, diode, ferrites, AC-coupling capacitor, USB connector, and 24 V bulk capacitors retain their selected manufacturer parts. Newly specified generic resistors, capacitors, LEDs, buttons, and headers have package footprints but still require purchasing MPN selection. Resistors use 0805 with a 1% selection requirement. Capacitors use 0805, or 1210 for the generic 10/22 uF parts; select parts that meet the stated voltage, dielectric and effective capacitance requirements. C23/C24 are the selected C2012X7R1H225K125AC 2.2 uF / 50 V parts.

J1/J2 are panel-mounted MS3112E8-4S solder-cup receptacles, BT1 is the off-board Adafruit battery, and SW1 is the off-board power switch. They are included in the BOM and excluded from PCB placement. No PCB land pattern exists for those panel receptacles; the board-to-panel harness landing arrangement still needs mechanical selection. J4 is the battery's JST-PH board mate; J6 is the switch's board header. Verify the actual pack's red BAT+ and black GND wires against J4 before mating. Select SW1 for at least 1 A DC.

DS1's custom footprint represents the module mating interface with two 1x20 headers and four mounting holes, viewed from the display side. Pad numbers J1.1-J1.20 and J2.1-J2.20 identify the module's separate headers. Header drill/pad sizes are 1.0/1.8 mm for 2.54 mm pitch, mounting holes 3.2 mm, row separation 78.70 mm, and module envelope 69.03 x 85.20 mm. Final header purchasing and standoff clearance remain mechanical integration choices. The inductor land patterns follow Murata's drawings; SS14FL uses MCC DO-221AC, not SMA/SOD-123F.

## Verification

KiCad 10.0.3 successfully opens, renders, and exports the schematic. An exported netlist was compared against the authored pin-to-net manifest, checking missing pins, opens, unintended connected NC pins, and shorts between intended nets. No discrepancies were found. ERC reports zero errors and zero warnings as of 2026-09-08; the earlier DISPLAY_VIN_PENDING warning is resolved because DS1 J2.2 now connects to +3V3_DISP from U9. No ERC exclusions were added to hide circuit findings. The buck section was added with `.codex-parts/add_display_buck.py`; the prior state is in Balancer-backups/before-display-buck-20260908-060647. Matching pin/pad numbers verifies connectivity compatibility; it does not replace final mechanical, power/thermal, or bench validation.

Checks and source downloads are retained in .codex-parts. The schematic and project state before this installation are backed up at Balancer-backups/before-rev-a-install-20260906-183830.

## Manufacturer references

- [STM32G491 datasheet](https://www.st.com/resource/en/datasheet/stm32g491ce.pdf)
- [ADS131M02 datasheet](https://www.ti.com/lit/ds/symlink/ads131m02.pdf)
- [OPA2320 datasheet](https://www.ti.com/lit/ds/symlink/opa320.pdf)
- [Newhaven exact module datasheet](https://newhavendisplay.com/content/specs/NHD-2.8C-CSXP-BREAKOUT.pdf)
- [Newhaven exact module product page](https://newhavendisplay.com/tft-breakout-module-with-sunlight-readable-2-8-inch-ips-tft-display-capacitive-touchscreen/)
- [DSS MicroVib cable pinouts](https://www.dssmicro.com/faqs/faq_mv1_cable_repair_pinouts.htm)
- [ECS oscillator](https://ecsxtal.com/store/pdf/ECS-2520MVLC.pdf)
- [BQ24074 datasheet](https://www.ti.com/lit/ds/symlink/bq24074.pdf)
- [TPS61023 datasheet](https://www.ti.com/lit/ds/symlink/tps61023.pdf)
- [TPS61041 datasheet](https://www.ti.com/lit/ds/symlink/tps61041.pdf)
- [74LVC1G17 datasheet](https://www.diodes.com/datasheet/download/74LVC1G17.pdf)
- [USB4105 drawing](https://gct.co/files/drawings/usb4105.pdf)
- [Bourns resettable fuse](https://bourns.com/docs/product-datasheets/mf-msmf.pdf)
- [Murata LQH32PN land pattern](https://search.murata.co.jp/Ceramy/image/img/P02/JELF243A-0061.pdf)
- [Murata DFE322520FD land pattern](https://pim.murata.com/asset/pim4/inductor/J(E)TE243A-9104_PDF_INDUCTOR)
- [Adafruit battery](https://www.adafruit.com/product/258)

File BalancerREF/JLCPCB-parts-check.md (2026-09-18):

# JLCPCB / LCSC assembly check, Rev F BOM

Stock figures marked with a date are from LCSC/JLCPCB listings on that day; everything
else is unchecked. Re-check before ordering. "Basic" parts carry no per-part feeder fee;
everything else is "extended" (about $3 per unique part). Resistors are 0603 and
capacitors 0805 (C20 is 1210) in the current schematic; both sizes are JLCPCB basic for
common values.

| Ref | Part | LCSC / JLCPCB | Action |
|---|---|---|---|
| U1 | ESP32-S3-MINI-1-N8 | C2913206, ~2000 in stock, ~$3.14 (2026-09-09) | order as is (extended) |
| U2 | IIS3DWBTR | C717702, in stock, ~$16 (2026-09-09) | order as is (extended) |
| U3 | LM1815MX/NOPB | C2878578, only 3 in stock, ~$2.78 (2026-09-09) | consign from Digi-Key, or accept quantity risk |
| U4 | TS3021IYLT (head) | not listed; TS3021ILT C1509142 in stock (2026-09-09) | substitute TS3021ILT: same SOT-23-5 pinout, non-automotive grade |
| U5 | BQ24075RGTR | not checked | verify at order time; QFN-16, expected extended |
| U6 | TPS63031DSKR | C15516, ~6k in stock, ~$0.62 (2026-09-09) | order as is |
| U7 | SRV05-4MR6T1G | C604719, only 20 in stock, ~$1.94 (2026-09-09) | order early or consign; any SRV05-4 equivalent in SOT-23-6 with the same pinout is acceptable |
| U8 | TLV9062IDR (head) | not checked | verify at order time |
| U9 | SN74LVC1G132DBVR | not checked | verify at order time. NOT the 1G08: the circuit depends on Schmitt inputs and NAND polarity |
| U10 | SN74LVC1G123DCTR | C123302, in stock, ~$0.14 (2026-09-09) | order as is |
| Q1 (head), Q4 | AO3400A / AO3401A | JLCPCB basic | order as is |
| D1 (head) | XPEBRD-L1 (Cree XP-E2 red) | not carried by LCSC | consign from Digi-Key, or hand-place after assembly |
| D3 | SMF5.0A | expected extended | verify at order time |
| PD1 (head) | BPW34S | LCSC stocks VBPW34S C145262 (2026-09-09), Vishay's current PN for the same SMD part | use VBPW34S; same footprint |
| J1 | USB4105-GF-A | USB4105-GF-A-120 C5184243 and -060 C3025063 in stock (2026-09-09) | use -120 or -060: same connector, different packaging quantity |
| J2 | JST B2B-PH-K-S | JLCPCB basic | order as is |
| J4 | 1x05 2.54 header | basic | order as is or hand-solder |
| J5 (both boards) | JST SM07B-GHS-TB | not checked | verify at order time |
| L1 | DFE201612PD-1R5M=P2 | not checked | verify; many 2016 1.5 uH alternatives exist if not |
| SW1 | Wurth 450301014042 | not expected at LCSC | hand-solder (through-hole) or consign |
| SW2, SW3 | 6 mm tactile | many basic options | choose an LCSC basic tactile matching the assigned footprint |
| R3, R35, R36 | 3.57k 1%, 1.6k, 10k (charger set resistors) | basic 0603 | order as is; R3 must be 1% |
| R13, R14 | 10k 1206 pulse | basic 1206 | order as is |
| R18 (head) | 3R9 1206 0.5 W | basic 1206 | order as is (was 3R0 before Rev F) |
| C20 (head) | 100 uF 10 V 1210 | verify | 10 V rating is deliberate: SYS_SW can reach 5.5 V |
| TP1-3, 7, 9, 10 | test pads | no part | none |

**Practical order plan:** let JLCPCB place everything they stock, hand-solder or consign
D1, SW1, and if quantity is short, U3 and U7. Upload the exported BOM and CPL to their
tool for the definitive basic/extended split; this table is a pre-check, not a quote.

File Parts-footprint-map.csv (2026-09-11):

Reference | Value | Manufacturer Part Number | Footprint | PCB Component | Notes
J3 | USB4105-GF-A | USB4105-GF-A | Connector_USB:USB_C_Receptacle_GCT_USB4105-xx-A_16P_TopMnt_Horizontal | Yes
R16 | 5.1k |  | Resistor_SMD:R_0805_2012Metric | Yes | 0805 resistor; select purchasing MPN for stated value, 1%
R17 | 5.1k |  | Resistor_SMD:R_0805_2012Metric | Yes | 0805 resistor; select purchasing MPN for stated value, 1%
U4 | BQ24074RGTR | BQ24074RGTR | Package_DFN_QFN:VQFN-16-1EP_3x3mm_P0.5mm_EP1.6x1.6mm | Yes
R11 | 10k |  | Resistor_SMD:R_0805_2012Metric | Yes | 0805 resistor; select purchasing MPN for stated value, 1%
R18 | 1.18k |  | Resistor_SMD:R_0805_2012Metric | Yes | 0805 resistor; select purchasing MPN for stated value, 1%
R19 | 46.4k |  | Resistor_SMD:R_0805_2012Metric | Yes | 0805 resistor; select purchasing MPN for stated value, 1%
R20 | 3.01k |  | Resistor_SMD:R_0805_2012Metric | Yes | 0805 resistor; select purchasing MPN for stated value, 1%
R21 | 1.78k |  | Resistor_SMD:R_0805_2012Metric | Yes | 0805 resistor; select purchasing MPN for stated value, 1%
R22 | 100k |  | Resistor_SMD:R_0805_2012Metric | Yes | 0805 resistor; select purchasing MPN for stated value, 1%
R23 | 100k |  | Resistor_SMD:R_0805_2012Metric | Yes | 0805 resistor; select purchasing MPN for stated value, 1%
C6 | 1u / 10V |  | Capacitor_SMD:C_0805_2012Metric | Yes | Select purchasing MPN; verify effective capacitance at operating bias
C7 | 4.7u / 10V |  | Capacitor_SMD:C_0805_2012Metric | Yes | Select purchasing MPN; verify effective capacitance at operating bias
C8 | 4.7u / 10V |  | Capacitor_SMD:C_0805_2012Metric | Yes | Select purchasing MPN; verify effective capacitance at operating bias
U5 | TPS61023DRLR | TPS61023DRLR | Package_TO_SOT_SMD:SOT-563 | Yes
L1 | 1uH / DFE322520FD | DFE322520FD-1R0M=P2 | Balancer_Parts:L_Murata_DFE322520FD | Yes
R12 | 732k |  | Resistor_SMD:R_0805_2012Metric | Yes | 0805 resistor; select purchasing MPN for stated value, 1%
R13 | 100k |  | Resistor_SMD:R_0805_2012Metric | Yes | 0805 resistor; select purchasing MPN for stated value, 1%
C9 | 10p / C0G |  | Capacitor_SMD:C_0805_2012Metric | Yes | Select purchasing MPN; verify effective capacitance at operating bias
C10 | 10u / 10V |  | Capacitor_SMD:C_1210_3225Metric | Yes | Select purchasing MPN; verify effective capacitance at operating bias
C11 | 100n / 50V |  | Capacitor_SMD:C_0805_2012Metric | Yes | Select purchasing MPN; verify effective capacitance at operating bias
C12 | 22u / 10V |  | Capacitor_SMD:C_1210_3225Metric | Yes | Select purchasing MPN; verify effective capacitance at operating bias
C13 | 22u / 10V |  | Capacitor_SMD:C_1210_3225Metric | Yes | Select purchasing MPN; verify effective capacitance at operating bias
C14 | 100n / 50V |  | Capacitor_SMD:C_0805_2012Metric | Yes | Select purchasing MPN; verify effective capacitance at operating bias
U6 | TLV75533PDBVR | TLV75533PDBVR | Package_TO_SOT_SMD:SOT-23-5 | Yes
C15 | 1u / 10V |  | Capacitor_SMD:C_0805_2012Metric | Yes | Select purchasing MPN; verify effective capacitance at operating bias
C16 | 4.7u / 10V |  | Capacitor_SMD:C_0805_2012Metric | Yes | Select purchasing MPN; verify effective capacitance at operating bias
C17 | 100n / 50V |  | Capacitor_SMD:C_0805_2012Metric | Yes | Select purchasing MPN; verify effective capacitance at operating bias
FB1 | BLM21PG221SN1D | BLM21PG221SN1D | Inductor_SMD:L_0805_2012Metric | Yes
C18 | 4.7u / 10V |  | Capacitor_SMD:C_0805_2012Metric | Yes | Select purchasing MPN; verify effective capacitance at operating bias
C19 | 100n / 50V |  | Capacitor_SMD:C_0805_2012Metric | Yes | Select purchasing MPN; verify effective capacitance at operating bias
U7 | TPS61041DBVR | TPS61041DBVR | Package_TO_SOT_SMD:SOT-23-5 | Yes
L2 | 10uH / LQH32PN100MN0L | LQH32PN100MN0L | Balancer_Parts:L_Murata_LQH32PN | Yes
D2 | SS14FL-TP | SS14FL-TP | Balancer_Parts:D_MCC_DO-221AC | Yes
R14 | 1.85M |  | Resistor_SMD:R_0805_2012Metric | Yes | 0805 resistor; select purchasing MPN for stated value, 1%
R15 | 100k |  | Resistor_SMD:R_0805_2012Metric | Yes | 0805 resistor; select purchasing MPN for stated value, 1%
C20 | 10p / C0G |  | Capacitor_SMD:C_0805_2012Metric | Yes | Select purchasing MPN; verify effective capacitance at operating bias
C21 | 4.7u / 10V |  | Capacitor_SMD:C_0805_2012Metric | Yes | Select purchasing MPN; verify effective capacitance at operating bias
C22 | 100n / 50V |  | Capacitor_SMD:C_0805_2012Metric | Yes | Select purchasing MPN; verify effective capacitance at operating bias
C23 | 2.2u / 50V | C2012X7R1H225K125AC | Capacitor_SMD:C_0805_2012Metric | Yes | Select purchasing MPN; verify effective capacitance at operating bias
C24 | 2.2u / 50V | C2012X7R1H225K125AC | Capacitor_SMD:C_0805_2012Metric | Yes | Select purchasing MPN; verify effective capacitance at operating bias
C25 | 100n / 50V |  | Capacitor_SMD:C_0805_2012Metric | Yes | Select purchasing MPN; verify effective capacitance at operating bias
J1 | ACCEL / MS3112E8-4S | MS3112E8-4S |  | No
Q1 | SST507 / 1.8mA | SST507 SOT-23 3L ROHS | Package_TO_SOT_SMD:SOT-23 | Yes
C1 | 1u / 50V X7R | C0805C105K5RACTU | Capacitor_SMD:C_0805_2012Metric | Yes | Select purchasing MPN; verify effective capacitance at operating bias
R1 | 10k |  | Resistor_SMD:R_0805_2012Metric | Yes | 0805 resistor; select purchasing MPN for stated value, 1%
U2 | OPA2320AIDR | OPA2320AIDR | Package_SO:SOIC-8_3.9x4.9mm_P1.27mm | Yes
R2 | 1M |  | Resistor_SMD:R_0805_2012Metric | Yes | 0805 resistor; select purchasing MPN for stated value, 1%
R3 | 10k |  | Resistor_SMD:R_0805_2012Metric | Yes | 0805 resistor; select purchasing MPN for stated value, 1%
R4 | 10k |  | Resistor_SMD:R_0805_2012Metric | Yes | 0805 resistor; select purchasing MPN for stated value, 1%
C2 | 10u / 10V |  | Capacitor_SMD:C_1210_3225Metric | Yes | Select purchasing MPN; verify effective capacitance at operating bias
C3 | 100n / 50V |  | Capacitor_SMD:C_0805_2012Metric | Yes | Select purchasing MPN; verify effective capacitance at operating bias
C26 | 100n / 50V |  | Capacitor_SMD:C_0805_2012Metric | Yes | Select purchasing MPN; verify effective capacitance at operating bias
C27 | 1u / 10V |  | Capacitor_SMD:C_0805_2012Metric | Yes | Select purchasing MPN; verify effective capacitance at operating bias
U1 | ADS131M02IPWR | ADS131M02IPWR | Package_SO:TSSOP-20_4.4x6.5mm_P0.65mm | Yes
R5 | 1k |  | Resistor_SMD:R_0805_2012Metric | Yes | 0805 resistor; select purchasing MPN for stated value, 1%
R6 | 1k |  | Resistor_SMD:R_0805_2012Metric | Yes | 0805 resistor; select purchasing MPN for stated value, 1%
C4 | 10n / C0G |  | Capacitor_SMD:C_0805_2012Metric | Yes | Select purchasing MPN; verify effective capacitance at operating bias
D1 | BAT54S | BAT54S | Package_TO_SOT_SMD:SOT-23 | Yes
R24 | 1k |  | Resistor_SMD:R_0805_2012Metric | Yes | 0805 resistor; select purchasing MPN for stated value, 1%
R25 | 1k |  | Resistor_SMD:R_0805_2012Metric | Yes | 0805 resistor; select purchasing MPN for stated value, 1%
C28 | 1u / 10V |  | Capacitor_SMD:C_0805_2012Metric | Yes | Select purchasing MPN; verify effective capacitance at operating bias
C29 | 1u / 10V |  | Capacitor_SMD:C_0805_2012Metric | Yes | Select purchasing MPN; verify effective capacitance at operating bias
C30 | 220n / 16V |  | Capacitor_SMD:C_0805_2012Metric | Yes | Select purchasing MPN; verify effective capacitance at operating bias
X1 | ECS 8.192MHz | ECS-2520MVLC-081.92-BN-TR3 | Oscillator:Oscillator_SMD_ECS_2520MV-xxx-xx-4Pin_2.5x2.0mm | Yes
R7 | 33 |  | Resistor_SMD:R_0805_2012Metric | Yes | 0805 resistor; select purchasing MPN for stated value, 1%
R8 | 33 |  | Resistor_SMD:R_0805_2012Metric | Yes | 0805 resistor; select purchasing MPN for stated value, 1%
C31 | 100n / 50V |  | Capacitor_SMD:C_0805_2012Metric | Yes | Select purchasing MPN; verify effective capacitance at operating bias
U8 | STM32G491CET6 | STM32G491CET6 | Package_QFP:LQFP-48_7x7mm_P0.5mm | Yes
C32 | 100n / 50V |  | Capacitor_SMD:C_0805_2012Metric | Yes | Select purchasing MPN; verify effective capacitance at operating bias
C33 | 100n / 50V |  | Capacitor_SMD:C_0805_2012Metric | Yes | Select purchasing MPN; verify effective capacitance at operating bias
C34 | 100n / 50V |  | Capacitor_SMD:C_0805_2012Metric | Yes | Select purchasing MPN; verify effective capacitance at operating bias
C35 | 100n / 50V |  | Capacitor_SMD:C_0805_2012Metric | Yes | Select purchasing MPN; verify effective capacitance at operating bias
C36 | 4.7u / 10V |  | Capacitor_SMD:C_0805_2012Metric | Yes | Select purchasing MPN; verify effective capacitance at operating bias
C37 | 1u / 10V |  | Capacitor_SMD:C_0805_2012Metric | Yes | Select purchasing MPN; verify effective capacitance at operating bias
C38 | 100n / 50V |  | Capacitor_SMD:C_0805_2012Metric | Yes | Select purchasing MPN; verify effective capacitance at operating bias
R26 | 100k |  | Resistor_SMD:R_0805_2012Metric | Yes | 0805 resistor; select purchasing MPN for stated value, 1%
R27 | 10k |  | Resistor_SMD:R_0805_2012Metric | Yes | 0805 resistor; select purchasing MPN for stated value, 1%
C39 | 100n / 50V |  | Capacitor_SMD:C_0805_2012Metric | Yes | Select purchasing MPN; verify effective capacitance at operating bias
J2 | TACH / MS3112E8-4S | MS3112E8-4S |  | No
R9 | 4.7k |  | Resistor_SMD:R_0805_2012Metric | Yes | 0805 resistor; select purchasing MPN for stated value, 1%
U3 | 74LVC1G17W5-7 | 74LVC1G17W5-7 | Package_TO_SOT_SMD:SOT-23-5 | Yes
R10 | 10k |  | Resistor_SMD:R_0805_2012Metric | Yes | 0805 resistor; select purchasing MPN for stated value, 1%
C5 | 1n / C0G |  | Capacitor_SMD:C_0805_2012Metric | Yes | Select purchasing MPN; verify effective capacitance at operating bias
C40 | 100n / 50V |  | Capacitor_SMD:C_0805_2012Metric | Yes | Select purchasing MPN; verify effective capacitance at operating bias
F1 | 100mA hold / MF-MSMF010-2 | MF-MSMF010-2 | Fuse:Fuse_1812_4532Metric | Yes
FB2 | BLM21PG221SN1D | BLM21PG221SN1D | Inductor_SMD:L_0805_2012Metric | Yes
C41 | 10u / 10V |  | Capacitor_SMD:C_1210_3225Metric | Yes | Select purchasing MPN; verify effective capacitance at operating bias
C42 | 100n / 50V |  | Capacitor_SMD:C_0805_2012Metric | Yes | Select purchasing MPN; verify effective capacitance at operating bias
DS1 | NHD-2.8C-CSXP-BREAKOUT | NHD-2.8C-CSXP-BREAKOUT | Balancer_Parts:NHD-2.8C-CSXP-BREAKOUT | Yes
BT1 | Adafruit 258 / 1200mAh | Adafruit 258 |  | No
J4 | BATTERY JST-PH | B2B-PH-K-S | Connector_JST:JST_PH_B2B-PH-K_1x02_P2.00mm_Vertical | Yes
SW1 | POWER / >=1A DC |  |  | No | Off-board power switch; select mechanical part, rated at least 1A DC
J6 | POWER SWITCH |  | Connector_PinHeader_2.54mm:PinHeader_1x02_P2.54mm_Vertical | Yes
J5 | SWD / ST-LINK |  | Connector_PinHeader_2.54mm:PinHeader_1x05_P2.54mm_Vertical | Yes
SW2 | ACQUIRE |  | Button_Switch_THT:SW_PUSH_6mm | Yes
R28 | 10k |  | Resistor_SMD:R_0805_2012Metric | Yes | 0805 resistor; select purchasing MPN for stated value, 1%
SW3 | BACK / FUNCTION |  | Button_Switch_THT:SW_PUSH_6mm | Yes
R29 | 10k |  | Resistor_SMD:R_0805_2012Metric | Yes | 0805 resistor; select purchasing MPN for stated value, 1%
R30 | 1k |  | Resistor_SMD:R_0805_2012Metric | Yes | 0805 resistor; select purchasing MPN for stated value, 1%
D3 | GREEN |  | LED_SMD:LED_0805_2012Metric | Yes
R31 | 1k |  | Resistor_SMD:R_0805_2012Metric | Yes | 0805 resistor; select purchasing MPN for stated value, 1%
D4 | RED |  | LED_SMD:LED_0805_2012Metric | Yes
TP1 | SWO |  | TestPoint:TestPoint_Pad_D1.5mm | Yes
U9 | TPS62260DDCR | TPS62260DDCR | Package_TO_SOT_SMD:SOT-23-5 | Yes | 3.3 V display buck; 600 mA
L3 | 2.2uH | DFE322520FD-2R2M=P2 | Balancer_Parts:L_Murata_DFE322520FD | Yes
C43 | 10u / 10V |  | Capacitor_SMD:C_1210_3225Metric | Yes | Select purchasing MPN; buck input cap
C44 | 10u / 10V |  | Capacitor_SMD:C_1210_3225Metric | Yes | Select purchasing MPN; buck output cap
C45 | 22p |  | Capacitor_SMD:C_0805_2012Metric | Yes | Feed-forward across R32
R32 | 453k |  | Resistor_SMD:R_0805_2012Metric | Yes | 0805 resistor; 1%
R33 | 100k |  | Resistor_SMD:R_0805_2012Metric | Yes | 0805 resistor; 1%

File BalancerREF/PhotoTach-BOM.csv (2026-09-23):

Board | Ref | Qty | Description | Manufacturer | MPN | DigiKey PN / page | Approx unit USD | Notes
OptHead | D1 | 1 | Red 625 nm high-power LED, 1 A max, Vf 2.2 V, 3535 | Cree LED | XPEBRD-L1-0000-00501 | XPEBRD-L1-0000-00501CT-ND | 1.50 | Pulsed 500 mA, 5 us at 20 kHz (10 percent duty); visible aiming spot; any XPEBRD-L1 bin works
OptHead | PD1 | 1 | Si PIN photodiode, SMD DIL 4.5x4 mm, 7.02 mm2, peak 620 nm, IR-filtered 400-690 nm, tr 90 ns | ams OSRAM | SFH 2440 | SFH 2440, or SFH 2440-Z for tape and reel | 1.30 | CHANGED 2026-09-21. Was BPW34S. Osram SMD version is discontinued, and Vishay BPW34S is LEADED (doc 81521: "packed in tubes, specifications like BPW34"), so the old line paired an SMD footprint with a through-hole part number. SFH 2440 is pad-identical to Osram_BPW34S-SMD so there is no layout change; peak 620 nm matches the 625 nm emitter, and its 400-690 nm window blocks the IR the BPW34 (peak 900 nm) was most sensitive to. NOT SFH 2430: 200 us rise time, 1000 pF, unusable for tach phase.
OptHead | LENS1 | 1 | 9.9 mm TINA spot lens 10-15 deg with adhesive holder for Cree XP-E | Ledil | FA10887_TINA-RS | 711-1113-ND | 3.50 | Holder included; adhesive to PCB. Carclo 10193 and 10003 were out of stock 2026-09-09
OptHead | LENS1-ALT | 0 | LISA2 spot lens 15-24 deg with pin holder (alternate) | Ledil | FP11055_LISA2-RS-PIN | 711-1105-ND | 3.00 | Wider beam: about 8 in wide at 24 in; more aim tolerance
OptHead | U8 | 1 | Dual 10 MHz RRIO CMOS op amp, SOIC-8 | Texas Instruments | TLV9062IDR | 296-47857-1-ND | 0.65 | REF WAS WRONG: listed as U4, but U4 on this board is the TS3021. A: transimpedance 10k; B: AC-coupled gain 20. VSSOP TLV9062IDGKR was out of stock 2026-09-09, same die
OptHead | U8-ALT | 0 | Dual 10 MHz op amp, SOIC-8, drop-in alternate | Microchip | MCP6292-E/SN | MCP6292-E/SN-ND | 0.70 | Same pinout and bandwidth class; use if the TLV9062 runs out
OptHead | U4 | 1 | Comparator, push-pull, SOT-23-5 | STMicroelectronics | TS3021IYLT | already in Rev B BOM | 0.45 | REF WAS WRONG: listed as U5, but U5 on BalancerREF is the BQ24075 charger. Fixed divider threshold plus 470k hysteresis; RV1 deleted
OptHead | Q1 | 1 | N-channel MOSFET 30 V 5.7 A, SOT-23 | Alpha and Omega | AO3400A | already in Rev B BOM | 0.20 | Switches the LED pulse current; gate driven from OPT_LED_EN through R19
OptHead | J5 | 1 | JST GH 7-way horizontal, 1.25 mm pitch | JST | SM07B-GHS-TB | 455-1650-1-ND | 0.60 | To main board: VBAT, GND, OPT_LED_EN, GND, OPT_COMP, GND, +3V3
OptHead | R18 | 1 | 3.9 ohm 1206 0.5 W pulse resistor | generic | any 1206 3R9 1 percent | search "3.9 ohm 1206 0.5W" | 0.10 | Sets about 490 mA peak at a full 4.2 V cell; size at the top of the VBAT range. MUST stay 1206: the pulse withstand is a function of body size, not resistance
OptHead | R19 | 1 | 100 ohm 0603 | generic | any | stock | 0.01 | ADDED - had no BOM line. Gate series resistor for Q1
OptHead | R20 | 1 | 100k 0603 | generic | any | stock | 0.01 | ADDED - had no BOM line
OptHead | R21 | 1 | 10k 0603 1 percent | generic | any | stock | 0.01 | Transimpedance feedback
OptHead | R22, R23 | 2 | 10k and 120k 0603 1 percent | generic | any | stock | 0.02 | Gain stage. WAS WRONG: BOM said 200k; schematic R23 is 120k
OptHead | R24, R25 | 2 | 10k 0603 1 percent, qty 2 | generic | any | stock | 0.02 | ADDED - had no BOM line. OPT_VREF mid-rail divider; without these the op amp has no reference
OptHead | R26, R27 | 2 | 22k and 10k 0603 1 percent | generic | any | stock | 0.02 | Comparator threshold divider. Values are fixed in the schematic now; the BOM previously said "set on bench"
OptHead | R28 | 1 | 470k 0603 | generic | any | stock | 0.01 | Comparator hysteresis. The old BOM note mis-referenced this as R26; R26 is the 22k threshold leg
OptHead | R32 | 1 | 33 ohm 0603 | generic | any | stock | 0.01 | ADDED - had no BOM line
OptHead | C20 | 1 | 100 uF 10 V low-ESR, 1210 | generic | any | search "100uF 10V 1210" | 0.30 | Local reservoir for the 5 us 500 mA pulses; place at R18. WAS WRONG: BOM said 6.3 V, schematic is 10 V
OptHead | C21 | 1 | 22 pF 0805 C0G | generic | any | stock | 0.01 | CHANGED 2026-09-21 from 10 pF. TIA stability: SFH 2440 roughly doubles junction capacitance (135 pF vs ~72 pF at zero bias), so Cf_min = sqrt(Cin/(2*pi*Rf*GBW)) rises to about 12.3 pF with R21 10k and the TLV9062 10 MHz GBW; the fitted 10 pF would peak. 22 pF still leaves 723 kHz. Package WAS WRONG: BOM said 0603, schematic is 0805.
OptHead | C22 | 1 | 10 nF 0805 X7R | generic | any | stock | 0.01 | AC coupling into the gain stage. Package WAS WRONG: BOM said 0603, schematic is 0805
OptHead | C23, C24, C25 | 3 | 100 nF 0805, qty 3 | generic | any | stock | 0.03 | Decoupling for U4 and U8. Package WAS WRONG: BOM said 0603, schematic is 0805
BalancerREF | U9 | 1 | Single 2-input NAND gate, Schmitt inputs, SOT-23-5 | Texas Instruments | SN74LVC1G132DBVR | 296-13321-1-ND | 0.12 | Synchronous gate: comparator NAND delayed emitter pulse. MUST be the 1G132, not the 1G08 it replaced
BalancerREF | U10 | 1 | Retriggerable monostable, Schmitt inputs, SSOP-8 | Texas Instruments | SN74LVC1G123DCTR | digikey.com/en/products/detail/texas-instruments | 0.55 | REF WAS WRONG: listed as U7, but U7 on BalancerREF is the SRV05-4 ESD array. Trigger is pin 1 A falling, with B and CLR held high
BalancerREF | R29, C26 | 2 | 1k 0603 and 470 pF 0805 C0G | generic | any | stock | 0.02 | Delays the emitter pulse copy about 0.5 us into the gate to match receiver latency
BalancerREF | R30, C28 | 2 | 10k 0603 and 10 nF 0805 C0G | generic | any | stock | 0.02 | CHANGED 2026-09-20 from 100k / 1 nF. One-shot timing: 10k/10n is the characterised row in TI SCES586E section 5.8, tw 100-110 us guaranteed across all four supply voltages. 100k is ten times beyond the largest Rext TI characterises.
BalancerREF | R39, R40 | 2 | 100k 0603, qty 2 | generic | any | stock | 0.02 | R39 holds OPT_COMP low when the head is unplugged from J5; R40 holds the R29/C26 strobe low
mechanical | WINDOW | 1 | Red-tinted acrylic window, 3 mm, covering LED and photodiode | enclosure part | n/a | McMaster or Tap Plastics | 2.00 | Long-pass filter; keep an internal baffle between LED and photodiode. Less critical now that the SFH 2440 blocks IR itself
mechanical | TAPE | 1 | Retroreflective tape, 25 mm wide | 3M | 3M 7610 or Banner BRT-THG-2X2 | not a Digi-Key item | 10.00 | Required: ordinary reflective tape returns far too little at 24 in

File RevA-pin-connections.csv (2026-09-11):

Reference | Pin | Pin Name | Connected Net
J3 | A1 | GND | GND
J3 | A4 | VBUS | USB_VBUS
J3 | A5 | CC1 | CC1
J3 | A6 | D+ | NC
J3 | A7 | D- | NC
J3 | A8 | SBU1 | NC
J3 | A9 | VBUS | USB_VBUS
J3 | A12 | GND | GND
J3 | B1 | GND | GND
J3 | B4 | VBUS | USB_VBUS
J3 | B5 | CC2 | CC2
J3 | B6 | D+ | NC
J3 | B7 | D- | NC
J3 | B8 | SBU2 | NC
J3 | B9 | VBUS | USB_VBUS
J3 | B12 | GND | GND
J3 | SH | SHIELD | GND
R16 | 1 |  | CC1
R16 | 2 |  | GND
R17 | 1 |  | CC2
R17 | 2 |  | GND
U4 | 1 | TS | TS_FIXED
U4 | 2 | BAT | BAT+
U4 | 3 | BAT | BAT+
U4 | 4 | ~{CE} | GND
U4 | 5 | EN2 | GND
U4 | 6 | EN1 | SYS_OUT
U4 | 7 | ~{PGOOD} | PGOOD
U4 | 8 | VSS | GND
U4 | 9 | ~{CHG} | CHG
U4 | 10 | OUT | SYS_OUT
U4 | 11 | OUT | SYS_OUT
U4 | 12 | ILIM | BQ_ILIM
U4 | 13 | IN | USB_VBUS
U4 | 14 | TMR | BQ_TMR
U4 | 15 | ITERM | BQ_ITERM
U4 | 16 | ISET | BQ_ISET
U4 | 17 | VSS | GND
R11 | 1 |  | TS_FIXED
R11 | 2 |  | GND
R18 | 1 |  | BQ_ILIM
R18 | 2 |  | GND
R19 | 1 |  | BQ_TMR
R19 | 2 |  | GND
R20 | 1 |  | BQ_ITERM
R20 | 2 |  | GND
R21 | 1 |  | BQ_ISET
R21 | 2 |  | GND
R22 | 1 |  | +3V3
R22 | 2 |  | PGOOD
R23 | 1 |  | +3V3
R23 | 2 |  | CHG
C6 | 1 |  | USB_VBUS
C6 | 2 |  | GND
C7 | 1 |  | BAT+
C7 | 2 |  | GND
C8 | 1 |  | SYS_OUT
C8 | 2 |  | GND
U5 | 3 | VIN | SYS_RAW
U5 | 2 | EN | SYS_RAW
U5 | 4 | GND | GND
U5 | 5 | SW | BOOST5_SW
U5 | 6 | VOUT | +5V
U5 | 1 | FB | BOOST5_FB
L1 | 1 | 1 | SYS_RAW
L1 | 2 | 2 | BOOST5_SW
R12 | 1 |  | +5V
R12 | 2 |  | BOOST5_FB
R13 | 1 |  | BOOST5_FB
R13 | 2 |  | GND
C9 | 1 |  | +5V
C9 | 2 |  | BOOST5_FB
C10 | 1 |  | SYS_RAW
C10 | 2 |  | GND
C11 | 1 |  | SYS_RAW
C11 | 2 |  | GND
C12 | 1 |  | +5V
C12 | 2 |  | GND
C13 | 1 |  | +5V
C13 | 2 |  | GND
C14 | 1 |  | +5V
C14 | 2 |  | GND
U6 | 1 | IN | +5V
U6 | 2 | GND | GND
U6 | 3 | EN | +5V
U6 | 4 | NC | NC
U6 | 5 | OUT | +3V3
C15 | 1 |  | +5V
C15 | 2 |  | GND
C16 | 1 |  | +3V3
C16 | 2 |  | GND
C17 | 1 |  | +3V3
C17 | 2 |  | GND
FB1 | 1 |  | +3V3
FB1 | 2 |  | +3V3_A
C18 | 1 |  | +3V3_A
C18 | 2 |  | GND
C19 | 1 |  | +3V3_A
C19 | 2 |  | GND
U7 | 1 | SW | BOOST24_SW
U7 | 2 | GND | GND
U7 | 3 | FB | BOOST24_FB
U7 | 4 | EN | +5V
U7 | 5 | VIN | +5V
L2 | 1 | 1 | +5V
L2 | 2 | 2 | BOOST24_SW
D2 | 1 | K | +24V_ICP
D2 | 2 | A | BOOST24_SW
R14 | 1 |  | +24V_ICP
R14 | 2 |  | BOOST24_FB
R15 | 1 |  | BOOST24_FB
R15 | 2 |  | GND
C20 | 1 |  | +24V_ICP
C20 | 2 |  | BOOST24_FB
C21 | 1 |  | +5V
C21 | 2 |  | GND
C22 | 1 |  | +5V
C22 | 2 |  | GND
C23 | 1 |  | +24V_ICP
C23 | 2 |  | GND
C24 | 1 |  | +24V_ICP
C24 | 2 |  | GND
C25 | 1 |  | +24V_ICP
C25 | 2 |  | GND
J1 | A | A | NC
J1 | B | B | GND
J1 | C | C | NC
J1 | D | D | ACCEL_ICP
Q1 | 1 | A | +24V_ICP
Q1 | 2 | K | ACCEL_ICP
Q1 | 3 | K | ACCEL_ICP
C1 | 1 |  | ACCEL_ICP
C1 | 2 |  | ACCEL_AC
R1 | 1 |  | ACCEL_AC
R1 | 2 |  | ACCEL_BIASED
U2 | 1 |  | ACCEL_BUFFERED
U2 | 2 | - | ACCEL_BUFFERED
U2 | 3 | + | ACCEL_BIASED
U2 | 5 | + | VCM_RAW
U2 | 6 | - | VCM_1V65
U2 | 7 |  | VCM_1V65
U2 | 4 | V- | GND
U2 | 8 | V+ | +3V3_A
R2 | 1 |  | ACCEL_BIASED
R2 | 2 |  | VCM_1V65
R3 | 1 |  | +3V3_A
R3 | 2 |  | VCM_RAW
R4 | 1 |  | VCM_RAW
R4 | 2 |  | GND
C2 | 1 |  | VCM_RAW
C2 | 2 |  | GND
C3 | 1 |  | VCM_RAW
C3 | 2 |  | GND
C26 | 1 |  | +3V3_A
C26 | 2 |  | GND
C27 | 1 |  | +3V3_A
C27 | 2 |  | GND
U1 | 1 | AVDD | +3V3_A
U1 | 2 | AGND | GND
U1 | 3 | AIN0P | ADC_AIN0P
U1 | 4 | AIN0N | ADC_AIN0N
U1 | 6 | AIN1P | ADC_AIN1P
U1 | 5 | AIN1N | ADC_AIN1N
U1 | 7 | NC | NC
U1 | 8 | NC | NC
U1 | 9 | NC | NC
U1 | 10 | NC | NC
U1 | 20 | DVDD | +3V3
U1 | 19 | DGND | GND
U1 | 18 | CAP | ADC_CAP
U1 | 17 | CLKIN | ADC_CLK_8M192
U1 | 16 | DIN | SPI1_MOSI
U1 | 15 | DOUT | SPI1_MISO
U1 | 14 | SCLK | SPI1_SCK
U1 | 13 | ~{DRDY} | ADC_DRDY
U1 | 12 | ~{CS} | ADC_CS
U1 | 11 | ~{SYNC/RESET} | ADC_RESET
R5 | 1 |  | ACCEL_BUFFERED
R5 | 2 |  | ADC_AIN0P
R6 | 1 |  | VCM_1V65
R6 | 2 |  | ADC_AIN0N
C4 | 1 |  | ADC_AIN0P
C4 | 2 |  | ADC_AIN0N
D1 | 1 | A | GND
D1 | 2 | K | +3V3_A
D1 | 3 | COM | ADC_AIN0P
R24 | 1 |  | ADC_AIN1P
R24 | 2 |  | GND
R25 | 1 |  | ADC_AIN1N
R25 | 2 |  | GND
C28 | 1 |  | +3V3_A
C28 | 2 |  | GND
C29 | 1 |  | +3V3
C29 | 2 |  | GND
C30 | 1 |  | ADC_CAP
C30 | 2 |  | GND
X1 | 4 | VDD | +3V3
X1 | 1 | EN | +3V3
X1 | 3 | OUT | CLK_SOURCE
X1 | 2 | GND | GND
R7 | 1 |  | CLK_SOURCE
R7 | 2 |  | ADC_CLK_8M192
R8 | 1 |  | CLK_SOURCE
R8 | 2 |  | MCU_HSE
C31 | 1 |  | +3V3
C31 | 2 |  | GND
U8 | 1 | VBAT | +3V3
U8 | 2 | PC13 | NC
U8 | 3 | PC14 | NC
U8 | 4 | PC15 | NC
U8 | 5 | PF0/OSC_IN | MCU_HSE
U8 | 6 | PF1/OSC_OUT | NC
U8 | 7 | PG10/~{NRST} | NRST
U8 | 8 | PA0 | TACH_CAPTURE
U8 | 9 | PA1 | BTN_ACQUIRE
U8 | 10 | PA2 | BTN_BACK
U8 | 11 | PA3 | CHG
U8 | 12 | PA4 | ADC_CS
U8 | 13 | PA5 | SPI1_SCK
U8 | 14 | PA6 | SPI1_MISO
U8 | 15 | PA7 | SPI1_MOSI
U8 | 16 | PB0 | ADC_DRDY
U8 | 17 | PB1 | ADC_RESET
U8 | 18 | PB2 | PGOOD
U8 | 19 | VSSA | GND
U8 | 20 | VREF+ | +3V3_A
U8 | 21 | VDDA | +3V3_A
U8 | 22 | PB10 | LCD_RST
U8 | 23 | VSS | GND
U8 | 24 | VDD | +3V3
U8 | 25 | PB11 | LCD_DC
U8 | 26 | PB12 | LCD_CS
U8 | 27 | PB13 | SPI2_SCK
U8 | 28 | PB14 | SPI2_MISO
U8 | 29 | PB15 | SPI2_MOSI
U8 | 30 | PA8 | NC
U8 | 31 | PA9 | NC
U8 | 32 | PA10 | NC
U8 | 33 | PA11 | NC
U8 | 34 | PA12 | NC
U8 | 35 | VSS | GND
U8 | 36 | VDD | +3V3
U8 | 37 | PA13 | SWDIO
U8 | 38 | PA14 | SWCLK
U8 | 39 | PA15 | NC
U8 | 40 | PB3 | SWO
U8 | 41 | PB4 | RUN_LED
U8 | 42 | PB5 | FAULT_LED
U8 | 43 | PB6 | NC
U8 | 44 | PB7 | NC
U8 | 45 | PB8/BOOT0 | BOOT0
U8 | 46 | PB9 | SD_CS
U8 | 47 | VSS | GND
U8 | 48 | VDD | +3V3
C32 | 1 |  | +3V3
C32 | 2 |  | GND
C33 | 1 |  | +3V3
C33 | 2 |  | GND
C34 | 1 |  | +3V3
C34 | 2 |  | GND
C35 | 1 |  | +3V3
C35 | 2 |  | GND
C36 | 1 |  | +3V3
C36 | 2 |  | GND
C37 | 1 |  | +3V3_A
C37 | 2 |  | GND
C38 | 1 |  | +3V3_A
C38 | 2 |  | GND
R26 | 1 |  | BOOT0
R26 | 2 |  | GND
R27 | 1 |  | +3V3
R27 | 2 |  | NRST
C39 | 1 |  | NRST
C39 | 2 |  | GND
J2 | A | A | +5V_TACH
J2 | B | B | GND
J2 | C | C | NC
J2 | D | D | TACH_SIG
R9 | 1 |  | TACH_SIG
R9 | 2 |  | TACH_IN
U3 | 1 | NC | NC
U3 | 2 |  | TACH_IN
U3 | 3 | GND | GND
U3 | 4 |  | TACH_CAPTURE
U3 | 5 | VCC | +3V3
R10 | 1 |  | +5V_TACH
R10 | 2 |  | TACH_IN
C5 | 1 |  | TACH_IN
C5 | 2 |  | GND
C40 | 1 |  | +3V3
C40 | 2 |  | GND
F1 | 1 |  | +5V
F1 | 2 |  | TACH_FUSED
FB2 | 1 |  | TACH_FUSED
FB2 | 2 |  | +5V_TACH
C41 | 1 |  | +5V_TACH
C41 | 2 |  | GND
C42 | 1 |  | +5V_TACH
C42 | 2 |  | GND
DS1 | J1.1 | GND | GND
DS1 | J1.2 | DCX/SCL | NC
DS1 | J1.3 | WRX/DCX | LCD_DC
DS1 | J1.4 | RDX | NC
DS1 | J1.5 | DB0 | NC
DS1 | J1.6 | DB1 | NC
DS1 | J1.7 | DB2 | NC
DS1 | J1.8 | DB3 | NC
DS1 | J1.9 | DB4 | NC
DS1 | J1.10 | DB5 | NC
DS1 | J1.11 | DB6 | NC
DS1 | J1.12 | DB7 | NC
DS1 | J1.13 | DB8 | NC
DS1 | J1.14 | DB9 | NC
DS1 | J1.15 | DB10 | NC
DS1 | J1.16 | DB11 | NC
DS1 | J1.17 | DB12 | NC
DS1 | J1.18 | DB13 | NC
DS1 | J1.19 | DB14 | NC
DS1 | J1.20 | DB15 | NC
DS1 | J2.1 | GND | GND
DS1 | J2.2 | VIN | +3V3_DISP
DS1 | J2.3 | TP_SDA | NC
DS1 | J2.4 | TP_SCL | NC
DS1 | J2.5 | TP_INT | NC
DS1 | J2.6 | ~{TP_RST} | NC
DS1 | J2.7 | IM0 | NC
DS1 | J2.8 | IM1 | NC
DS1 | J2.9 | IM2 | NC
DS1 | J2.10 | SDO | SPI2_MISO
DS1 | J2.11 | SDA | SPI2_MOSI
DS1 | J2.12 | ~{CSX} | LCD_CS
DS1 | J2.13 | SCL/DCX | SPI2_SCK
DS1 | J2.14 | ~{RST} | LCD_RST
DS1 | J2.15 | BLK_NC | NC
DS1 | J2.16 | GND | GND
DS1 | J2.17 | TE_NC | NC
DS1 | J2.18 | SD_SDO | SPI2_MISO
DS1 | J2.19 | ~{SD_CS} | SD_CS
DS1 | J2.20 | SD_CD | NC
BT1 | 1 | + | BAT+
BT1 | 2 | - | GND
J4 | 1 | Pin_1 | GND
J4 | 2 | Pin_2 | BAT+
SW1 | 1 | A | SYS_OUT
SW1 | 2 | B | SYS_RAW
J6 | 1 | Pin_1 | SYS_OUT
J6 | 2 | Pin_2 | SYS_RAW
J5 | 1 | Pin_1 | +3V3
J5 | 2 | Pin_2 | SWDIO
J5 | 3 | Pin_3 | GND
J5 | 4 | Pin_4 | SWCLK
J5 | 5 | Pin_5 | NRST
SW2 | 1 | 1 | BTN_ACQUIRE
SW2 | 2 | 2 | GND
R28 | 1 |  | +3V3
R28 | 2 |  | BTN_ACQUIRE
SW3 | 1 | 1 | BTN_BACK
SW3 | 2 | 2 | GND
R29 | 1 |  | +3V3
R29 | 2 |  | BTN_BACK
R30 | 1 |  | RUN_LED
R30 | 2 |  | D3_A
D3 | 1 | K | GND
D3 | 2 | A | D3_A
R31 | 1 |  | FAULT_LED
R31 | 2 |  | D4_A
D4 | 1 | K | GND
D4 | 2 | A | D4_A
TP1 | 1 | 1 | SWO
U9 | 1 | VIN | +5V
U9 | 2 | GND | GND
U9 | 3 | EN | +5V
U9 | 4 | FB | DISP_FB
U9 | 5 | SW | DISP_SW
L3 | 1 | 1 | DISP_SW
L3 | 2 | 2 | +3V3_DISP
C43 | 1 |  | +5V
C43 | 2 |  | GND
C44 | 1 |  | +3V3_DISP
C44 | 2 |  | GND
C45 | 1 |  | +3V3_DISP
C45 | 2 |  | DISP_FB
R32 | 1 |  | +3V3_DISP
R32 | 2 |  | DISP_FB
R33 | 1 |  | DISP_FB
R33 | 2 |  | GND

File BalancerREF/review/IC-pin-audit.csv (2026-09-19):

Reference | Physical pad | Manufacturer function | KiCad net | Unused rationale
U1 | 1 | GND | GND
U1 | 2 | GND | GND
U1 | 3 | 3V3 | /+3V3
U1 | 4 | GPIO0 | /BOOT
U1 | 5 | GPIO1 | /GPS_UART_TX
U1 | 6 | GPIO2 | /GPS_UART_RX
U1 | 7 | GPIO3 | unconnected-(U1-IO3-Pad7) | Unused GPIO; retain default strap states on GPIO3/45/46
U1 | 8 | GPIO4 | unconnected-(U1-IO4-Pad8) | Unused GPIO; BAT_SENSE removed once the BQ24075 PGOOD pin made it redundant
U1 | 9 | GPIO5 | /CHG_EN1
U1 | 10 | GPIO6 | /ACCEL_DRDY
U1 | 11 | GPIO7 | /MAG_TACH
U1 | 12 | GPIO8 | /OPT_TACH
U1 | 13 | GPIO9 | /OPT_LED_EN
U1 | 14 | GPIO10 | /ACQUIRE_BUTTON
U1 | 15 | GPIO11 | /STATUS_LED
U1 | 16 | GPIO12 | /SUPPLY_SENSE
U1 | 17 | GPIO13 | /GPS_PPS
U1 | 18 | GPIO14 | /ACCEL_SCK
U1 | 19 | GPIO15 | /ACCEL_MOSI
U1 | 20 | GPIO16 | /ACCEL_MISO
U1 | 21 | GPIO17 | /ACCEL_CS
U1 | 22 | GPIO18 | /CHG_EN2
U1 | 23 | GPIO19/USB_D- | Net-(U1-USB_D-)
U1 | 24 | GPIO20/USB_D+ | Net-(U1-USB_D+)
U1 | 25 | GPIO21 | /PGOOD_N
U1 | 26 | GPIO26 | unconnected-(U1-IO26-Pad26) | Unused GPIO; retain default strap states on GPIO3/45/46
U1 | 27 | GPIO47 | unconnected-(U1-IO47-Pad27) | Unused GPIO; retain default strap states on GPIO3/45/46
U1 | 28 | GPIO33 | unconnected-(U1-IO33-Pad28) | Unused GPIO; retain default strap states on GPIO3/45/46
U1 | 29 | GPIO34 | unconnected-(U1-IO34-Pad29) | Unused GPIO; retain default strap states on GPIO3/45/46
U1 | 30 | GPIO48 | unconnected-(U1-IO48-Pad30) | Unused GPIO; retain default strap states on GPIO3/45/46
U1 | 31 | GPIO35 | unconnected-(U1-IO35-Pad31) | Unused GPIO; retain default strap states on GPIO3/45/46
U1 | 32 | GPIO36 | unconnected-(U1-IO36-Pad32) | Unused GPIO; retain default strap states on GPIO3/45/46
U1 | 33 | GPIO37 | unconnected-(U1-IO37-Pad33) | Unused GPIO; retain default strap states on GPIO3/45/46
U1 | 34 | GPIO38 | /CHG_STAT
U1 | 35 | GPIO39 | unconnected-(U1-IO39-Pad35) | Unused GPIO; retain default strap states on GPIO3/45/46
U1 | 36 | GPIO40 | unconnected-(U1-IO40-Pad36) | Unused GPIO; retain default strap states on GPIO3/45/46
U1 | 37 | GPIO41 | unconnected-(U1-IO41-Pad37) | Unused GPIO; retain default strap states on GPIO3/45/46
U1 | 38 | GPIO42 | unconnected-(U1-IO42-Pad38) | Unused GPIO; retain default strap states on GPIO3/45/46
U1 | 39 | TXD0/GPIO43 | unconnected-(U1-TXD0-Pad39) | Unused GPIO; retain default strap states on GPIO3/45/46
U1 | 40 | RXD0/GPIO44 | unconnected-(U1-RXD0-Pad40) | Unused GPIO; retain default strap states on GPIO3/45/46
U1 | 41 | GPIO45 | unconnected-(U1-IO45-Pad41) | Unused GPIO; retain default strap states on GPIO3/45/46
U1 | 42 | GND | GND
U1 | 43 | GND | GND
U1 | 44 | GPIO46 | unconnected-(U1-IO46-Pad44) | Unused GPIO; retain default strap states on GPIO3/45/46
U1 | 45 | EN | Net-(U1-EN)
U1 | 46 | GND | GND
U1 | 47 | GND | GND
U1 | 48 | GND | GND
U1 | 49 | GND | GND
U1 | 50 | GND | GND
U1 | 51 | GND | GND
U1 | 52 | GND | GND
U1 | 53 | GND | GND
U1 | 54 | GND | GND
U1 | 55 | GND | GND
U1 | 56 | GND | GND
U1 | 57 | GND | GND
U1 | 58 | GND | GND
U1 | 59 | GND | GND
U1 | 60 | GND | GND
U1 | 61 | GND | GND
U1 | 62 | GND | GND
U1 | 63 | GND | GND
U1 | 64 | GND | GND
U1 | 65 | GND | GND
U2 | 1 | SDO/SA0 | /ACCEL_MISO
U2 | 2 | RES->VDDIO_or_GND | GND
U2 | 3 | RES->VDDIO_or_GND | GND
U2 | 4 | INT1 | /ACCEL_DRDY
U2 | 5 | VDD_IO | /+3V3
U2 | 6 | GND | GND
U2 | 7 | GND | GND
U2 | 8 | VDD | /+3V3
U2 | 9 | INT2 | unconnected-(U2-INT2-Pad9) | INT2 unused
U2 | 10 | RES->VDDIO_or_open | unconnected-(U2-RES-Pad10) | Reserved pad: leave unconnected per ST DS12569
U2 | 11 | RES->VDDIO_or_open | unconnected-(U2-RES-Pad11) | Reserved pad: leave unconnected per ST DS12569
U2 | 12 | CS | /ACCEL_CS
U2 | 13 | SPC/SCL | /ACCEL_SCK
U2 | 14 | SDI/SDA | /ACCEL_MOSI
U3 | 1 | NC | unconnected-(U3-NC-Pad1) | No internal connection per TI
U3 | 2 | GND | GND
U3 | 3 | VIN | Net-(U3-VR_IN)
U3 | 4 | NC | unconnected-(U3-NC-Pad4) | No internal connection per TI
U3 | 5 | MODE | unconnected-(U3-MODE-Pad5) | Intentional open selects adaptive Mode 1 per TI; not a missing bias
U3 | 6 | NC | unconnected-(U3-NC-Pad6) | No internal connection per TI
U3 | 7 | PEAK_DETECTOR | Net-(U3-PEAK_DET)
U3 | 8 | VCC | /+3V3
U3 | 9 | TIMING_INPUT | GND
U3 | 10 | GATED_OUTPUT | unconnected-(U3-GATED_OUT-Pad10) | Unused gated output; using open-collector reference pulse on pin 12
U3 | 11 | INPUT_SELECT | GND
U3 | 12 | REFERENCE_PULSE_OC | /MAG_TACH
U3 | 13 | NC | unconnected-(U3-NC-Pad13) | No internal connection per TI
U3 | 14 | RC_TIMING | Net-(U3-RC_TIMING)
U5 | 1 | TS | /TS
U5 | 2 | BAT | /BAT
U5 | 3 | BAT | /BAT
U5 | 4 | CE | GND
U5 | 5 | EN2 | /CHG_EN2
U5 | 6 | EN1 | /CHG_EN1
U5 | 7 | PGOOD | /PGOOD_N
U5 | 8 | VSS | GND
U5 | 9 | CHG | /CHG_STAT
U5 | 10 | OUT | /SYS
U5 | 11 | OUT | /SYS
U5 | 12 | ILIM | /ILIM
U5 | 13 | IN | /USB_VBUS
U5 | 14 | TMR | unconnected-(U5-TMR-Pad14) | TMR left open: sets the default pre-charge and fast-charge safety timers (SLUS810N Table 7-1)
U5 | 15 | SYSOFF | GND
U5 | 16 | ISET | /ISET
U5 | 17 | EP_VSS | GND
U6 | 1 | VOUT | /+3V3
U6 | 2 | L2 | Net-(U6-L2)
U6 | 3 | PGND | GND
U6 | 4 | L1 | Net-(U6-L1)
U6 | 5 | VIN | /SYS_SW
U6 | 6 | EN | /SYS_SW
U6 | 7 | PS/SYNC | /SYS_SW
U6 | 8 | VINA | /SYS_SW
U6 | 9 | GND | GND
U6 | 10 | FB | /+3V3
U6 | 11 | EXPOSED_PAD/PGND | GND
U7 | 1 | I/O | /USB_CONN_D-
U7 | 2 | VN/GND | GND
U7 | 3 | I/O | /USB_CONN_D+
U7 | 4 | I/O | /USB_CONN_D+
U7 | 5 | VP | /USB_VBUS
U7 | 6 | I/O | /USB_CONN_D-
U9 | 1 | A | /OPT_COMP
U9 | 2 | B | Net-(C26-Pad1)
U9 | 3 | GND | GND
U9 | 4 | Y | Net-(U10-~{A})
U9 | 5 | VCC | /+3V3
U10 | 1 | A | Net-(U10-~{A})
U10 | 2 | B | /+3V3
U10 | 3 | CLR | /+3V3
U10 | 4 | GND | GND
U10 | 5 | Q | /OPT_TACH
U10 | 6 | Cext | Net-(U10-Cext)
U10 | 7 | Rext/Cext | Net-(U10-RCext)
U10 | 8 | VCC | /+3V3

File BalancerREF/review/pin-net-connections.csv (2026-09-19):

Reference | Pin | Net
C1 | 1 | /USB_VBUS
C1 | 2 | GND
C10 | 1 | Net-(U1-EN)
C10 | 2 | GND
C11 | 1 | /ACQUIRE_BUTTON
C11 | 2 | GND
C12 | 1 | /SUPPLY_SENSE
C12 | 2 | GND
C13 | 1 | /+3V3
C13 | 2 | GND
C14 | 1 | /+3V3
C14 | 2 | GND
C15 | 1 | /+3V3
C15 | 2 | GND
C16 | 1 | /+3V3
C16 | 2 | GND
C17 | 1 | /+3V3
C17 | 2 | GND
C18 | 1 | Net-(U3-RC_TIMING)
C18 | 2 | GND
C19 | 1 | Net-(U3-PEAK_DET)
C19 | 2 | GND
C2 | 1 | /USB_VBUS
C2 | 2 | GND
C26 | 1 | Net-(C26-Pad1)
C26 | 2 | GND
C27 | 1 | /+3V3
C27 | 2 | GND
C28 | 1 | Net-(U10-RCext)
C28 | 2 | Net-(U10-Cext)
C29 | 1 | /+3V3
C29 | 2 | GND
C3 | 1 | /BAT
C3 | 2 | GND
C30 | 1 | /SYS
C30 | 2 | GND
C4 | 1 | /SYS_SW
C4 | 2 | GND
C5 | 1 | /SYS_SW
C5 | 2 | GND
C6 | 1 | /+3V3
C6 | 2 | GND
C7 | 1 | /+3V3
C7 | 2 | GND
C8 | 1 | /+3V3
C8 | 2 | GND
C9 | 1 | /+3V3
C9 | 2 | GND
D3 | 1 | /USB_VBUS
D3 | 2 | GND
J1 | A1 | GND
J1 | A12 | GND
J1 | A4 | /USB_VBUS
J1 | A5 | Net-(J1-CC1)
J1 | A6 | /USB_CONN_D+
J1 | A7 | /USB_CONN_D-
J1 | A8 | unconnected-(J1-SBU1-PadA8)
J1 | A9 | /USB_VBUS
J1 | B1 | GND
J1 | B12 | GND
J1 | B4 | /USB_VBUS
J1 | B5 | Net-(J1-CC2)
J1 | B6 | /USB_CONN_D+
J1 | B7 | /USB_CONN_D-
J1 | B8 | unconnected-(J1-SBU2-PadB8)
J1 | B9 | /USB_VBUS
J1 | SH | GND
J2 | 1 | Net-(J2-Pin_1)
J2 | 2 | GND
J3 | 1 | Net-(J3-Pin_1)
J3 | 2 | GND
J4 | 1 | /+3V3
J4 | 2 | GND
J4 | 3 | /GPS_UART_RX
J4 | 4 | /GPS_UART_TX
J4 | 5 | /GPS_PPS
J5 | 1 | /SYS_SW
J5 | 2 | GND
J5 | 3 | /OPT_LED_EN
J5 | 4 | GND
J5 | 5 | /OPT_COMP
J5 | 6 | GND
J5 | 7 | /+3V3
L1 | 1 | Net-(U6-L1)
L1 | 2 | Net-(U6-L2)
LED1 | 1 | GND
LED1 | 2 | Net-(LED1-A)
Q4 | 1 | GND
Q4 | 2 | /BAT
Q4 | 3 | Net-(J2-Pin_1)
R1 | 1 | GND
R1 | 2 | Net-(J1-CC1)
R10 | 1 | /STATUS_LED
R10 | 2 | Net-(LED1-A)
R11 | 1 | /SYS_SW
R11 | 2 | /SUPPLY_SENSE
R12 | 1 | /SUPPLY_SENSE
R12 | 2 | GND
R13 | 1 | Net-(R13-Pad1)
R13 | 2 | Net-(J3-Pin_1)
R14 | 1 | Net-(U3-VR_IN)
R14 | 2 | Net-(R13-Pad1)
R15 | 1 | /+3V3
R15 | 2 | /MAG_TACH
R16 | 1 | /+3V3
R16 | 2 | Net-(U3-RC_TIMING)
R17 | 1 | Net-(U3-PEAK_DET)
R17 | 2 | GND
R2 | 1 | GND
R2 | 2 | Net-(J1-CC2)
R29 | 1 | Net-(C26-Pad1)
R29 | 2 | /OPT_LED_EN
R3 | 1 | /ISET
R3 | 2 | GND
R30 | 1 | /+3V3
R30 | 2 | Net-(U10-RCext)
R35 | 1 | /ILIM
R35 | 2 | GND
R36 | 1 | /TS
R36 | 2 | GND
R37 | 1 | /+3V3
R37 | 2 | /PGOOD_N
R38 | 1 | /+3V3
R38 | 2 | /CHG_STAT
R39 | 1 | GND
R39 | 2 | /OPT_COMP
R4 | 1 | /+3V3
R4 | 2 | Net-(U1-EN)
R6 | 1 | /USB_CONN_D-
R6 | 2 | Net-(U1-USB_D-)
R7 | 1 | /USB_CONN_D+
R7 | 2 | Net-(U1-USB_D+)
R8 | 1 | /+3V3
R8 | 2 | /ACQUIRE_BUTTON
R9 | 1 | /+3V3
R9 | 2 | /BOOT
SW1 | 1 | /SYS
SW1 | 2 | /SYS_SW
SW2 | 1 | GND
SW2 | 2 | /ACQUIRE_BUTTON
SW3 | 1 | GND
SW3 | 2 | /BOOT
TP1 | 1 | /+3V3
TP10 | 1 | /ACCEL_DRDY
TP2 | 1 | GND
TP3 | 1 | /BAT
TP7 | 1 | /MAG_TACH
TP9 | 1 | /OPT_TACH
U1 | 1 | GND
U1 | 10 | /ACCEL_DRDY
U1 | 11 | /MAG_TACH
U1 | 12 | /OPT_TACH
U1 | 13 | /OPT_LED_EN
U1 | 14 | /ACQUIRE_BUTTON
U1 | 15 | /STATUS_LED
U1 | 16 | /SUPPLY_SENSE
U1 | 17 | /GPS_PPS
U1 | 18 | /ACCEL_SCK
U1 | 19 | /ACCEL_MOSI
U1 | 2 | GND
U1 | 20 | /ACCEL_MISO
U1 | 21 | /ACCEL_CS
U1 | 22 | /CHG_EN2
U1 | 23 | Net-(U1-USB_D-)
U1 | 24 | Net-(U1-USB_D+)
U1 | 25 | /PGOOD_N
U1 | 26 | unconnected-(U1-IO26-Pad26)
U1 | 27 | unconnected-(U1-IO47-Pad27)
U1 | 28 | unconnected-(U1-IO33-Pad28)
U1 | 29 | unconnected-(U1-IO34-Pad29)
U1 | 3 | /+3V3
U1 | 30 | unconnected-(U1-IO48-Pad30)
U1 | 31 | unconnected-(U1-IO35-Pad31)
U1 | 32 | unconnected-(U1-IO36-Pad32)
U1 | 33 | unconnected-(U1-IO37-Pad33)
U1 | 34 | /CHG_STAT
U1 | 35 | unconnected-(U1-IO39-Pad35)
U1 | 36 | unconnected-(U1-IO40-Pad36)
U1 | 37 | unconnected-(U1-IO41-Pad37)
U1 | 38 | unconnected-(U1-IO42-Pad38)
U1 | 39 | unconnected-(U1-TXD0-Pad39)
U1 | 4 | /BOOT
U1 | 40 | unconnected-(U1-RXD0-Pad40)
U1 | 41 | unconnected-(U1-IO45-Pad41)
U1 | 42 | GND
U1 | 43 | GND
U1 | 44 | unconnected-(U1-IO46-Pad44)
U1 | 45 | Net-(U1-EN)
U1 | 46 | GND
U1 | 47 | GND
U1 | 48 | GND
U1 | 49 | GND
U1 | 5 | /GPS_UART_TX
U1 | 50 | GND
U1 | 51 | GND
U1 | 52 | GND
U1 | 53 | GND
U1 | 54 | GND
U1 | 55 | GND
U1 | 56 | GND
U1 | 57 | GND
U1 | 58 | GND
U1 | 59 | GND
U1 | 6 | /GPS_UART_RX
U1 | 60 | GND
U1 | 61 | GND
U1 | 62 | GND
U1 | 63 | GND
U1 | 64 | GND
U1 | 65 | GND
U1 | 7 | unconnected-(U1-IO3-Pad7)
U1 | 8 | unconnected-(U1-IO4-Pad8)
U1 | 9 | /CHG_EN1
U10 | 1 | Net-(U10-~{A})
U10 | 2 | /+3V3
U10 | 3 | /+3V3
U10 | 4 | GND
U10 | 5 | /OPT_TACH
U10 | 6 | Net-(U10-Cext)
U10 | 7 | Net-(U10-RCext)
U10 | 8 | /+3V3
U2 | 1 | /ACCEL_MISO
U2 | 10 | unconnected-(U2-RES-Pad10)
U2 | 11 | unconnected-(U2-RES-Pad11)
U2 | 12 | /ACCEL_CS
U2 | 13 | /ACCEL_SCK
U2 | 14 | /ACCEL_MOSI
U2 | 2 | GND
U2 | 3 | GND
U2 | 4 | /ACCEL_DRDY
U2 | 5 | /+3V3
U2 | 6 | GND
U2 | 7 | GND
U2 | 8 | /+3V3
U2 | 9 | unconnected-(U2-INT2-Pad9)
U3 | 1 | unconnected-(U3-NC-Pad1)
U3 | 10 | unconnected-(U3-GATED_OUT-Pad10)
U3 | 11 | GND
U3 | 12 | /MAG_TACH
U3 | 13 | unconnected-(U3-NC-Pad13)
U3 | 14 | Net-(U3-RC_TIMING)
U3 | 2 | GND
U3 | 3 | Net-(U3-VR_IN)
U3 | 4 | unconnected-(U3-NC-Pad4)
U3 | 5 | unconnected-(U3-MODE-Pad5)
U3 | 6 | unconnected-(U3-NC-Pad6)
U3 | 7 | Net-(U3-PEAK_DET)
U3 | 8 | /+3V3
U3 | 9 | GND
U5 | 1 | /TS
U5 | 10 | /SYS
U5 | 11 | /SYS
U5 | 12 | /ILIM
U5 | 13 | /USB_VBUS
U5 | 14 | unconnected-(U5-TMR-Pad14)
U5 | 15 | GND
U5 | 16 | /ISET
U5 | 17 | GND
U5 | 2 | /BAT
U5 | 3 | /BAT
U5 | 4 | GND
U5 | 5 | /CHG_EN2
U5 | 6 | /CHG_EN1
U5 | 7 | /PGOOD_N
U5 | 8 | GND
U5 | 9 | /CHG_STAT
U6 | 1 | /+3V3
U6 | 10 | /+3V3
U6 | 11 | GND
U6 | 2 | Net-(U6-L2)
U6 | 3 | GND
U6 | 4 | Net-(U6-L1)
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

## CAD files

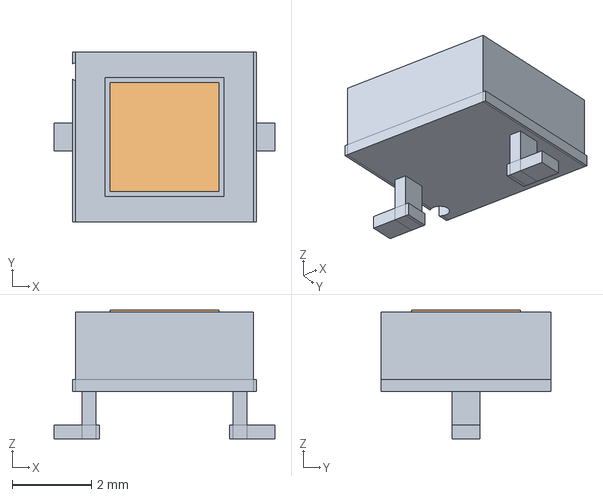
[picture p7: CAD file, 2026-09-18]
BalancerREF_OptHead/3dmodels/Osram_SFH2440.step
5.58 x 4.30 x 3.25 mm

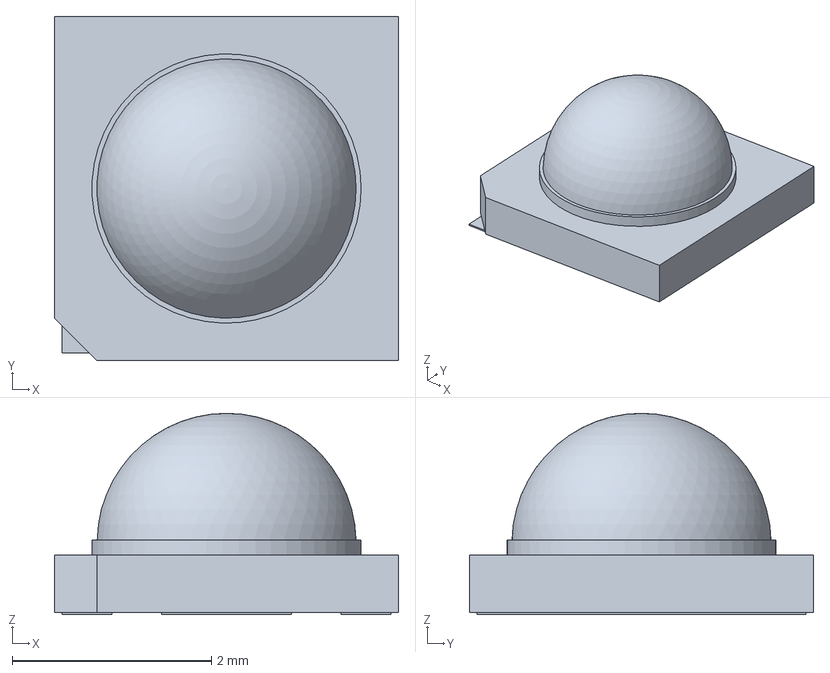
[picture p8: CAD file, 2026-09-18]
BalancerREF_OptHead/3dmodels/LED_Cree-XP.step
3.45 x 3.45 x 2.02 mm

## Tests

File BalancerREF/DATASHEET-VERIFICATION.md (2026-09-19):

# Manufacturer pinout verification

Reviewed 2026-09-07 against the manufacturer documents below. `review/IC-pin-audit.csv` records all 118 IC pads and their actual KiCad-exported nets, including all 65 ESP32 module pads. The electrical net specification is separately checked by `scripts/verify_netlist.py`.

## U1 — Espressif ESP32-S3-MINI-1-N8

[Current manufacturer datasheet, v1.7](https://documentation.espressif.com/esp32-s3-mini-1_mini-1u_datasheet_en.pdf), pin table on pages 11–12, USB/peripheral descriptions and peripheral schematic. Original PDF saved in `sources/`.

Verified pad 3 = 3V3, 4 = GPIO0, 23 = GPIO19/USB D-, 24 = GPIO20/USB D+, 45 = EN. Ground pads are 1, 2, 42, 43 and 46–65; the normal KiCad symbol stacks these ground pins, and all are present in the exported netlist. The CSV verifies the remaining GPIO/pad mapping individually. N8 is the 8 MB flash / no PSRAM version. GPIO3/45/46 remain unloaded, preserving strap defaults.

Local 10 µF and 100 nF bypass; EN has 10 kΩ / 1 µF (the reset button was removed in Rev D; SW1 power-cycles the regulator). GPIO0 has a 10 kΩ pull-up and a service BOOT button. Native USB uses 22 Ω series resistors close to the MCU. `SUPPLY_SENSE` is a 100 kΩ/100 kΩ divider from SYS_SW to GPIO12; it is not a VBUS detect (PGOOD is). Normal operation uses BLE; firmware routes tach edges to capture hardware through the GPIO matrix.

## U2 — ST LIS2DW12TR (superseded)

> **Replaced in Rev C by the IIS3DWBTR on SPI.** The current pin table is under "Rev C parts" below. Kept for history.

[Manufacturer datasheet DS11811 Rev 9, September 2024](https://www.st.com.cn/resource/en/datasheet/lis2dw12.pdf), pin table page 4, application figure 6/page 19. Verified through the manufacturer's current web PDF; direct local download timed out.

| Pad | Function / connection |
|---:|---|
| 1 | SCL, 4.7 kΩ pull-up |
| 2 | CS tied to VDD_IO for I2C |
| 3 | SA0 tied to ground, address 0x18 |
| 4 | SDA, 4.7 kΩ pull-up |
| 5 | Internal NC, explicitly unused |
| 6, 8 | Ground |
| 7 | Reserved: must connect to ground |
| 9 | VDD, local 100 nF plus 10 µF bulk |
| 10 | VDD_IO, local 100 nF |
| 11 | INT2 unused; retain output configuration |
| 12 | INT1 / data-ready to GPIO6 |

Both supplies use 3.3 V. Ceramic bulk is specified with adequate effective capacitance at bias. All three accelerometer axes are available over I2C. High-performance/low-noise mode and output/filter rates are firmware settings.

## U3 — TI LM1815MX/NOPB

[Manufacturer datasheet SNOSBU8F](https://www.ti.com/lit/ds/symlink/lm1815.pdf), connection diagram page 1, reference circuit figure 17/page 6 and application details pages 8–9. Original PDF saved.

Pins: 1/4/6/13 NC; 2 ground; 3 signal input; 5 mode; 7 peak storage; 8 VCC; 9 timing input; 10 gated output; 11 input select; 12 open-collector reference pulse; 14 RC timing.

3.3 V lies within the electrical-table 2.5–12 V operating range. Mode pin 5 is intentionally open for adaptive Mode 1. Pins 9/11 are grounded; pin 10 is unused. Pin 12 has a 5.6 kΩ pull-up to 3.3 V. Local 100 nF + 10 µF bypass supports the internal input clamp.

Two 10 kΩ pulse-rated series resistors give 20 kΩ; ±60 V peak produces at most approximately 3 mA into the internal clamp. This is a design envelope, not a qualified surge rating. 150 kΩ and 1 nF give 0.673RC ≈101 µs pulse width; 1.6 MΩ / 330 nF follow TI's peak-storage network. Timestamp the falling leading edge of the output pulse.

## U4 — ST TS3021IYLT

> The paragraph below describes the Rev B phototransistor front end with a trimpot. Since Rev C the comparator sees `OPT_AMP` on IN- against a fixed R26/R27 threshold (1.016 V) on IN+, with R28 470 kΩ hysteresis; see "Rev F — PD1 polarity" below for the current chain.

[Manufacturer datasheet DS4807 Rev 11, August 2025](https://www.st.com.cn/resource/en/datasheet/ts3021.pdf), page 2 pin table. Verified through the manufacturer's current web PDF; direct local download timed out.

SOT-23-5: 1 OUT, 2 VCC-, 3 IN+, 4 IN-, 5 VCC+. Powered from 3.3 V with local 100 nF; output is push-pull. The local symbol uses the normal comparator triangle and this pin mapping.

Phototransistor raw collector voltage feeds IN-. RV1 feeds IN+; 470 kΩ output feedback produces positive hysteresis. At mid-trim, the divider Thevenin resistance is about 4.85 kΩ; ideal hysteresis is 3.3 × 4.85/(470 + 4.85) ≈34 mV. The threshold adjusts approximately 0.8–2.5 V, with small feedback shifts. This is manually adjustable ambient thresholding, not automatic ambient subtraction.

## U5 — TI BQ24075RGT

[Manufacturer datasheet SLUS810N, September 2008 – revised October 2021](https://www.ti.com/lit/ds/symlink/bq24075.pdf), Table 7-1 (pin functions), Table 7-2 (EN1/EN2), Section 6 (device comparison table) and Section 8.5 (electrical characteristics). Original PDF saved as `sources/BQ24075.pdf`.

Package is RGT0016C, VQFN-16 3x3 mm with a thermal pad. Figure 7-3 is the BQ24075 top view; every pin below was read from it and from Table 7-1.

| Pin | Name | Net | Check against SLUS810N |
|---|---|---|---|
| 1 | TS | `/TS`, R36 10k to GND | Table 7-1: "For applications that do not use the TS function, connect a 10-kΩ fixed resistor from TS to VSS". Exactly that — there is no thermistor in the pack. |
| 2, 3 | BAT | `/BAT`, C3 10 µF | Spec asks 4.7–47 µF ceramic. C3 is 10 µF 10 V; derating at 4.2 V must leave at least 4.7 µF effective. |
| 4 | CE | GND | Active low. "Connect CE to a low logic level to enable the battery charger." Tied low, so charging cannot be disabled by firmware — deliberate. Has a ~285 kΩ internal pulldown but must not be left floating. |
| 5 | EN2 | `/CHG_EN2` → U1 pad 22 = GPIO18 | Input current limit select, Table 7-2. |
| 6 | EN1 | `/CHG_EN1` → U1 pad 9 = GPIO5 | Both EN pins have ~285 kΩ internal pulldowns, so the limit defaults to EN2=0/EN1=0 = USB100 = 100 mA until firmware drives them. |
| 7 | PGOOD | `/PGOOD_N` → U1 pad 25 = GPIO21, R37 100k to +3V3 | Open drain; pulls low when a valid input source is present. Spec asks a 1 kΩ–100 kΩ pull-up and 100k is the top of that range, chosen for standby current. |
| 8 | VSS | GND | "VSS pin must be connected to ground at all times" — the thermal pad alone does not satisfy this. |
| 9 | CHG | `/CHG_STAT` → U1 pad 34 = GPIO38, R38 100k to +3V3 | Open drain; low while charging, high impedance when charge completes **and** when the charger is disabled. Not an input-present signal on its own. |
| 10, 11 | OUT | `/SYS`, C30 10 µF | System supply output. Spec asks 4.7–47 µF. |
| 12 | ILIM | `/ILIM`, R35 1.6k to GND | Spec range 1100 Ω to 8 kΩ. I(IN-MAX) = KILIM/RILIM, KILIM typ 1610 AΩ (1500–1720), so 1610/1600 ≈ **1.01 A** typ and 0.94–1.08 A across the spread. Active only in the EN2=1/EN1=0 state. **Leaving ILIM open disables all charging**, so this resistor is not optional. |
| 13 | IN | `/USB_VBUS`, C1 100 nF + C2 10 µF | Input range 4.35–6.6 V, OVP at 6.6 V; survives 26 V without damage but suspends. Spec asks 1–10 µF bypass. |
| 14 | TMR | open | "Leave TMR unconnected to set the timers to the default values." Intentional — the default pre-charge and fast-charge safety timers are what is wanted. |
| 15 | SYSOFF | GND | BQ24075-specific pin. "Connect SYSOFF low for normal operation." It is internally pulled **up** to VBAT through ~5 MΩ, so grounding it is required rather than conventional: floating, the battery would be disconnected from OUT. |
| 16 | ISET | `/ISET`, R3 3.57k 1% to GND | Spec range 590 Ω to 8.9 kΩ. I(CHG) = KISET/RISET, KISET typ 890 AΩ (797–975), so 890/3570 ≈ **249 mA** typ and 223–273 mA across the spread — about 0.5C for a 500 mAh cell. **Charging is disabled if ISET is left unconnected.** |
| 17 | EP | GND | "There is an internal electrical connection between the exposed thermal pad and the VSS pin... Do not use the thermal pad as the primary ground input." Both EP and pin 8 go to GND. |

Table 7-2 is indexed **(EN2, EN1)** — the reverse of the order the pins are named in, which is an easy way to set the wrong limit:

| EN2 | EN1 | Maximum input current into IN |
|---|---|---|
| 0 | 0 | 100 mA, USB100 — the power-on default from the internal pulldowns |
| 0 | 1 | 500 mA, USB500 |
| 1 | 0 | Set by RILIM: 1.6 kΩ → about 1.0 A |
| 1 | 1 | Standby (USB suspend) |

**SYS rail voltage — check this on the bench.** V(OUT-REG) is 5.5 V and V(DPPM) is 4.3 V (Section 6). SYS feeds U6, and the TPS63031's recommended supply is 1.8–5.5 V with an absolute maximum of 7 V. Removing the old Schottky D2 raised SYS by that diode's forward drop, so a 5.0 V port now puts roughly 4.9–5.0 V on SYS instead of about 4.55 V. That is still inside the TPS63031's recommended range, and the behaviour above it improved: OUT regulates at 5.5 V rather than passing the input through, and the input OVPs at 6.6 V, where the diode would have handed a 7 V supply to the regulator at about 6.55 V. Steady-state headroom went down, the failure mode got safer. Measure SYS with a high-end-of-spec 5.25 V source before trusting it.

When the input is out of range, OUT is connected to VBAT (unless SYSOFF is high). That is what makes `SUPPLY_SENSE` on SYS_SW a battery reading while running unplugged — and why it is not one while charging.

## U9 — TI SN74LVC1G132 (was SN74LVC1G08)

[Manufacturer datasheet SLVS322](https://www.ti.com/lit/ds/symlink/sn74lvc1g132.pdf), Pin Functions table and Figure 4-1. Original PDF saved as `sources/SN74LVC1G132.pdf`.

DBV (SOT-23-5): 1 A, 2 B, 3 GND, 4 Y, 5 VCC — **identical to the SN74LVC1G08 it replaces**, so the footprint, the supply pins and the board land pattern are untouched.

Why it changed: R29/C26 form a 0.47 µs RC delay feeding this gate. The SN74LVC1G08 specifies a maximum input transition rate of 10 ns/V; that edge crosses the logic threshold region at roughly 250 ns/V, about 25× outside the datasheet. An LVC input driven slowly through its linear region can oscillate and draws shoot-through current. The 1G132 has Schmitt-trigger inputs and conditions **both** inputs, not just the RC branch.

It is a NAND, so Y now falls on a detection where the AND rose. U10's trigger moved to match:

| | before | after |
|---|---|---|
| U10 pin 1 (~A) | GND | U9 Y |
| U10 pin 2 (B) | U9 Y | +3V3 |
| triggers on | B rising, ~A low | ~A falling, B high |

The SN74LVC1G123 supports both edges, so this is a rewire rather than a redesign. Idle state is unchanged: with no emitter pulse, or a pulse with no tape return, Y sits high and ~A sees no falling edge.

## U6 — TI TPS63031DSKR

[Manufacturer datasheet SLVS696D](https://www.ti.com/lit/ds/symlink/tps63031.pdf), pin table/page 3 and fixed-output reference circuit. Original PDF saved.

1 VOUT; 2 L2; 3 PGND; 4 L1; 5 VIN; 6 EN; 7 PS/SYNC; 8 VINA; 9 GND; 10 FB; exposed pad represented by KiCad pad 11, tied to PGND. VIN/VINA/EN/PS-SYNC connect to switched SYS power (USB or battery). PS/SYNC high forces PWM. L1/L2 connect only through the 1.5 µH Murata DFE201612PD-1R5M=P2. FB connects directly to VOUT for fixed 3.3 V operation.

Input 10 µF + 100 nF are between SYS_SW and ground. Two 22 µF nominal output ceramics are between 3.3 V and ground, with at least 20 µF total effective capacitance required. All three ground/thermal pads join common ground. The net verifier explicitly checks both switching-node nets and every capacitor terminal.

## U7 — onsemi SRV05-4MR6T1G, USB ESD equivalent

[Manufacturer datasheet SRV05-4/D Rev 4, October 2024](https://www.onsemi.com/pdf/datasheet/srv05-4-d.pdf), page 1 pin diagram and USB application. Verified from manufacturer web PDF. This is the selected equivalent to the requested SRV05-4A.

1/3/4/6 are independent protected I/O channels; 2 is VN/ground; 5 is VP. VP connects to USB VBUS with 100 nF bypass. The ordinary KiCad SRV05-4 symbol has the matching electrical pinout.

*Rev G (2026-09-19, from Reddit review):* pins 4 and 6 are no longer NC. In the TSOP-6/SOT-23-6 package pin 6 sits directly across from pin 1 and pin 4 across from pin 3, which is the flow-through layout the datasheet's USB application uses: the data trace enters one pad and leaves the opposite one, so the protected line has no stub. D- goes in at pin 1 and out at pin 6, D+ in at pin 3 and out at pin 4. The SRV05-4 has no internal I/O-to-I/O connection (Figure 8 equivalent circuit: steering diodes to VP/VN only), so both pads of each pair carry the SAME net and the PCB trace itself must join them. Giving the two sides different net names would pass DRC with an open circuit. Routing that pass-through is still to do on the board.

## Other pin and lead checks

- [AO3400A manufacturer datasheet, Rev 3.1](https://www.aosmd.com/sites/default/files/res/datasheets/AO3400A.pdf): SOT-23 top-view gate 1, source 2, drain 3. Its 2.5 V gate-drive specification supports 3.3 V drive. Local PDF saved.
- [GCT USB4105 drawing](https://gct.co/files/drawings/usb4105.pdf): USB 2.0 16-contact version, joined A6/B6 D+, joined A7/B7 D-, separate CC1/CC2 5.1 kΩ resistors, all VBUS/ground contacts and shield included. Local drawing saved.
- *(Rev B part, removed in Rev C)* [LTR-4206E manufacturer lead drawing, distributor mirror](https://media.digikey.com/pdf/Data%20Sheets/Lite-On%20PDFs/LTR-4206E.pdf): lead 1 emitter, lead 2 collector; flat indicates collector. The matching normal `Q_Photo_NPN_EC` symbol is used. Current [Lite-On Rev D link](https://optoelectronics.liteon.com/upload/download/DS-50-92-0073/LTR-4206E%20Data%20Sheet%20%20Rev.D.PDF) was identified but direct retrieval was blocked; the available manufacturer-authored lead drawing is archived. Final formed-lead footprint remains a PCB-stage task.
- *(Rev B part, removed in Rev C)* [LTE-4208 manufacturer lead drawing, distributor mirror](https://media.digikey.com/pdf/Data%20Sheets/Lite-On%20PDFs/LTE-4208.pdf): long lead anode, short/flat-side lead cathode. The schematic uses KiCad LED numbering 1 cathode / 2 anode; preserve this convention when creating the later footprint. Current [Lite-On Ver D link](https://optoelectronics.liteon.com/upload/download/DS-50-92-0015/LTE-4208%20Data%20Sheet%20Ver%20D.PDF) was identified but retrieval was blocked. Archived manufacturer drawing verifies lead polarity.

## ERC and unused-pin treatment

Only three electrically justified PWR_FLAG symbols are used: external USB VBUS, external/common ground, and switched SYS supply after the passive power switch. Neither converter output nor battery/charger node is given a redundant flag. NC markers identify unused module GPIOs, USB SBU contacts, spare ESD channels, the BQ24075 TMR pin, and the documented LM1815 unused/open-mode pins. The charger status pins are no longer among them: the BQ24075 drives PGOOD and CHG into GPIOs. As of Rev E the sheet also has no dangling wire stubs, so ERC is clean at 0 errors and 0 warnings. See the CSV/JSON audit for each case. ERC has no exclusions or disabled checks.

## Revision B — charging independent of SW1

> **Superseded in Rev E.** D2, Q3, R27 and R31 were removed when the MCP73831 gave
> way to the BQ24075, whose integrated DPPM power path does this internally and better:
> no diode drop, and the system runs with a defective or absent cell. Kept as the record
> of what the discrete topology was and why.

[Microchip AN1149, DS01149C, figures 5–7](https://ww1.microchip.com/downloads/en/AppNotes/01149c.pdf) supplies the directional-control topology. Charger VDD remains on USB_VBUS and VBAT remains on BAT. The USB Schottky feeds SYS; the P-channel MOSFET has drain on BAT, source on SYS and gate on USB_VBUS. SW1 connects SYS to SYS_SW. With valid USB, Q3 is OFF and USB supplies the load separately from the battery charging node. Without USB, R27 pulls Q3 gate down and the battery supplies SYS. Local application-note PDF saved.

- Q3 [AO3401A, manufacturer Rev 3.1 December 2023](https://www.aosmd.com/sites/default/files/res/datasheets/AO3401A.pdf): SOT-23 top view verified against standard library/footprint: 1 gate, 2 source, 3 drain. Maximum RDS(on) 85 milliohms at VGS=-2.5 V. The body diode points BAT to SYS; reversing source/drain would defeat USB isolation. Local PDF and pin drawing saved.
- D2 [Nexperia PMEG4010CEH, 12 October 2023 v3](https://assets.nexperia.com/documents/data-sheet/PMEG4010CEH.pdf): pin 1 cathode to SYS, pin 2 anode to USB_VBUS; SOD123F, 40 V, 1 A. Manufacturer web PDF verified; direct local download returned 403. Maximum pulsed VF at 25 C is 490 mV at 500 mA, 570 mV at 1 A. Provide thermal copper and verify operating temperature/current on the PCB.
- R27=1 kilohm gate pulldown uses about 5 mA/25 mW with 5 V USB. This is deliberately stronger than AN1149's typical 100 kilohms, limiting gate voltage caused by Schottky reverse leakage and speeding release at unplug. Temperature-dependent leakage and handover remain bench checks.
- C21=10 microfarads, 10 V X7R from SYS to common ground. C4/C5 remain on SYS_SW, never a switching node. USB must remain within the TPS63031 5.5 V input limit; use regulated 5 V only.
- R11/R12 now sense SYS_SW/2 on GPIO12, avoiding a direct USB-to-unpowered-GPIO divider path when OFF. Firmware must use SUPPLY_SENSE rather than treating GPIO12 as binary USB presence.

Expected states: USB absent/OFF = puck off; USB absent/ON = battery powers puck; USB present/OFF = battery charges, puck off; USB present/ON = USB powers puck and charger. Charge current remains approximately 249 mA, subject to charger thermal regulation and available USB current. Switch position does not interrupt the charger-to-battery path. All four cases require physical prototype confirmation, including USB handover, input droop and charge termination.

## J4 GPS header (2026-09-07)

Generic 1x05 2.54 mm header; no manufacturer pinout to verify. Assignment follows the common u-blox breakout order VCC, GND, TX, RX, PPS. GPIO1/GPIO2 are ordinary IOs on the ESP32-S3-MINI-1 (pads 5/6) routed to UART1 through the GPIO matrix; GPIO13 (pad 17) is the PPS input. GPIO3/45/46 strapping pins remain unloaded. Module must be 3.3 V logic and is supplied from the 3.3 V rail (about 30 mA active).

## Rev F — PD1 polarity, and why nothing caught it

**The optical comparator could never trip.** From the original design through Rev E, PD1
was wired cathode to +3V3 and anode to the transimpedance summing node. The reverse bias
is correct that way — 1.65 V, cathode positive — which is presumably why it survived
review. The signal direction is not.

Photocurrent in a reverse-biased photodiode leaves the **anode** terminal. With the anode
on the summing node it is injected *into* the node, and the chain runs backwards from
there:

| stage | wiring | response to light |
|---|---|---|
| PD1 | anode on the node | current **into** the summing node |
| U8A TIA | `U8.2` is IN-, `U8.3` is the 1.65 V reference — inverting | `TIA_OUT` **falls** |
| U8B | inverting, gain -R23/R22 = -120k/10k = -12 | `OPT_AMP` **rises** from 1.65 V |
| U4 TS3021 | `U4.4` is IN- (`OPT_AMP`), `U4.3` is IN+ (`CMP_THRESHOLD`) | IN- moves further above IN+ |

`CMP_THRESHOLD` is R26/R27 = 3.3 × 10k/(22k+10k) = **1.016 V** with the output low
(1.064 V with it high; R28's 470k gives 48 mV of hysteresis, in the correct direction).
`OPT_AMP` idles at 1.65 V because the stage is AC-coupled to the 1.65 V reference —
already 634 mV above the threshold — and light pushes it further away. IN- stays above
IN+ regardless of illumination, so the output never leaves its low state.

With the Rev F NAND gating that is total: `U9`'s output never falls, `U10` never
triggers, and TR-VERT produces no tach pulses at all.

**The fix is to flip the diode** — cathode to `PD_TIA_IN`, anode to GND:

- reverse bias is unchanged at 1.65 V (cathode at the virtual reference, anode at 0 V)
- photocurrent is pulled **out** of the summing node, so `TIA_OUT` rises
- `OPT_AMP` falls from 1.65 V and crosses 1.016 V
- the comparator trips high and the 470k hysteresis works in the direction drawn

Trip sensitivity: 634 mV needed at `OPT_AMP`, ÷ 12 of second-stage gain = 52.8 mV at
`TIA_OUT`, ÷ the 10k feedback resistor = **about 5.3 µA of photocurrent**.

There is a useful side effect, and it matters because Rev F moved Q1 closer to PD1 while
tightening the emitter loop. The emitter turn-off edge falls inside the synchronous gate
window, so the detector cannot reject it. After the flip, its capacitive coupling into
the summing node pushes `TIA_OUT` the same way darkness does — away from the trip point
— so it cannot manufacture a false detection.

**Why the verification did not catch this.** `verify_head.py` compares the exported
netlist against exact net membership, and it passed throughout: the netlist matched the
spec, the board matched the netlist, and ERC was clean. But the spec was transcribed from
the same schematic it was meant to check, so it encoded the wrong intent faithfully.
Connectivity checking answers "is it wired the way I said?", never "does what I said
work?". Tracing signal direction through a gain chain is a different kind of review, and
this design had not had one.
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

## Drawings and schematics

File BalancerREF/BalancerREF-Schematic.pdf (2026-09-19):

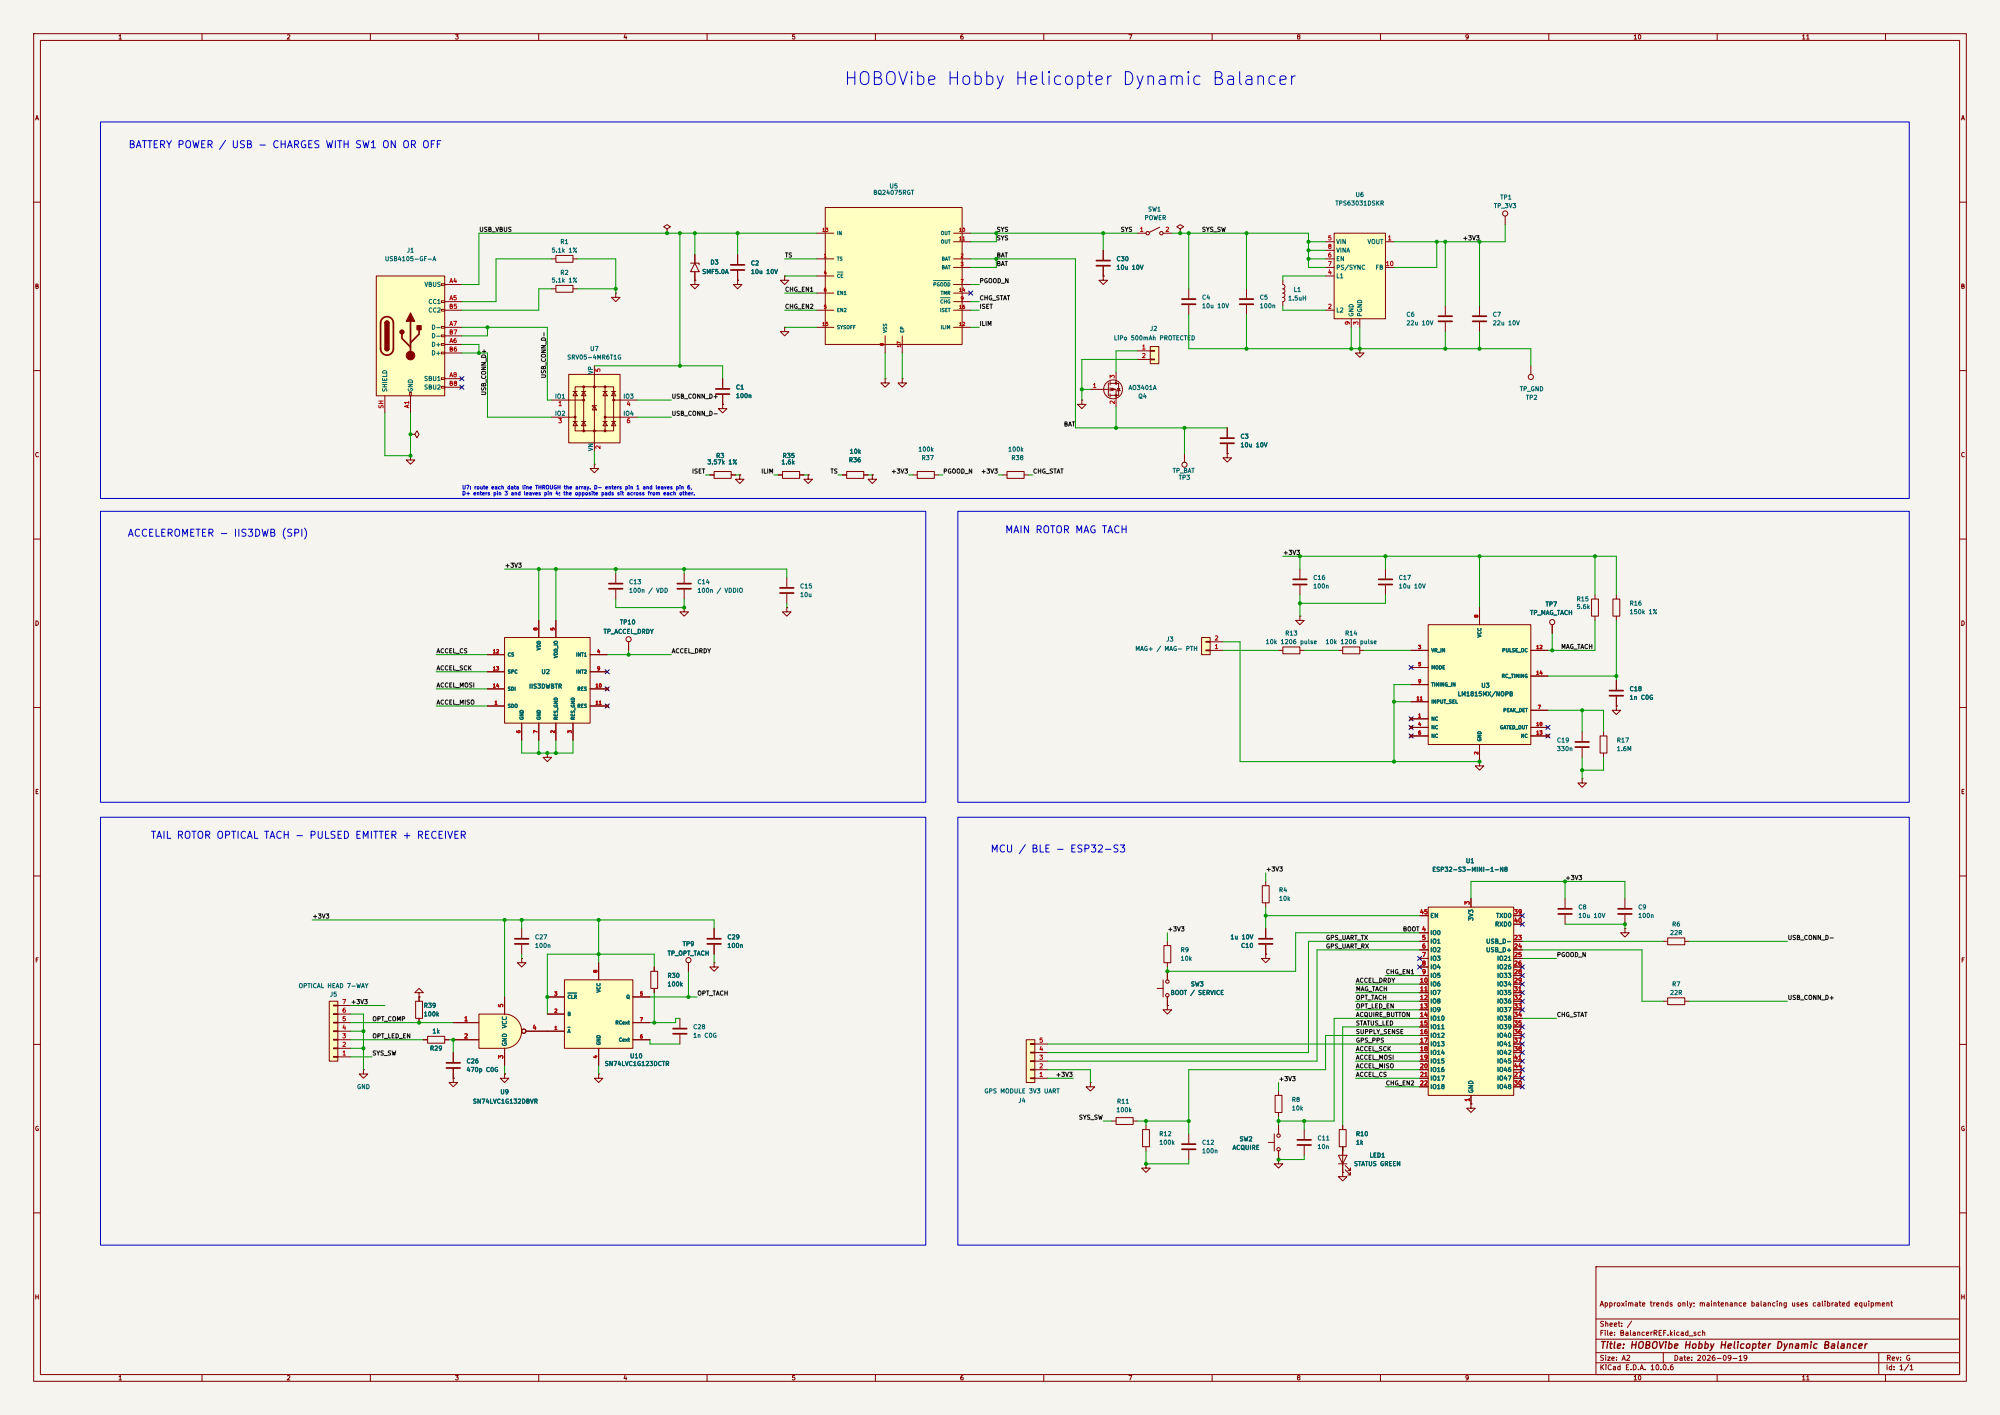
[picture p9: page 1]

HOBOVibe Hobby Helicopter Dynamic Balancer

BATTERY POWER / USB - CHARGES WITH SW1 ON OR OFF

U7: route each data line THROUGH the array. D- enters pin 1 and leaves pin 6, D+ enters pin 3 and leaves pin 4; the opposite pads sit across from each other. TAIL ROTOR OPTICAL TACH - PULSED EMITTER + RECEIVER

MAIN ROTOR MAG TACH

4 | | GPS_PPS CHG_EN2 18 18 19 19 20 20 21 21

1 | SN74LVC1G132DBVR

Approximate trends only; maintenance balancing uses calibrated equipment

Sheet: /
File: BalancerREF.kicad_sch
Title: HOBOVibe Hobby Helicopter Dynamic Balancer

Size: A2 | Rev: G
KiCad E.D.A. 10.0.6 | Id: 1/1

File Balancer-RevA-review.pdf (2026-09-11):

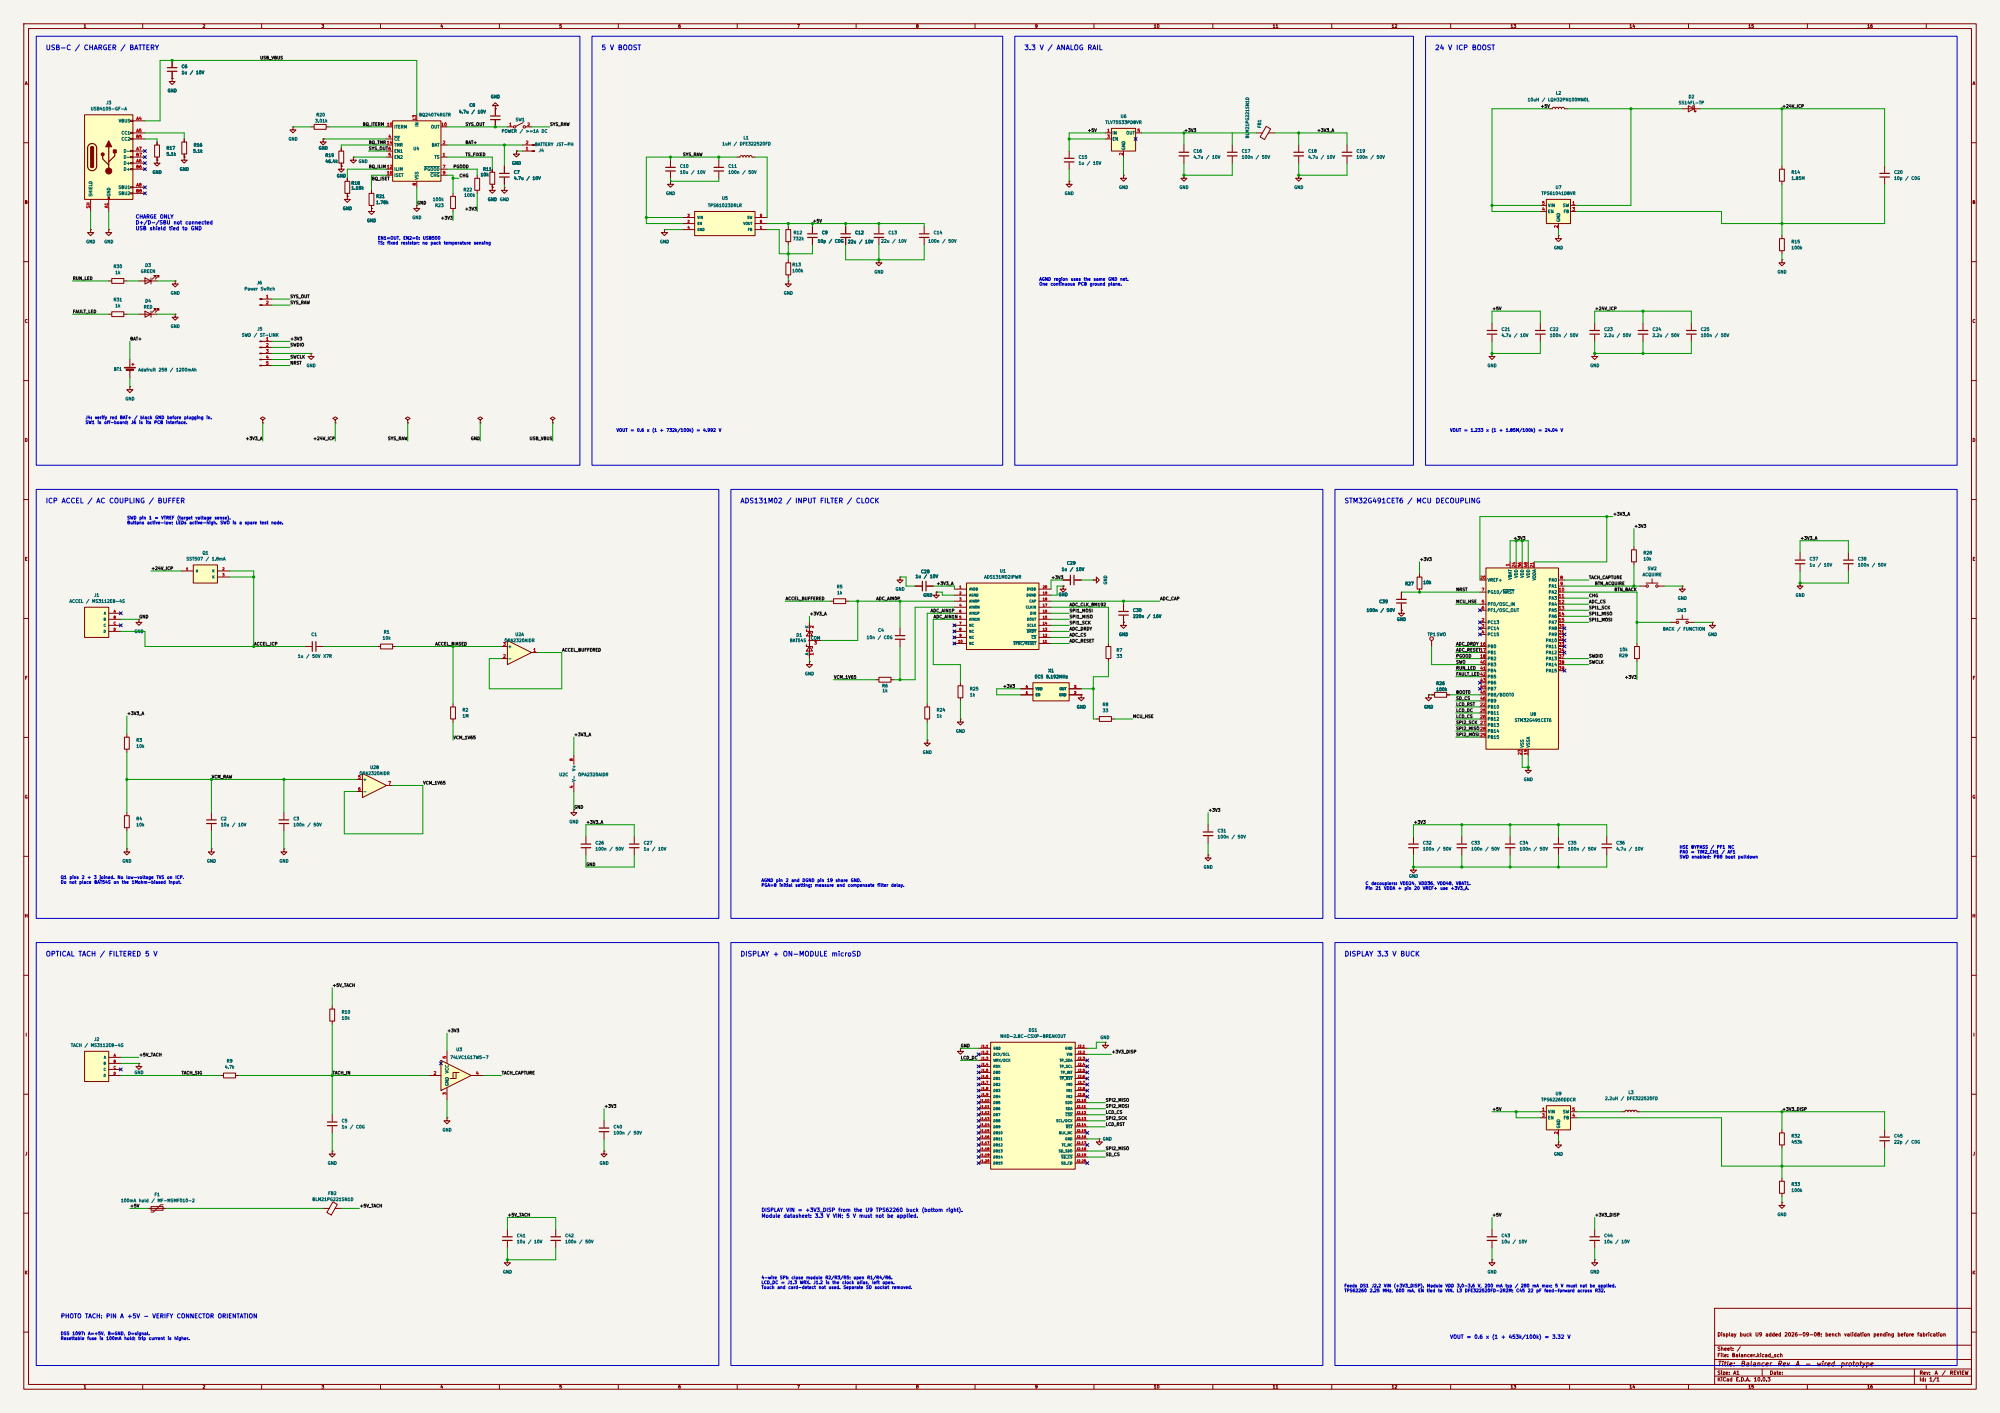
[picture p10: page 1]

CHARGE ONLY
D+/D-/SBU not connected
USB shield tied to GND

EN1=OUT, EN2=0: USB500
TS: fixed resistor; no pack temperature sensing

AGND region uses the same GND net. One continuous PCB ground plane.

J4: verify red BAT+ / black GND before plugging in. SW1 is off-board; J6 is its PCB interface. ICP ACCEL / AC COUPLING / BUFFER

LCD_RST Q1 pins 2 + 3 joined. No low-voltage TVS on ICP. Do not place BAT54S on the 1Mohm-biased input.

PA0 = TIM2_CH1 / AF1
SWD enabled; PB8 boot pulldown

AGND pin 2 and DGND pin 19 share GND. PGA=8 initial setting; measure and compensate filter delay.

C decouplers: VDD24, VDD36, VDD48, VBAT1. Pin 21 VDDA + pin 20 VREF+ use +3V3_A.

DISPLAY + ON-MODULE microSD

Feeds DS1 J2.2 VIN (+3V3_DISP). Module VDD 3.0-3.6 V, 200 mA typ / 280 mA max; 5 V must not be applied. TPS62260 2.25 MHz, 600 mA, EN tied to VIN. L3 DFE322520FD-2R2M; C45 22 pF feed-forward across R32. DISPLAY 3.3 V BUCK

DISPLAY VIN = +3V3_DISP from the U9 TPS62260 buck (bottom right).
Module datasheet: 3.3 V VIN; 5 V must not be applied.

4-wire SPI: close module R2/R3/R5; open R1/R4/R6. LCD_DC = J1.3 WRX. J1.2 is the clock alias, left open. Touch and card-detect not used. Separate SD socket removed.

PHOTO TACH: PIN A +5V - VERIFY CONNECTOR ORIENTATION

DSS 1097: A=+5V, B=GND, D=signal. Resettable fuse is 100mA hold; trip current is higher.

Display buck U9 added 2026-09-08; bench validation pending before fabrication

Sheet: / File: Balancer.kicad_sch

Title: Balancer Rev A - wired prototype

Size: A1 | Rev: A / REVIEW
KiCad E.D.A. 10.0.3 | Id: 1/1

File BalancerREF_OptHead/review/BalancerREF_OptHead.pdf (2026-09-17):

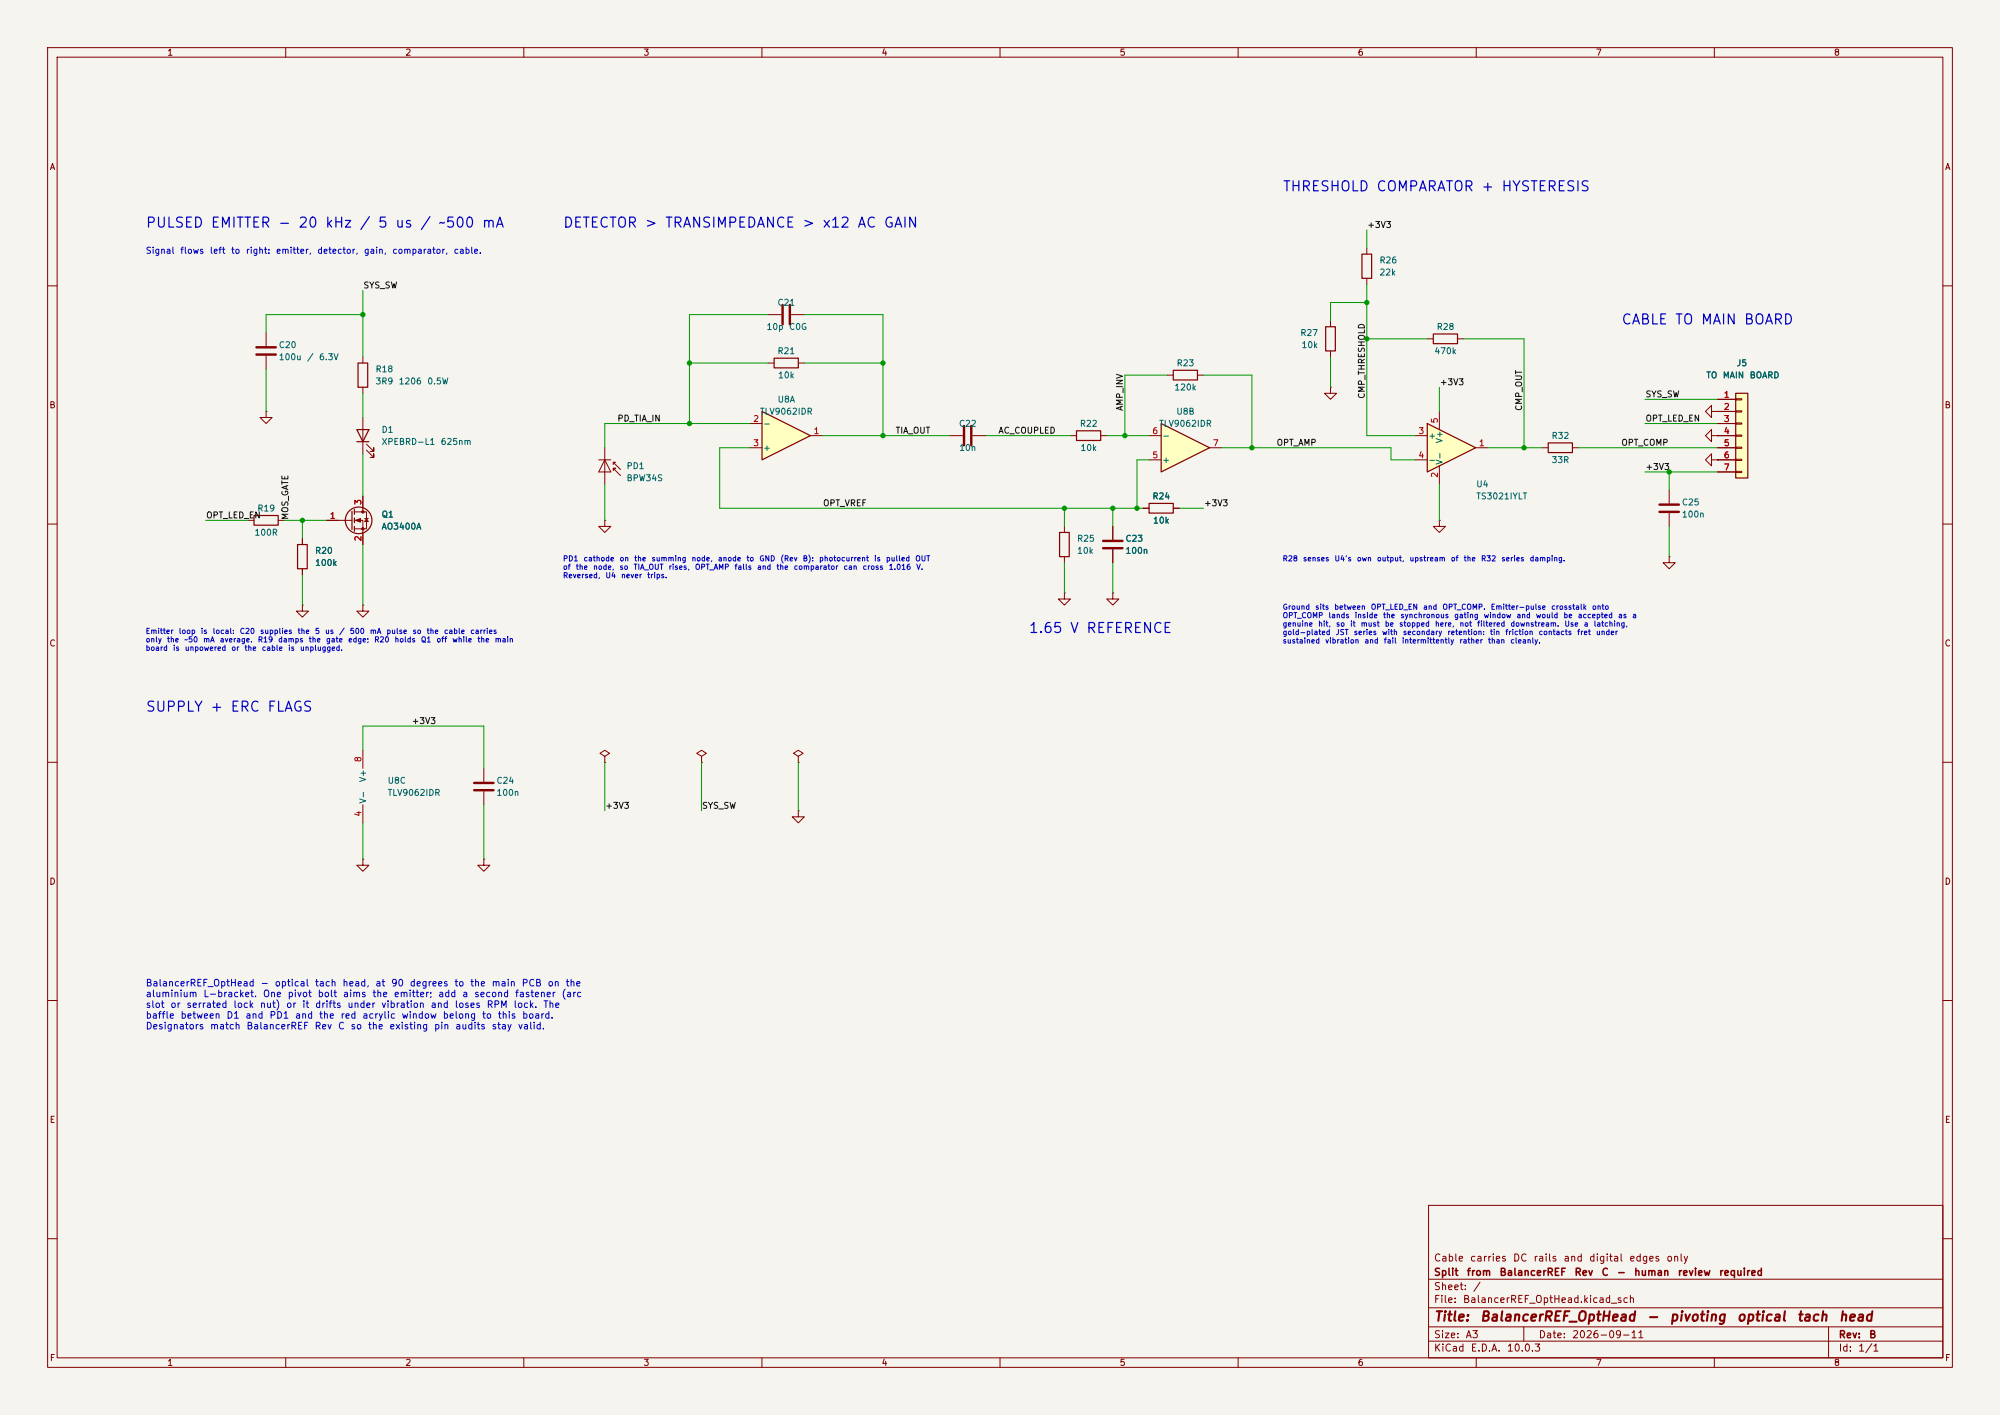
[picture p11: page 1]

PULSED EMITTER - 20 kHz / 5 us / ~500 mA

CABLE TO MAIN BOARD

board is unpowered or the cable is unplugged.

Cable carries DC rails and digital edges only
Split from BalancerREF Rev C - human review required
Sheet: /
File: BalancerREF_OptHead.kicad_sch
Title: BalancerREF_OptHead - pivoting optical tach head

Size: A3 | Rev: B
KiCad E.D.A. 10.0.3 | Id: 1/1 | F Date: 2026-09-11

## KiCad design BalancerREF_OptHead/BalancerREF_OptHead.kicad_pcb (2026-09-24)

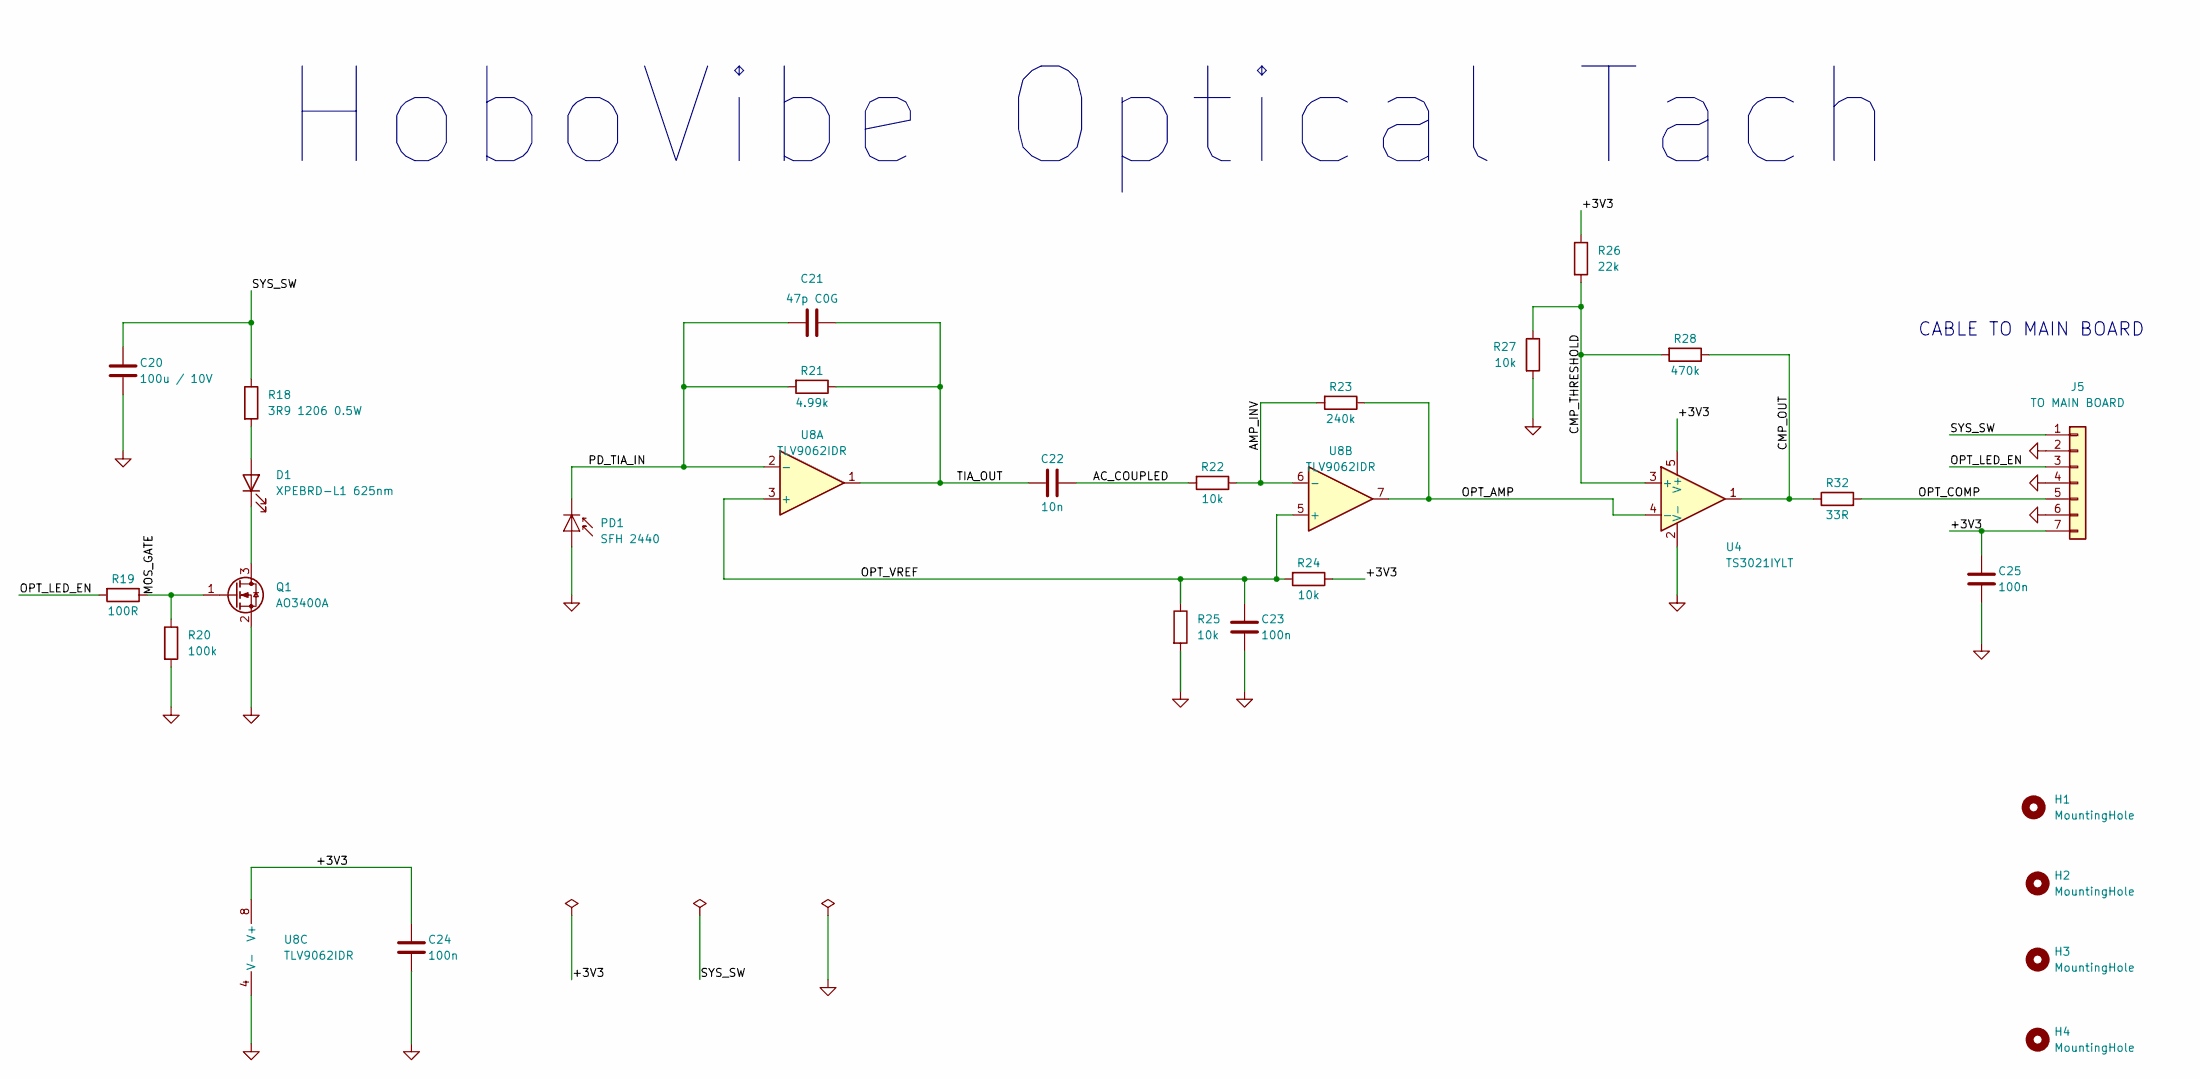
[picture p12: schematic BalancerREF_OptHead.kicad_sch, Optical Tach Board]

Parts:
C20: 100u / 10V; C_1210_3225Metric; MPN 100u / 10V
C21: 47p C0G; C_0805_2012Metric; MPN 47p C0G
C22: 10n; C_0805_2012Metric; MPN 10n
C23, C24, C25: 100n; C_0805_2012Metric; MPN 100n
D1: XPEBRD-L1 625nm; LED_Cree-XP; MPN XPEBRD-L1 625nm
H1, H2, H3, H4: MountingHole; MountingHole_2.2mm_M2_DIN965
J5: TO MAIN BOARD; JST_GH_SM07B-GHS-TB_1x07-1MP_P1.25mm_Horizontal; MPN TO MAIN BOARD
PD1: SFH 2440; Osram_SFH2440; MPN SFH 2440
Q1: AO3400A; SOT-23; MPN AO3400A
R18: 3R9 1206 0.5W; R_1206_3216Metric; MPN 3R9 1206 0.5W
R19: 100R; R_0603_1608Metric; MPN 100R
R20: 100k; R_0603_1608Metric; MPN 100k
R21: 4.99k; R_0603_1608Metric; MPN 4.99k
R22, R24, R25, R27: 10k; R_0603_1608Metric; MPN 10k
R23: 240k; R_0603_1608Metric; MPN 240k
R26: 22k; R_0603_1608Metric; MPN 22k
R28: 470k; R_0603_1608Metric; MPN 470k
R32: 33R; R_0603_1608Metric; MPN 33R
U4: TS3021IYLT; SOT-23-5; MPN TS3021IYLT
U8: TLV9062IDR; SOIC-8_3.9x4.9mm_P1.27mm; MPN TLV9062IDR

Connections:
/+3V3: C24.1, C25.1, J5.7, R24.1, R26.1, U4.5 (V+), U8.8 (V+)
/AC_COUPLED: C22.2, R22.2
/AMP_INV: R22.1, R23.2, U8.6 (-)
/CMP_OUT: R28.1, R32.1, U4.1
/CMP_THRESHOLD: R26.2, R27.1, R28.2, U4.3 (+)
/MOS_GATE: Q1.1 (G), R19.1, R20.1
/OPT_AMP: R23.1, U4.4 (-), U8.7
/OPT_COMP: J5.5, R32.2
/OPT_LED_EN: J5.3, R19.2
/OPT_VREF: C23.1, R24.2, R25.1, U8.3 (+), U8.5 (+)
/PD_TIA_IN: C21.1, PD1.1 (K), R21.2, U8.2 (-)
/SYS_SW: C20.1, J5.1, R18.1
/TIA_OUT: C21.2, C22.1, R21.1, U8.1
GND: C20.2, C23.2, C24.2, C25.2, J5.2, J5.4, J5.6, PD1.2 (A), Q1.2 (S), R20.2, R25.2, R27.2, U4.2 (V-), U8.4 (V-)
unnamed: D1.2 (A), R18.2
unnamed: D1.1 (K), Q1.3 (D)

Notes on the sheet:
HoboVibe Optical Tach
CABLE TO MAIN BOARD

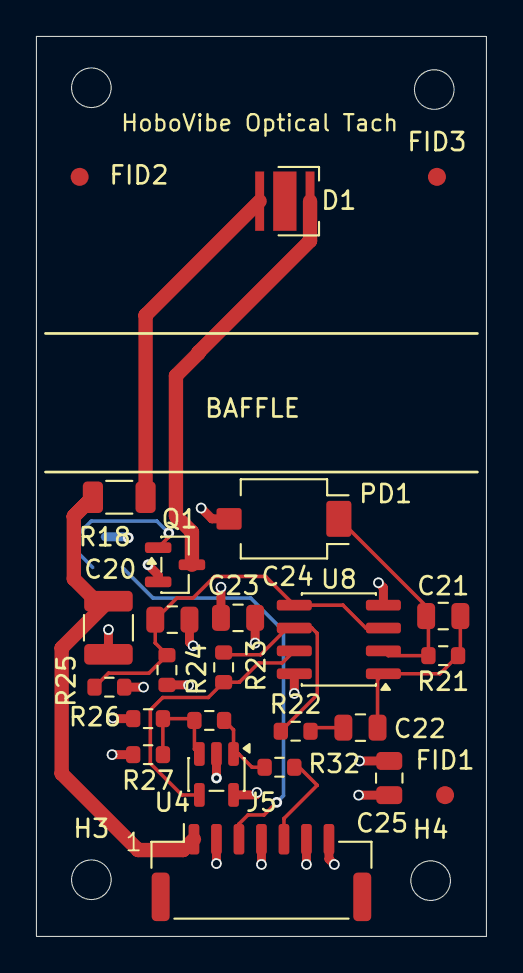
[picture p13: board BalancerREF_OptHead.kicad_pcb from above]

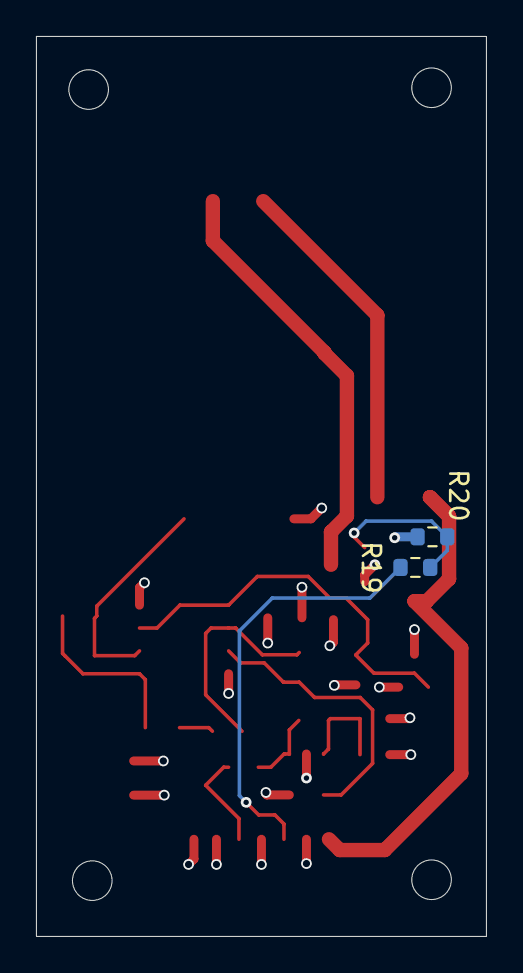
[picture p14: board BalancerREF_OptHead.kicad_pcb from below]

Board: 4 copper layers, 25.0 x 50.0 mm, 31 parts (2 on the bottom side), 16 nets.

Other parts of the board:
FID1, FID2, FID3: FIDUCIAL; Fiducial_1mm_Mask2mm

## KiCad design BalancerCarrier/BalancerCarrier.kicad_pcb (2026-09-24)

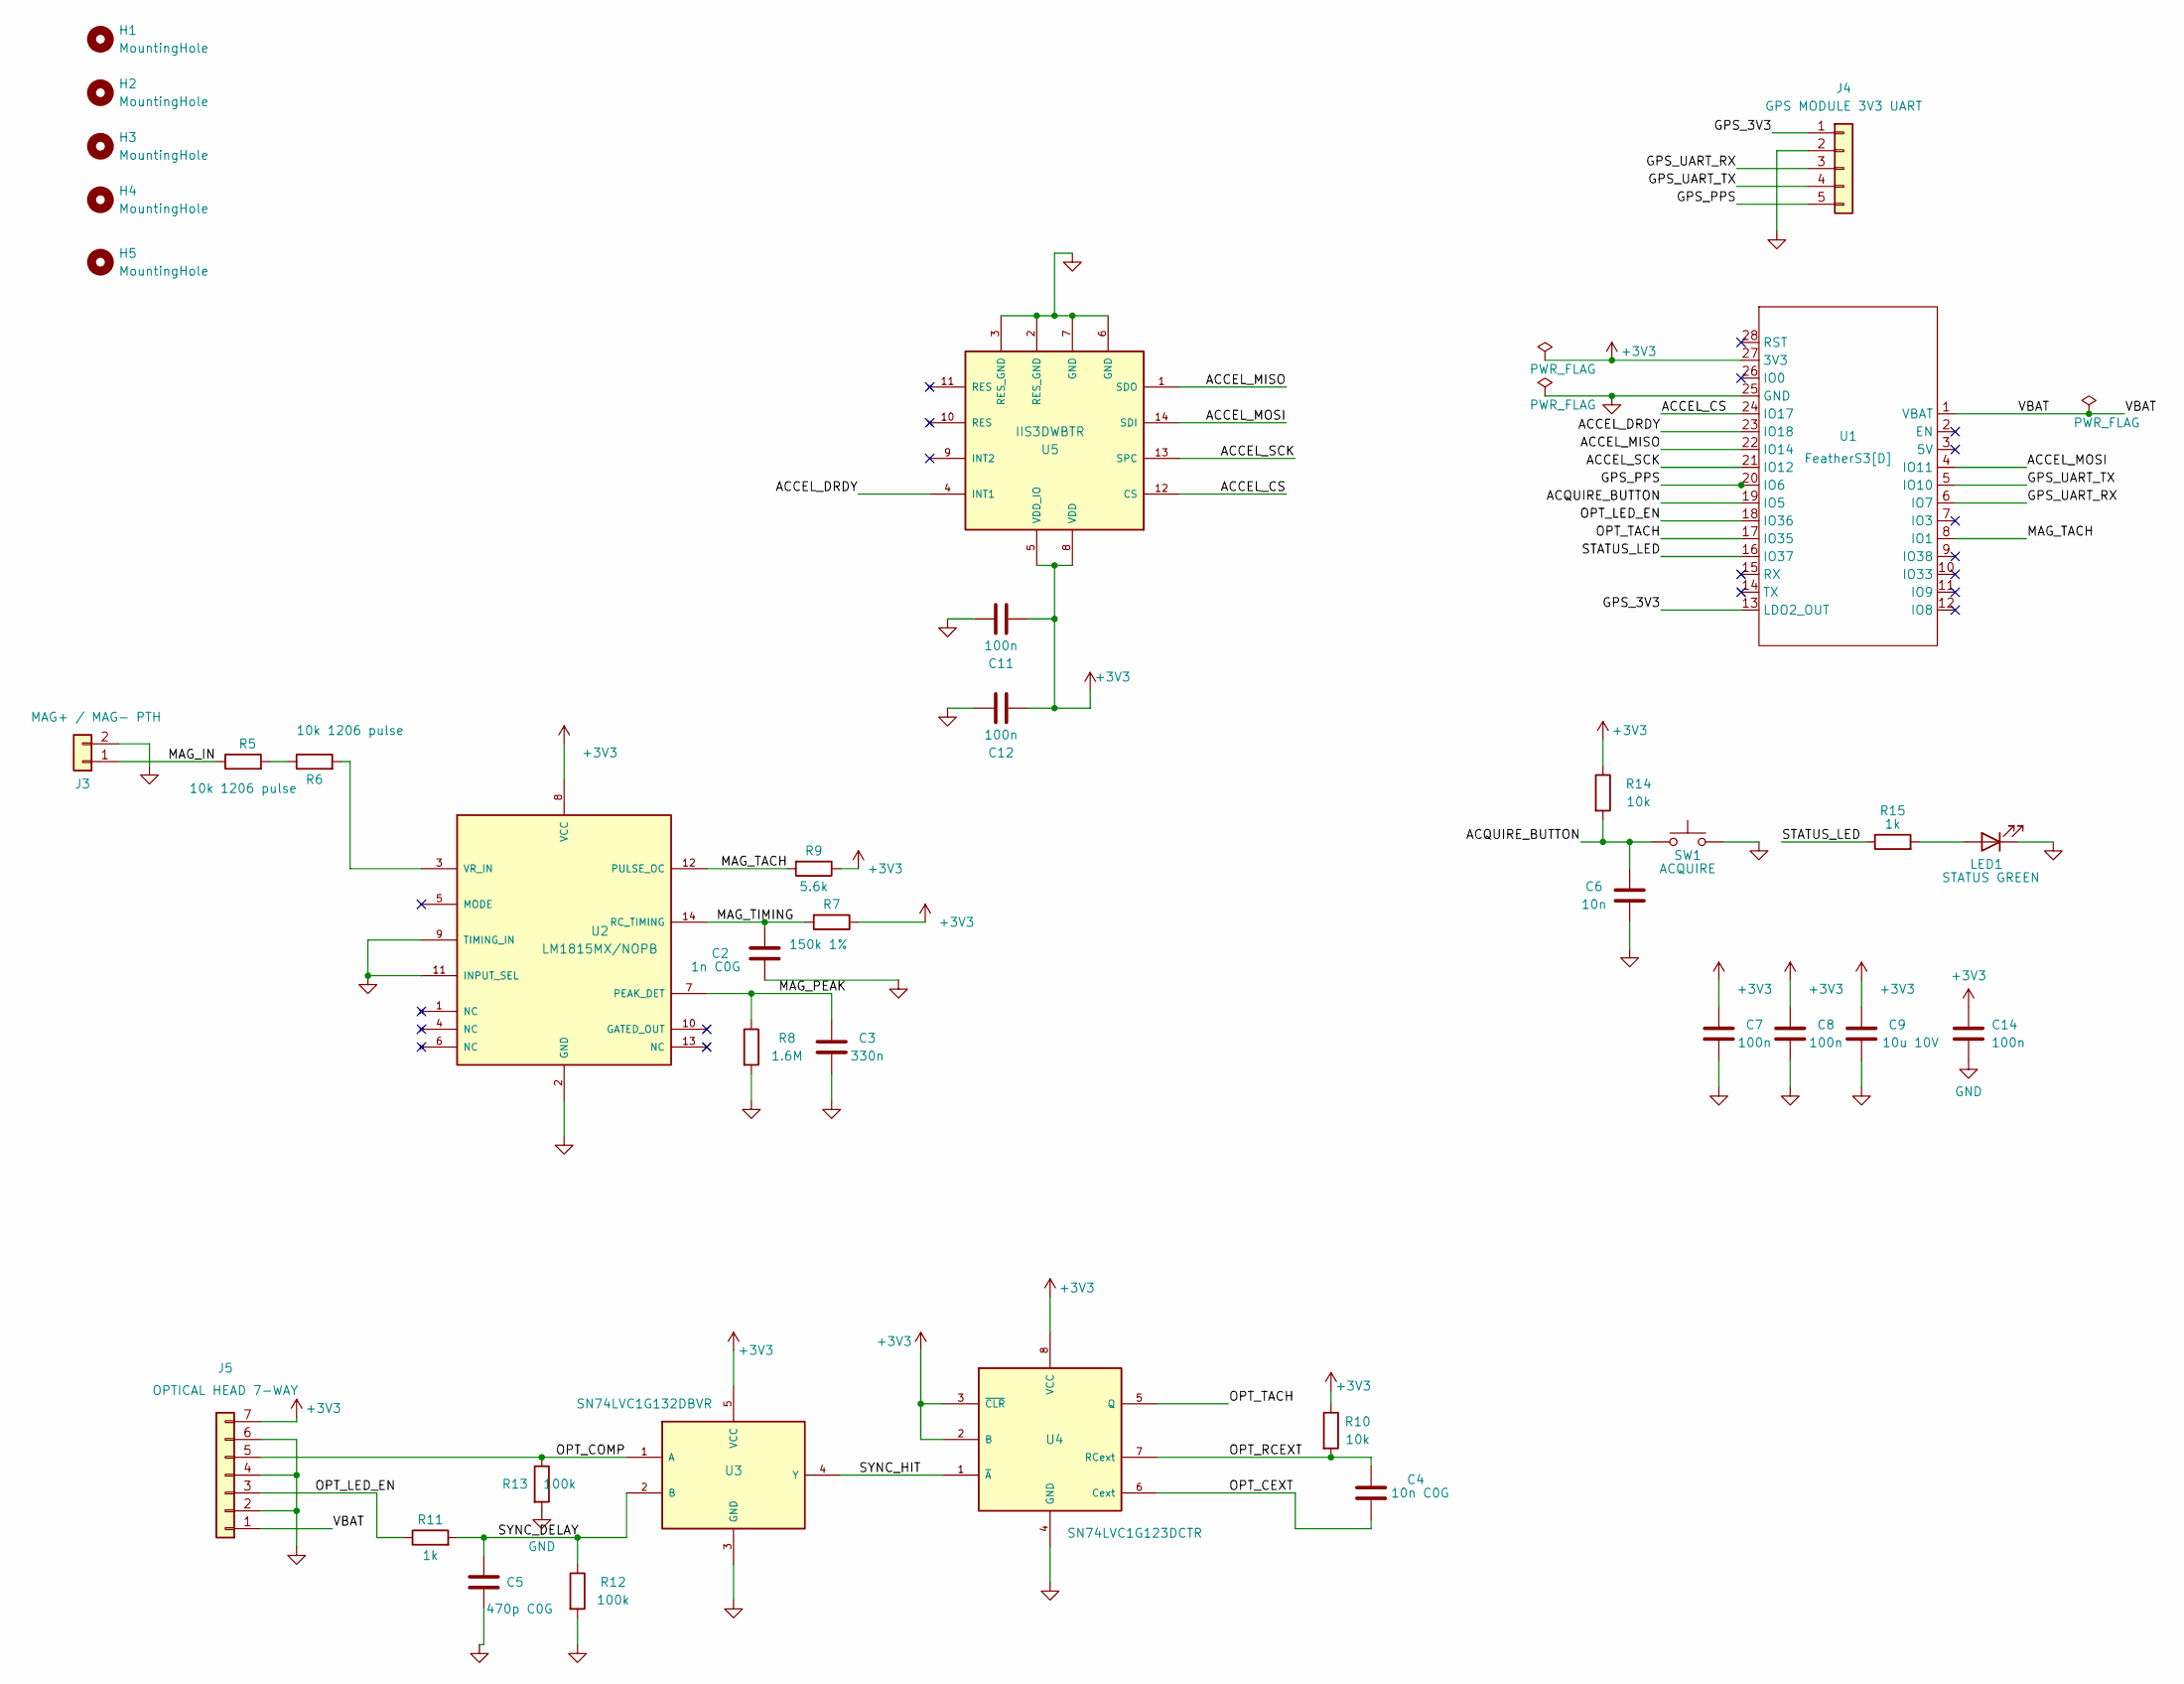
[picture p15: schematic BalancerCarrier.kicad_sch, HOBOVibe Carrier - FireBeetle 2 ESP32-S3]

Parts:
C2: 1n C0G; C_0805_2012Metric
C3: 330n; C_0805_2012Metric
C4: 10n C0G; C_0805_2012Metric
C5: 470p C0G; C_0805_2012Metric
C6: 10n; C_0805_2012Metric
C7, C8, C11, C12, C14: 100n; C_0805_2012Metric
C9: 10u 10V; C_0805_2012Metric
H1, H2, H3, H4, H5: MountingHole; MountingHole_2.2mm_M2
J3: MAG+ / MAG- PTH; SolderWire-0.1sqmm_1x02_P3.6mm_D0.4mm_OD1mm
J4: GPS MODULE 3V3 UART; PinHeader_1x05_P2.54mm_Vertical
J5: OPTICAL HEAD 7-WAY; JST_GH_SM07B-GHS-TB_1x07-1MP_P1.25mm_Horizontal
LED1: STATUS GREEN; LED_0603_1608Metric
R5, R6: 10k 1206 pulse; R_1206_3216Metric
R7: 150k 1%; R_0603_1608Metric
R8: 1.6M; R_0603_1608Metric
R9: 5.6k; R_0603_1608Metric
R10, R14: 10k; R_0603_1608Metric
R11, R15: 1k; R_0603_1608Metric
R12, R13: 100k; R_0603_1608Metric
SW1: ACQUIRE; SW_PUSH_6mm
U1: FeatherS3[D]; FeatherS3
U2: LM1815MX/NOPB; SOIC-14_3.9x8.7mm_P1.27mm
U3: SN74LVC1G132DBVR; SOT-23-5
U4: SN74LVC1G123DCTR; SSOP-8_2.95x2.8mm_P0.65mm
U5: IIS3DWBTR; LGA-14_3x2.5mm_P0.5mm_LayoutBorder3x4y

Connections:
+3V3: C7.1, C8.1, C9.1, C11.1, C12.1, C14.1, J5.7, R7.1, R9.1, R10.1, R14.1, U1.27 (3V3), U2.8 (VCC), U3.5 (VCC), U4.2 (B), U4.3 (~CLR), U4.8 (VCC), U5.5 (VDD_IO), U5.8 (VDD)
/ACCEL_CS: U1.24 (IO17), U5.12 (CS)
/ACCEL_DRDY: U1.23 (IO18), U5.4 (INT1)
/ACCEL_MISO: U1.22 (IO14), U5.1 (SDO)
/ACCEL_MOSI: U1.4 (IO11), U5.14 (SDI)
/ACCEL_SCK: U1.21 (IO12), U5.13 (SPC)
/ACQUIRE_BUTTON: C6.1, R14.2, SW1.1, U1.19 (IO5)
/GPS_3V3: J4.1, U1.13 (LDO2_OUT)
/GPS_PPS: J4.5, U1.20 (IO6)
/GPS_UART_RX: J4.3, U1.6 (IO7)
/GPS_UART_TX: J4.4, U1.5 (IO10)
/MAG_IN: J3.1, R5.1
/MAG_PEAK: C3.1, R8.1, U2.7 (PEAK_DET)
/MAG_TACH: R9.2, U1.8 (IO1), U2.12 (PULSE_OC)
/MAG_TIMING: C2.1, R7.2, U2.14 (RC_TIMING)
/OPT_CEXT: C4.2, U4.6 (Cext)
/OPT_COMP: J5.5, R13.1, U3.1 (A)
/OPT_LED_EN: J5.3, R11.1, U1.18 (IO36)
/OPT_RCEXT: C4.1, R10.2, U4.7 (RCext)
/OPT_TACH: U1.17 (IO35), U4.5 (Q)
/STATUS_LED: R15.1, U1.16 (IO37)
/SYNC_DELAY: C5.1, R11.2, R12.1, U3.2 (B)
/SYNC_HIT: U3.4 (Y), U4.1 (~A)
/VBAT: J5.1, U1.1 (VBAT)
GND: C2.2, C3.2, C5.2, C6.2, C7.2, C8.2, C9.2, C11.2, C12.2, C14.2, J3.2, J4.2, J5.2, J5.4, J5.6, LED1.1 (K), R8.2, R12.2, R13.2, SW1.2, U1.25 (GND), U2.2 (GND), U2.9 (TIMING_IN), U2.11 (INPUT_SEL), U3.3 (GND), U4.4 (GND), U5.2 (RES_GND), U5.3 (RES_GND), U5.6 (GND), U5.7 (GND)
unnamed: LED1.2 (A), R15.2
unnamed: R5.2, R6.1
unnamed: R6.2, U2.3 (VR_IN)

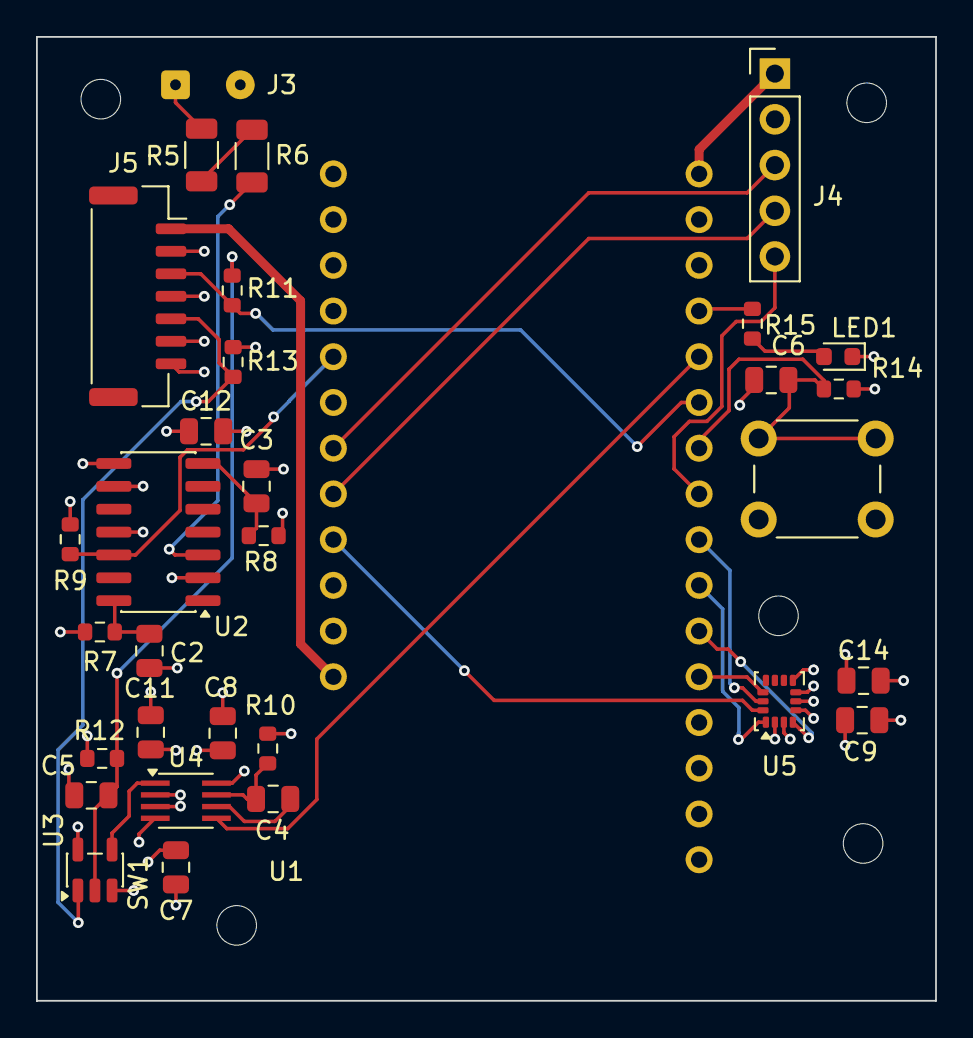
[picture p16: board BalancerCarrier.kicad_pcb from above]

Board: 4 copper layers, 50.0 x 53.6 mm, 37 parts (0 on the bottom side), 28 nets.

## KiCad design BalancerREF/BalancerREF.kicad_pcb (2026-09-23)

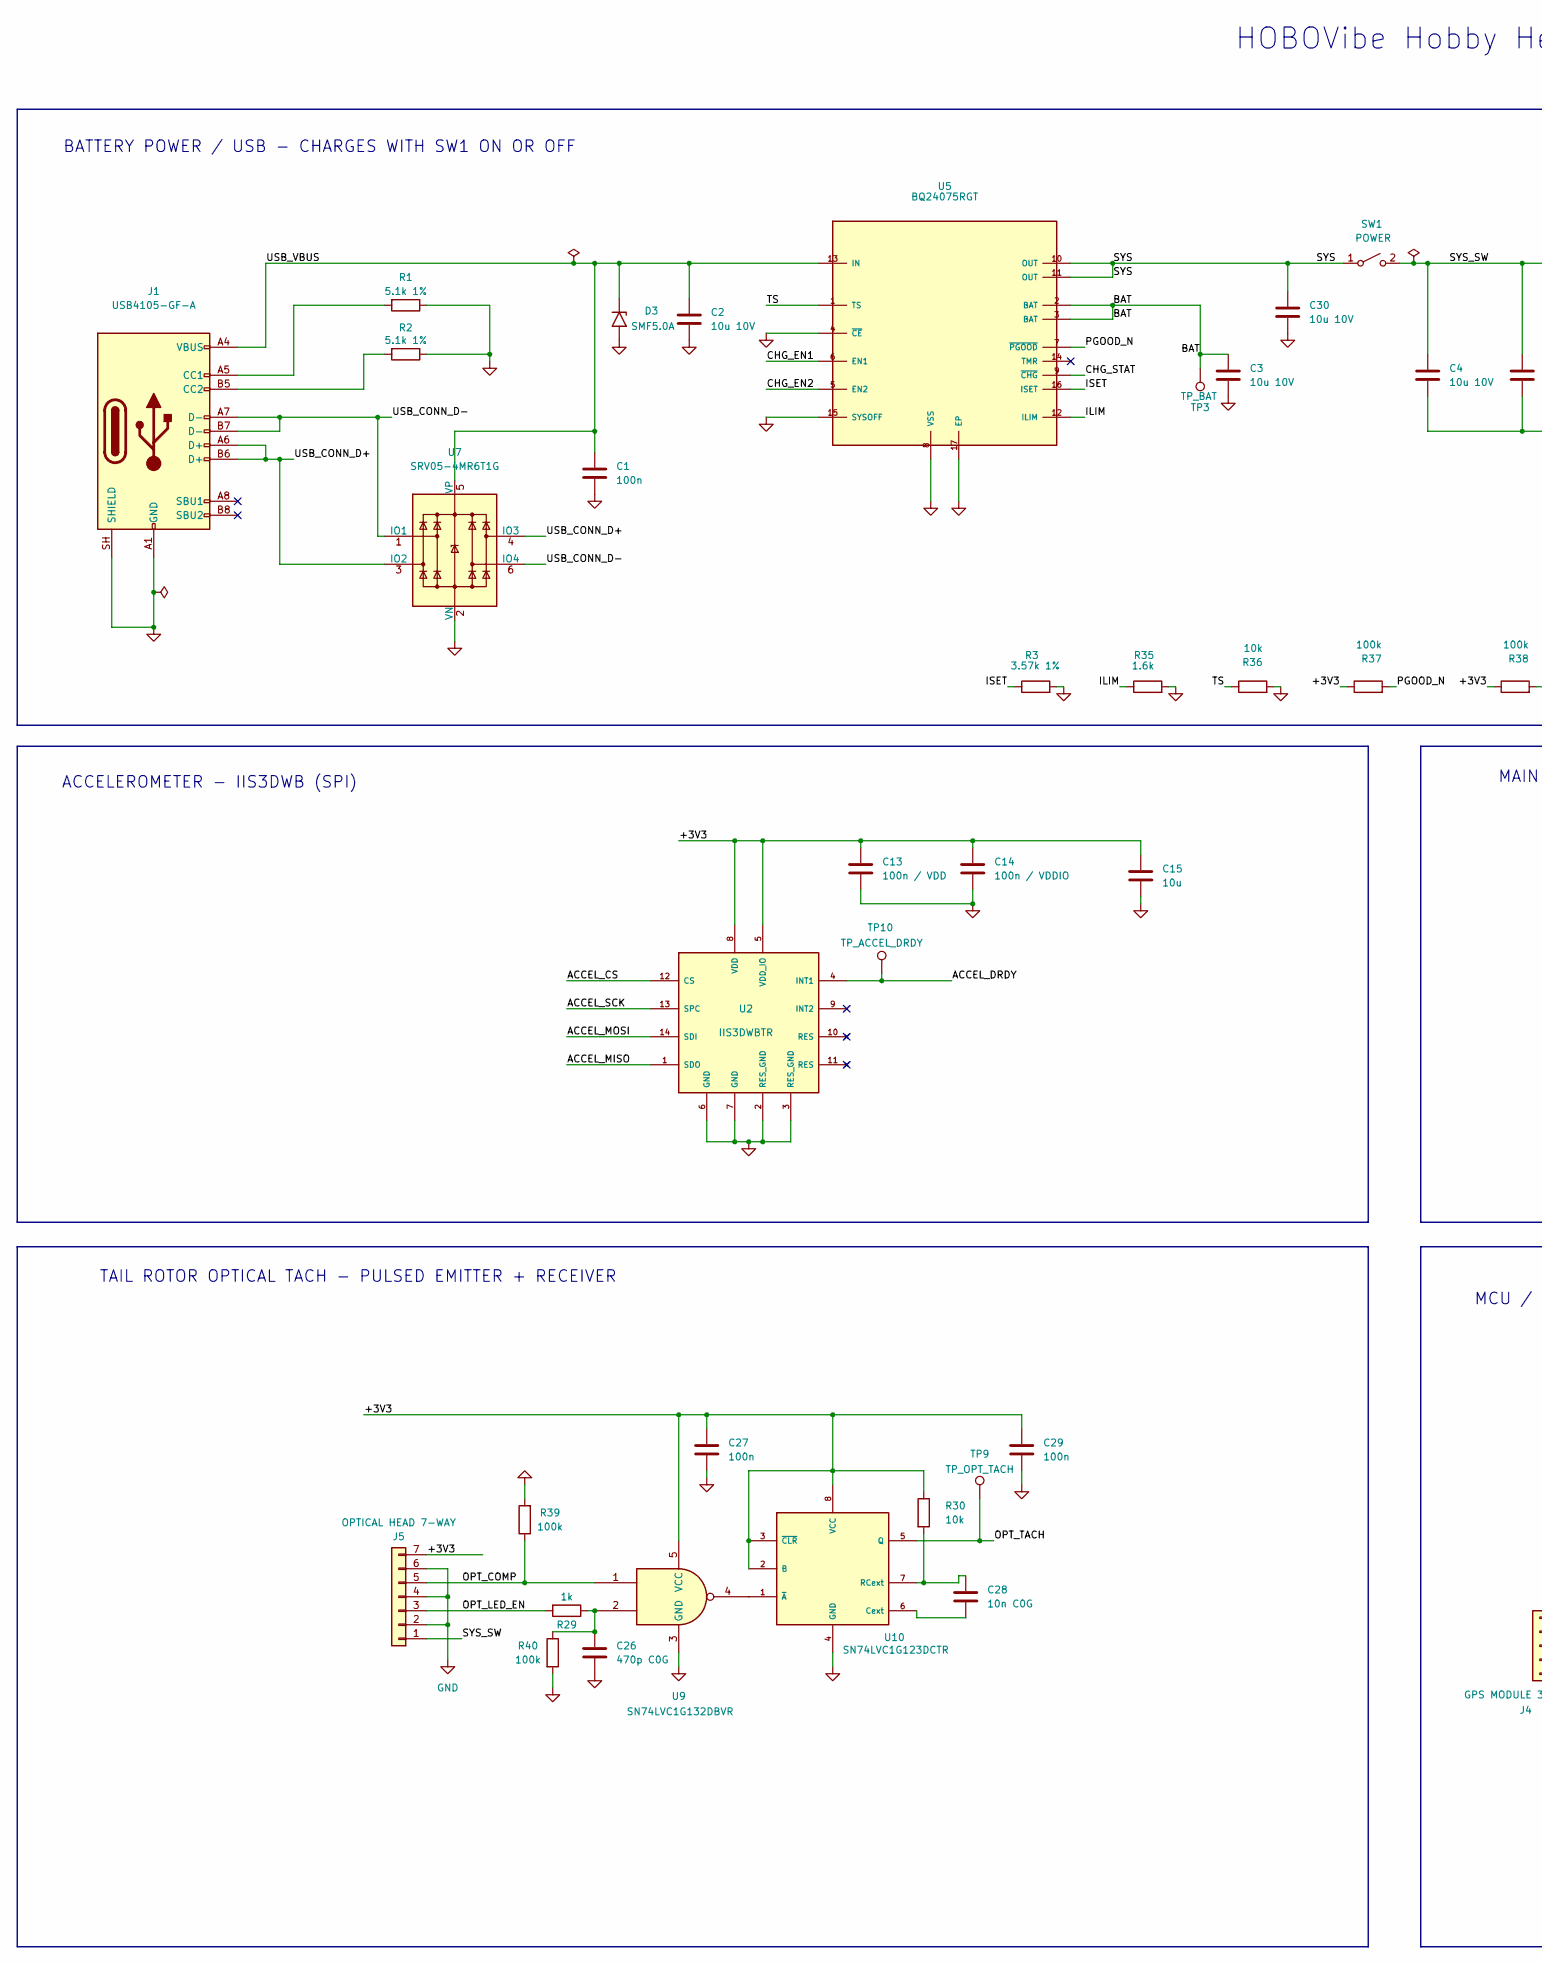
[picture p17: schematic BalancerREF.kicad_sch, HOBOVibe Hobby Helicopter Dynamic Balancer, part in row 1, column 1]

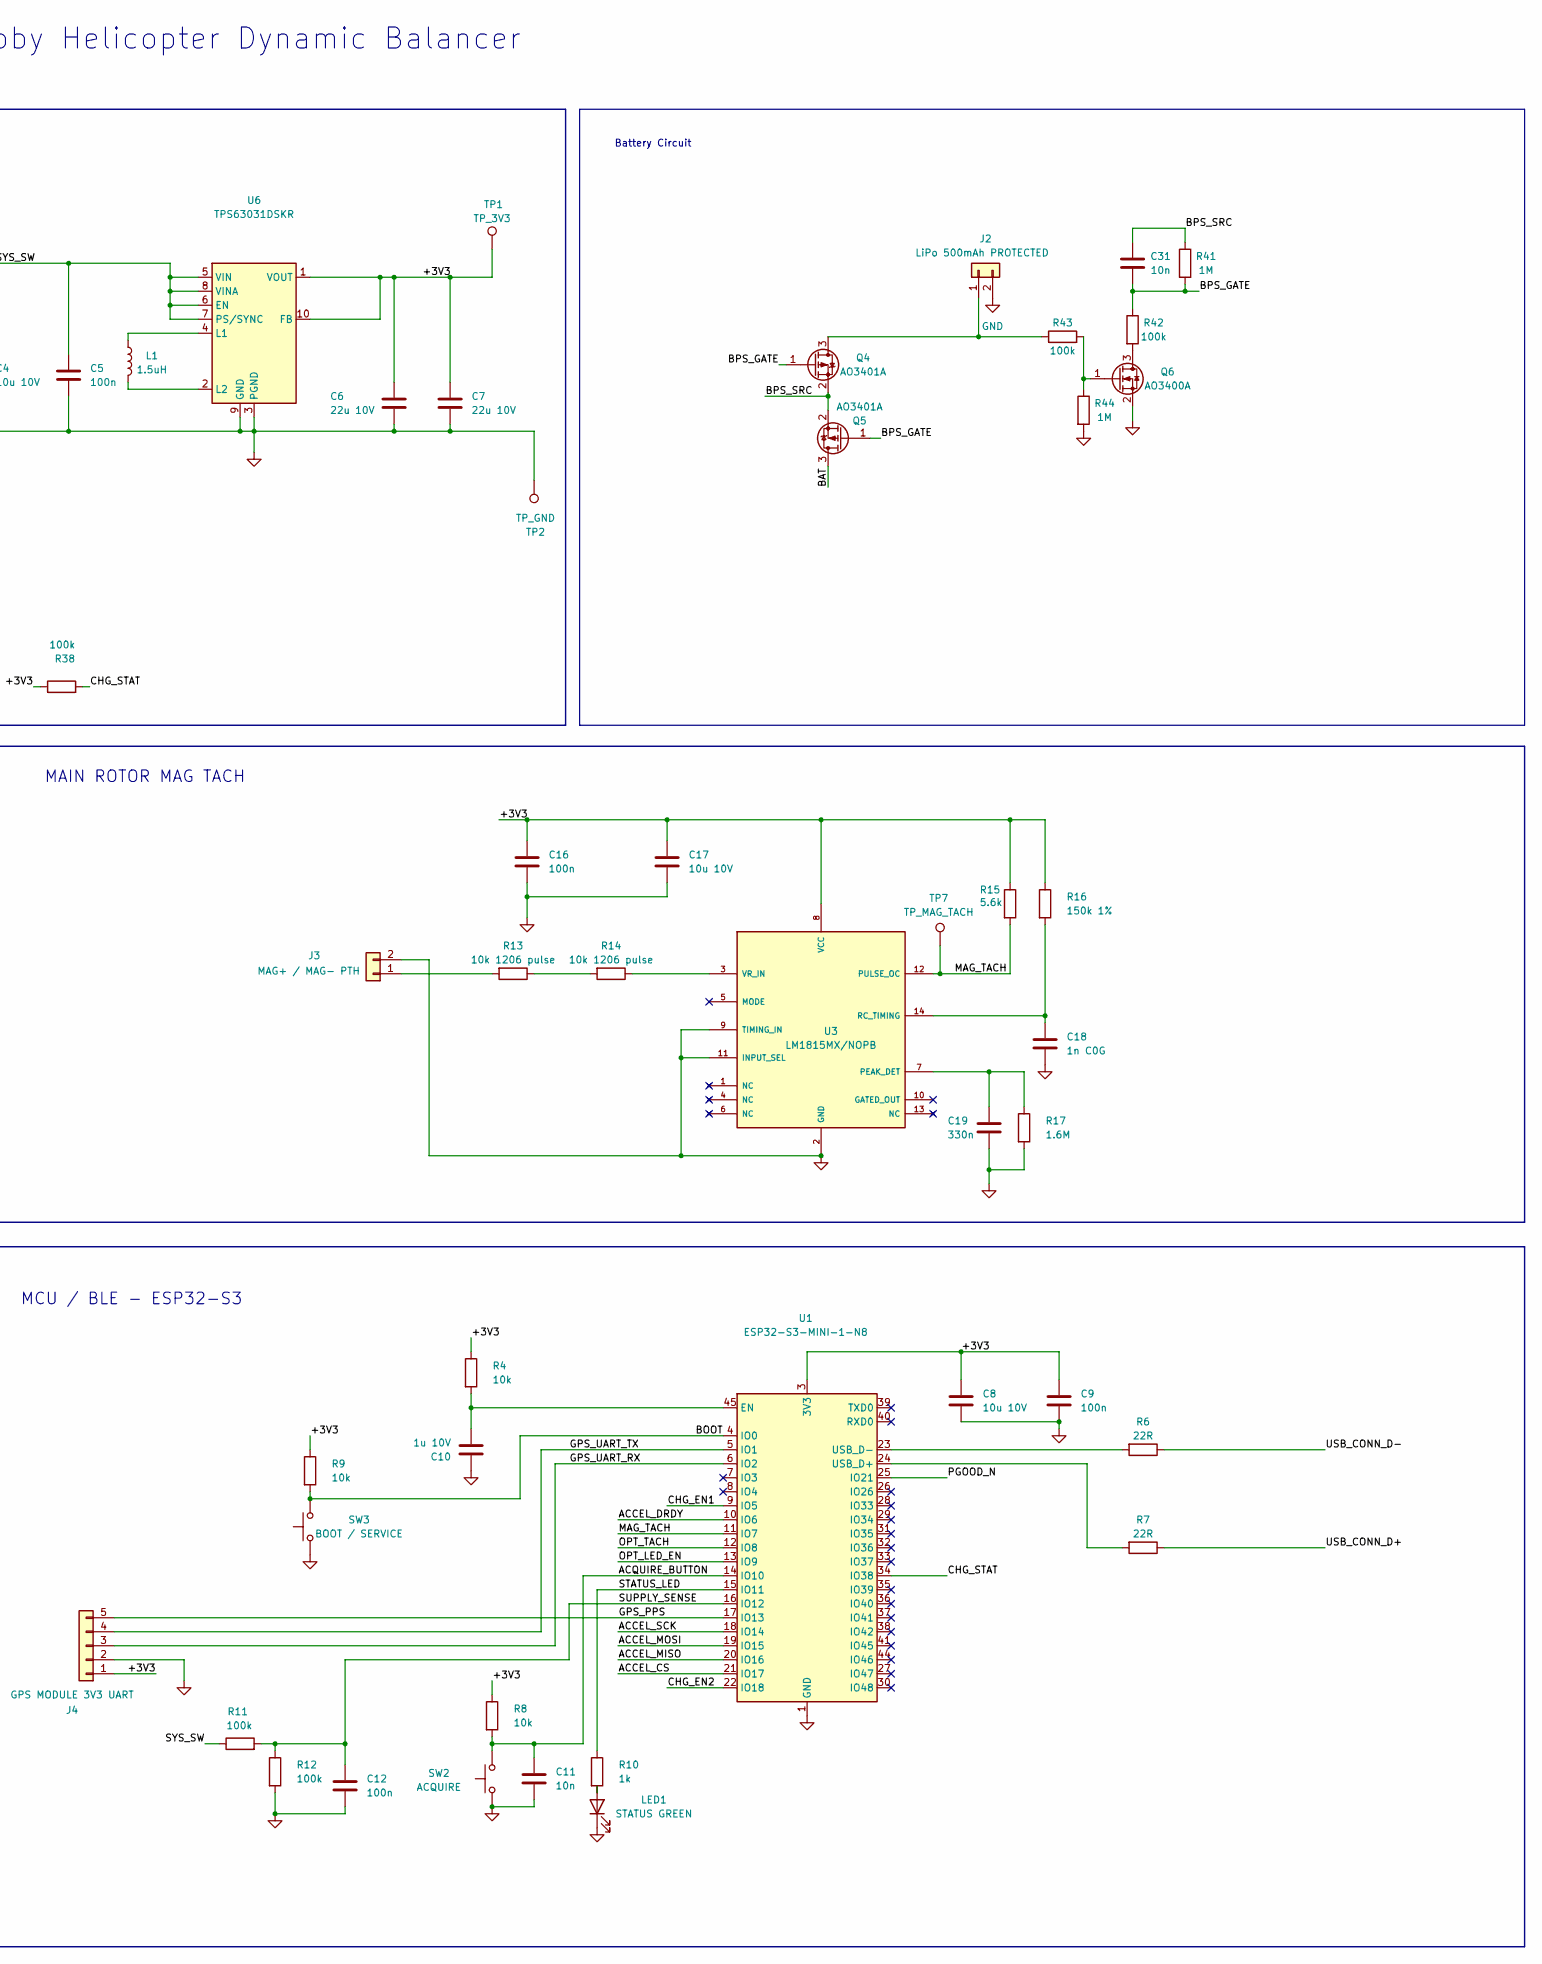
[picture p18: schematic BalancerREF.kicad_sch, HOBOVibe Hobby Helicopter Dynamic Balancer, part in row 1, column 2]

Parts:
C1, C5, C9: 100n; C_0805_2012Metric; MPN 100n / 10V
C2, C3, C4, C8: 10u 10V; C_0805_2012Metric; MPN 10u / 10V X7R
C6, C7: 22u 10V; C_0805_2012Metric; MPN 22u / 10V X7R
C10: 1u 10V; C_0805_2012Metric; MPN 1u / 10V
C11, C31: 10n; C_0805_2012Metric; MPN 10n
C12, C16, C27, C29: 100n; C_0805_2012Metric; MPN 100n
C13: 100n / VDD; C_0805_2012Metric; MPN 100n / VDD
C14: 100n / VDDIO; C_0805_2012Metric; MPN 100n / VDDIO
C15: 10u; C_0805_2012Metric; MPN 10u
C17: 10u 10V; C_0805_2012Metric; MPN 10u / 10V
C18: 1n C0G; C_0805_2012Metric; MPN 1n C0G
C19: 330n; C_0805_2012Metric; MPN 330n
C26: 470p C0G; C_0805_2012Metric; MPN 470p C0G
C28: 10n C0G; C_0805_2012Metric; MPN 1n C0G
C30: 10u 10V; C_0805_2012Metric; MPN 10u 10V
D3: SMF5.0A; D_SMF; MPN SMF5.0A
J1: USB4105-GF-A; USB_C_Receptacle_GCT_USB4105-xx-A_16P_TopMnt_Horizontal; MPN USB4105-GF-A
J2: LiPo 500mAh PROTECTED; JST_PH_B2B-PH-K_1x02_P2.00mm_Vertical; MPN JST B2B-PH-K-S
J3: MAG+ / MAG- PTH; SolderWire-0.1sqmm_1x02_P3.6mm_D0.4mm_OD1mm; MPN MAG+ / MAG- PTH
J4: GPS MODULE 3V3 UART; PinHeader_1x05_P2.54mm_Vertical; MPN PinHeader 1x05 2.54mm
J5: OPTICAL HEAD 7-WAY; JST_GH_SM07B-GHS-TB_1x07-1MP_P1.25mm_Horizontal; MPN SM07B-GHS-TB
L1: 1.5uH; L_Murata_DFE201610P; MPN DFE201612PD-1R5M=P2
LED1: STATUS GREEN; LED_0603_1608Metric; MPN STATUS GREEN
Q4, Q5: AO3401A; SOT-23; MPN AO3401A
Q6: AO3400A; SOT-23; MPN AO3400A
R1, R2: 5.1k 1%; R_0603_1608Metric; MPN 5.1k 1%
R3: 3.57k 1%; R_0603_1608Metric; MPN 3.57k 1%
R4, R8, R9, R36: 10k; R_0603_1608Metric; MPN 10k
R6, R7: 22R; R_0603_1608Metric; MPN 22R
R10, R29: 1k; R_0603_1608Metric; MPN 1k
R11, R12, R37, R38, R39, R40, R42, R43: 100k; R_0603_1608Metric; MPN 100k
R13, R14: 10k 1206 pulse; R_1206_3216Metric; MPN 10k 1206 pulse
R15: 5.6k; R_0603_1608Metric; MPN 5.6k
R16: 150k 1%; R_0603_1608Metric; MPN 150k 1%
R17: 1.6M; R_0603_1608Metric; MPN 1.6M
R30: 10k; R_0603_1608Metric; MPN 100k
R35: 1.6k; R_0603_1608Metric; MPN 1.6k
R41, R44: 1M; R_0603_1608Metric; MPN 1M
SW1: POWER; SW_Slide-03_Wuerth-WS-SLTV_10x2.5x6.4_P2.54mm; MPN POWER
SW2: ACQUIRE; SW_PUSH_6mm; MPN ACQUIRE
SW3: BOOT / SERVICE; SW_PUSH_6mm; MPN BOOT / SERVICE
TP1: TP_3V3; TestPoint_Pad_D1.0mm; MPN TP_3V3
TP2: TP_GND; TestPoint_Pad_D1.0mm; MPN TP_GND
TP3: TP_BAT; TestPoint_Pad_D1.0mm; MPN TP_BAT
TP7: TP_MAG_TACH; TestPoint_Pad_D1.0mm; MPN TP_MAG_TACH
TP9: TP_OPT_TACH; TestPoint_Pad_D1.0mm; MPN TP_OPT_TACH
TP10: TP_ACCEL_DRDY; TestPoint_Pad_D1.0mm; MPN TP_ACCEL_DRDY
U1: ESP32-S3-MINI-1-N8; ESP32-S2-MINI-1; MPN ESP32-S3-MINI-1-N8
U2: IIS3DWBTR; LGA-14_3x2.5mm_P0.5mm_LayoutBorder3x4y; MPN IIS3DWBTR
U3: LM1815MX/NOPB; SOIC-14_3.9x8.7mm_P1.27mm; MPN LM1815MX/NOPB
U5: BQ24075RGT; QFN-16-1EP_3x3mm_P0.5mm_EP1.675x1.675mm; MPN BQ24075RGTR
U6: TPS63031DSKR; WSON-10-1EP_2.5x2.5mm_P0.5mm_EP1.2x2mm; MPN TPS63031DSKR
U7: SRV05-4MR6T1G; SOT-23-6; MPN SRV05-4MR6T1G
U9: SN74LVC1G132DBVR; SOT-23-5; MPN SN74LVC1G132DBVR
U10: SN74LVC1G123DCTR; SSOP-8_2.95x2.8mm_P0.65mm; MPN SN74LVC1G123DCTR

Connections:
/+3V3: C6.1, C7.1, C8.1, C9.1, C13.1, C14.1, C15.1, C16.1, C17.1, C27.1, C29.1, J4.1, J5.7, R4.1, R8.1, R9.1, R15.1, R16.1, R30.1, R37.1, R38.1, TP1.1 (1_1), U1.3 (3V3), U2.5 (VDD_IO), U2.8 (VDD), U3.8 (VCC), U6.1 (VOUT), U6.10 (FB), U9.5 (VCC), U10.2 (B), U10.3 (~CLR), U10.8 (VCC)
/ACCEL_CS: U1.21 (IO17), U2.12 (CS)
/ACCEL_DRDY: TP10.1 (1_1), U1.10 (IO6), U2.4 (INT1)
/ACCEL_MISO: U1.20 (IO16), U2.1 (SDO)
/ACCEL_MOSI: U1.19 (IO15), U2.14 (SDI)
/ACCEL_SCK: U1.18 (IO14), U2.13 (SPC)
/ACQUIRE_BUTTON: C11.1, R8.2, SW2.2, U1.14 (IO10)
/BAT: C3.1, Q5.3 (D), TP3.1 (1_1), U5.2 (BAT), U5.3 (BAT)
/BOOT: R9.2, SW3.2, U1.4 (IO0)
/BPS_GATE: C31.2, Q4.1 (G), Q5.1 (G), R41.2, R42.1
/BPS_SRC: C31.1, Q4.2 (S), Q5.2 (S), R41.1
/CHG_EN1: U1.9 (IO5), U5.6 (EN1)
/CHG_EN2: U1.22 (IO18), U5.5 (EN2)
/CHG_STAT: R38.2, U1.34 (IO38), U5.9 (~CHG)
/GPS_PPS: J4.5, U1.17 (IO13)
/GPS_UART_RX: J4.3, U1.6 (IO2)
/GPS_UART_TX: J4.4, U1.5 (IO1)
/ILIM: R35.1, U5.12 (ILIM)
/ISET: R3.1, U5.16 (ISET)
/MAG_TACH: R15.2, TP7.1 (1_1), U1.11 (IO7), U3.12 (PULSE_OC)
/OPT_COMP: J5.5, R39.1, U9.1
/OPT_LED_EN: J5.3, R29.2, U1.13 (IO9)
/OPT_TACH: TP9.1 (1_1), U1.12 (IO8), U10.5 (Q)
/PGOOD_N: R37.2, U1.25 (IO21), U5.7 (~PGOOD)
/STATUS_LED: R10.1, U1.15 (IO11)
/SUPPLY_SENSE: C12.1, R11.2, R12.1, U1.16 (IO12)
/SYS: C30.1, SW1.1 (A), U5.10 (OUT), U5.11 (OUT)
/SYS_SW: C4.1, C5.1, J5.1, R11.1, SW1.2 (B), U6.5 (VIN), U6.6 (EN), U6.7 (PS/SYNC), U6.8 (VINA)
/TS: R36.1, U5.1 (TS)
/USB_CONN_D+: J1.A6 (D+), J1.B6 (D+), R7.1, U7.3 (IO2), U7.4 (IO3)
/USB_CONN_D-: J1.A7 (D-), J1.B7 (D-), R6.1, U7.1 (IO1), U7.6 (IO4)
/USB_VBUS: C1.1, C2.1, D3.1 (A1), J1.A4 (VBUS), J1.A9 (VBUS), J1.B4 (VBUS), J1.B9 (VBUS), U5.13 (IN), U7.5 (VP)
GND: C1.2, C2.2, C3.2, C4.2, C5.2, C6.2, C7.2, C8.2, C9.2, C10.2, C11.2, C12.2, C13.2, C14.2, C15.2, C16.2, C17.2, C18.2, C19.2, C26.2, C27.2, C29.2, C30.2, D3.2 (A2), J1.A1 (GND), J1.A12 (GND), J1.B1 (GND), J1.B12 (GND), J1.SH (SHIELD), J2.2, J3.2, J4.2, J5.2, J5.4, J5.6, LED1.1 (K), Q6.2 (S), R1.1, R2.1, R3.2, R12.2, R17.2, R35.2, R36.2, R39.2, R40.2, R44.2, SW2.1, SW3.1, TP2.1 (1_1), U1.1 (GND), U1.2 (GND), U1.42 (GND), U1.43 (GND), U1.46 (GND), U1.47 (GND), U1.48 (GND), U1.49 (GND), U1.50 (GND), U1.51 (GND), U1.52 (GND), U1.53 (GND), U1.54 (GND), U1.55 (GND), U1.56 (GND), U1.57 (GND), U1.58 (GND), U1.59 (GND), U1.60 (GND), U1.61 (GND), U1.62 (GND), U1.63 (GND), U1.64 (GND), U1.65 (GND), U2.2 (RES_GND), U2.3 (RES_GND), U2.6 (GND), U2.7 (GND), U3.2 (GND), U3.9 (TIMING_IN), U3.11 (INPUT_SEL), U5.4 (~CE), U5.8 (VSS), U5.15 (SYSOFF), U5.17 (EP), U6.3 (PGND), U6.9 (GND), U6.11 (PGND), U7.2 (VN), U9.3 (GND), U10.4 (GND)
unnamed: C26.1, R29.1, R40.1, U9.2
unnamed: J1.A5 (CC1), R1.2
unnamed: J1.B5 (CC2), R2.2
unnamed: J2.1, Q4.3 (D), R43.1
unnamed: J3.1, R13.2
unnamed: LED1.2 (A), R10.2
unnamed: Q6.3 (D), R42.2
unnamed: Q6.1 (G), R43.2, R44.1
unnamed: R13.1, R14.2
unnamed: C10.1, R4.2, U1.45 (EN)
unnamed: R7.2, U1.24 (USB_D+)
unnamed: R6.2, U1.23 (USB_D-)
unnamed: C19.1, R17.1, U3.7 (PEAK_DET)
unnamed: C18.1, R16.2, U3.14 (RC_TIMING)
unnamed: R14.1, U3.3 (VR_IN)
unnamed: L1.1, U6.4 (L1)
unnamed: L1.2, U6.2 (L2)
unnamed: C28.2, U10.6 (Cext)
unnamed: C28.1, R30.2, U10.7 (RCext)
unnamed: U9.4, U10.1 (~A)

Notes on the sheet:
Battery Circuit
BATTERY POWER / USB - CHARGES WITH SW1 ON OR OFF
MCU / BLE - ESP32-S3
HOBOVibe Hobby Helicopter Dynamic Balancer
ACCELEROMETER - IIS3DWB (SPI)
MAIN ROTOR MAG TACH
TAIL ROTOR OPTICAL TACH - PULSED EMITTER + RECEIVER

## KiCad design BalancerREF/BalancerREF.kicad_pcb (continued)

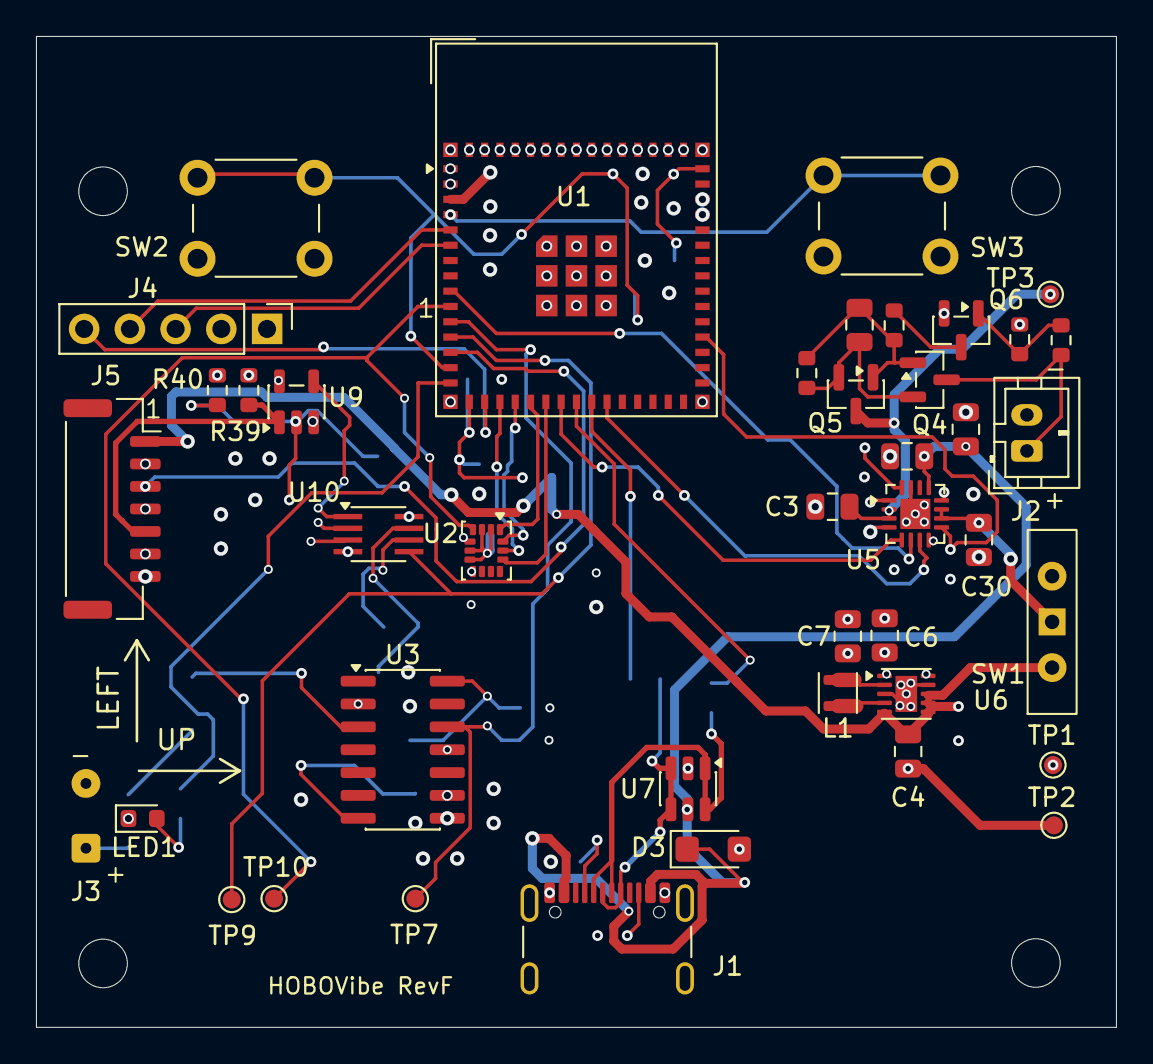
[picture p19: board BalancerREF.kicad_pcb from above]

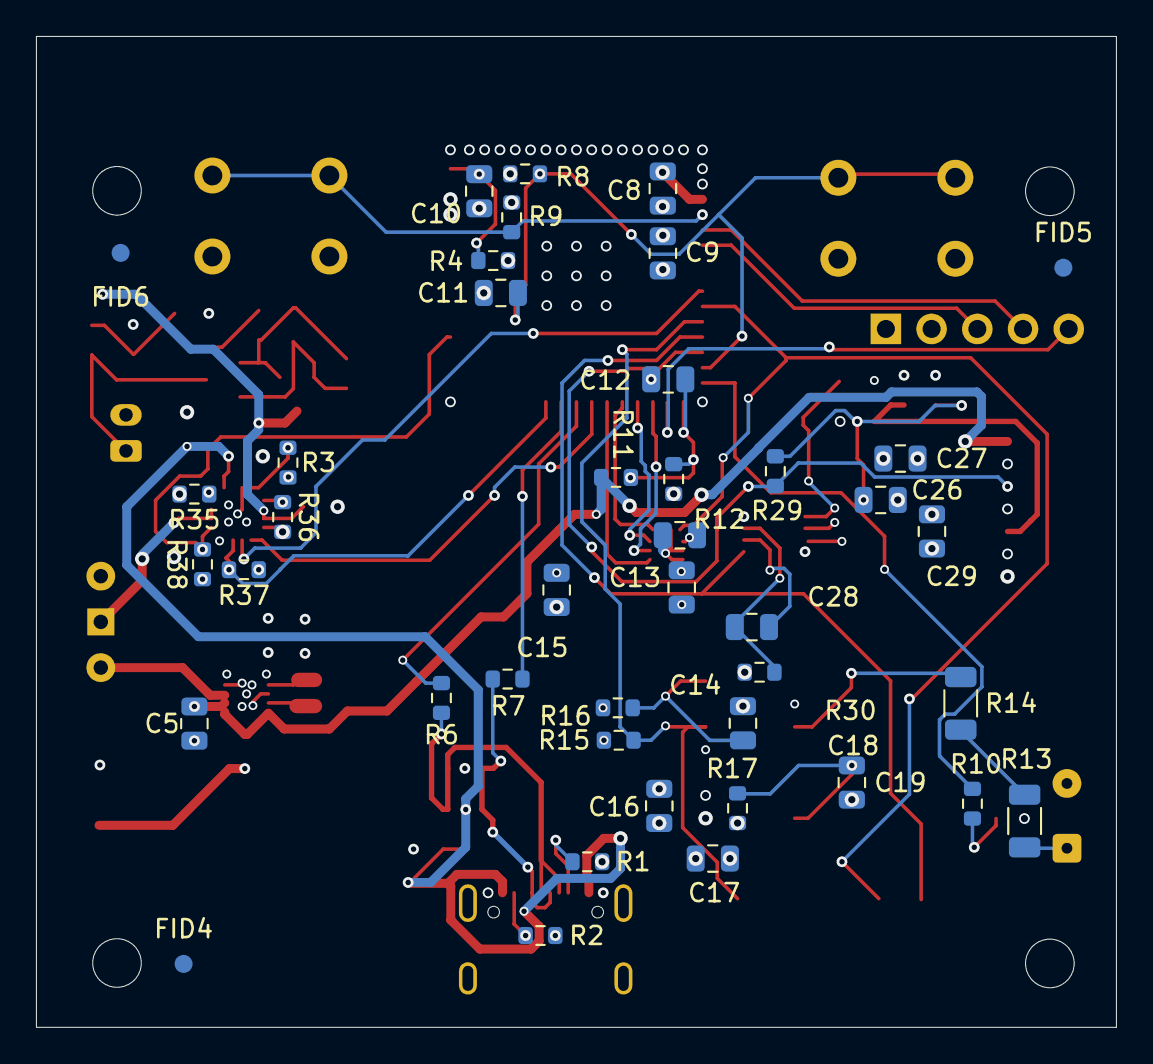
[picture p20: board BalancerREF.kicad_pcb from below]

Board: 4 copper layers, 60.0 x 55.0 mm, 88 parts (42 on the bottom side), 53 nets.

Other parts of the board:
FID4, FID5, FID6: FIDUCIAL; Fiducial_1mm_Mask2mm
H1, H2, H3, H4: M2.5 MOUNT; MountingHole_2.7mm_M2.5

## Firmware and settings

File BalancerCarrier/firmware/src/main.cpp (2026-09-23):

#include "board.hpp"
#include "fuelgauge.hpp"
#include "measurement.hpp"
#include "ble.hpp"
#include "flightlog.hpp"
#include "gps.hpp"
#include "storage.hpp"
#include "accel.hpp"
#include <atomic>
#include <cmath>
#include <cstdio>
#include <cstring>
#include <algorithm>
extern "C" {
#include "driver/gpio.h"
#include "driver/ledc.h"
#include "driver/mcpwm_cap.h"
#include "driver/usb_serial_jtag.h"
#include "esp_timer.h"
#include "esp_sleep.h"
#include "esp_log.h"
#include "nvs_flash.h"
#include "nvs.h"
#include "freertos/FreeRTOS.h"
#include "freertos/task.h"
#include "freertos/queue.h"
#include "cJSON.h"
}
namespace {
constexpr char version[]="0.4.0-reference";
enum Kind:uint8_t { Drdy=0,Mag=1,Opt=2,Data=3 };
struct Capture {uint32_t tick;int64_t wall;Kind kind;};
struct Event {uint32_t tick;int64_t wall;Kind kind;float g[3];uint8_t clipped;};
struct Command {char text[256];};
struct Message {char text[3072];};
QueueHandle_t captureQueue,eventQueue,commandQueue,outputQueue;
std::atomic<uint32_t> captureLost{0},dataLost{0},ioErrors{0},timingErrors{0},outputLost{0};
std::atomic<bool> sensorOk{false};
std::atomic<float> liveG[3]{};
std::atomic<uint32_t> liveSampleMs{0};
double ticksPerSample=0; // capture ticks per 26.7 kHz accelerometer sample
uint32_t captureHz;
puck::Config configs[2];int profile=0;
const char *profileName() {return profile?"TR-VERT":"MR-VERT";}
struct SettingsV1 {uint32_t magic=0x42524631,version=1;int profile=0;puck::Config config[2];};
struct Settings {uint32_t magic=0x42524631,version=2;int profile=0;puck::Config config[2];bool flight=false;};
// Flight mode: autonomous continuous acquisition, GPS-tagged log, BLE off, sleep on no tach.
bool flightMode=false,usbPaused=false;
constexpr int64_t noTachSleepUs=180*1000000LL; // idle rotor for 3 minutes -> deep sleep
constexpr int64_t minAwakeUs=180*1000000LL;    // never sleep sooner than this after boot
int64_t lastTachSeen=0;
flight::Gate gate;
uint32_t lastFixSequence=0;
const char *wakeNote="power-on";
puck::Measurement measurement;
bool running=false,haveResult=false,continuous=false;
uint32_t sequence=0; // results emitted in the current continuous session
puck::Result lastResult;
puck::Config lastConfig;
int lastProfile=0;
uint32_t runId=0;
int64_t runStart=0,lastDrdy=0,lastTach=0;
uint32_t startCaptureLost=0,startDataLost=0,startIo=0,startTiming=0;
struct History {uint32_t run;double rpm,raw,phase;};
History history[2][20]{};unsigned historyCount[2]{};

void emit(cJSON *json) {
    Message m{};
    cJSON_AddStringToObject(json,"firmware",version);
    if(cJSON_PrintPreallocated(json,m.text,sizeof(m.text)-2,false)) {
        std::strcat(m.text,"\n");if(xQueueSend(outputQueue,&m,0)!=pdTRUE) ++outputLost;
    } else ++outputLost;
    cJSON_Delete(json);
}
void response(const char *type,const char *message) {
    auto *j=cJSON_CreateObject();cJSON_AddStringToObject(j,"type",type);
    cJSON_AddStringToObject(j,"message",message);emit(j);
}
void num(cJSON *j,const char *key,double v) {if(std::isfinite(v)) cJSON_AddNumberToObject(j,key,v);else cJSON_AddNullToObject(j,key);}
void configJson(cJSON *j,const puck::Config &c) {
    const char *axes[]={"X","Y","Z"};
    cJSON_AddStringToObject(j,"axis",axes[c.axis]);num(j,"sign",c.sign);num(j,"gain",c.gain);
    num(j,"phase_direction",c.phaseDirection);num(j,"phase_offset_deg",c.phaseOffsetDeg);
    num(j,"duration_s",c.durationS);num(j,"min_rpm",c.minRpm);num(j,"max_rpm",c.maxRpm);
    cJSON_AddBoolToObject(j,"axis_confirmed",c.axisConfirmed);
}
bool saveSettings() {
    Settings s;s.profile=profile;s.config[0]=configs[0];s.config[1]=configs[1];s.flight=flightMode;
    nvs_handle_t h;if(nvs_open("puck",NVS_READWRITE,&h)!=ESP_OK)return false;
    esp_err_t e=nvs_set_blob(h,"settings",&s,sizeof(s));if(e==ESP_OK)e=nvs_commit(h);nvs_close(h);return e==ESP_OK;
}
void loadSettings() {
    nvs_handle_t h; if(nvs_open("puck",NVS_READONLY,&h)!=ESP_OK)return;
    Settings s;size_t n=sizeof(s);const auto e=nvs_get_blob(h,"settings",&s,&n);nvs_close(h);
    if(e!=ESP_OK || s.magic!=0x42524631)return;
    if(n==sizeof(SettingsV1) && s.version==1)s.flight=false;          // upgrade from 0.2.0 settings
    else if(n!=sizeof(Settings) || s.version!=2)return;
    if((s.profile==0||s.profile==1) && puck::validConfig(s.config[0]) && puck::validConfig(s.config[1])) {
        configs[0]=s.config[0];configs[1]=s.config[1];profile=s.profile;flightMode=s.flight;
    }
}
// Rev C emitter: 20 kHz, 10 percent duty pulses into Q1 (about 500 mA peak through D1).
// The same signal, RC-delayed, gates the receiver comparator for synchronous detection.
constexpr uint32_t emitterHz=20000;constexpr uint32_t emitterDuty=102; // 10 bits: 102/1024 = 10 percent
void setupEmitter() {
    ledc_timer_config_t t{};t.speed_mode=LEDC_LOW_SPEED_MODE;t.timer_num=LEDC_TIMER_0;t.duty_resolution=LEDC_TIMER_10_BIT;
    t.freq_hz=emitterHz;t.clk_cfg=LEDC_AUTO_CLK;ESP_ERROR_CHECK(ledc_timer_config(&t));
    ledc_channel_config_t c{};c.speed_mode=LEDC_LOW_SPEED_MODE;c.channel=LEDC_CHANNEL_0;c.timer_sel=LEDC_TIMER_0;
    c.intr_type=LEDC_INTR_DISABLE;c.gpio_num=board::emitter;c.duty=0;c.hpoint=0;ESP_ERROR_CHECK(ledc_channel_config(&c));
}
void setEmitter(bool on) {
    ledc_set_duty(LEDC_LOW_SPEED_MODE,LEDC_CHANNEL_0,on?emitterDuty:0);ledc_update_duty(LEDC_LOW_SPEED_MODE,LEDC_CHANNEL_0);
}
bool IRAM_ATTR captureCallback(mcpwm_cap_channel_handle_t,const mcpwm_capture_event_data_t *data,void *ctx) {
    Capture c{data->cap_value,esp_timer_get_time(),*static_cast<Kind*>(ctx)};
    BaseType_t wake=pdFALSE;
    if(xQueueSendFromISR(captureQueue,&c,&wake)!=pdTRUE) captureLost.fetch_add(1,std::memory_order_relaxed);
    return wake==pdTRUE;
}
void setupCapture() {
    mcpwm_capture_timer_config_t t{};t.group_id=0;t.clk_src=MCPWM_CAPTURE_CLK_SRC_DEFAULT;
    mcpwm_cap_timer_handle_t timer;ESP_ERROR_CHECK(mcpwm_new_capture_timer(&t,&timer));
    ESP_ERROR_CHECK(mcpwm_capture_timer_get_resolution(timer,&captureHz));
    static Kind kinds[3]={Drdy,Mag,Opt};const int gpio[3]={board::drdy,board::mag,board::opt};
    for(int i=0;i<3;i++) {
        mcpwm_capture_channel_config_t c{};c.gpio_num=gpio[i];c.prescale=1;
        c.flags.pos_edge=i!=1;c.flags.neg_edge=i==1; // MAG leading low; OPT reflection high
        mcpwm_cap_channel_handle_t ch;ESP_ERROR_CHECK(mcpwm_new_capture_channel(timer,&c,&ch));
        mcpwm_capture_event_callbacks_t callbacks{};callbacks.on_cap=captureCallback;
        ESP_ERROR_CHECK(mcpwm_capture_channel_register_event_callbacks(ch,&callbacks,&kinds[i]));
        ESP_ERROR_CHECK(mcpwm_capture_channel_enable(ch));
    }
    ESP_ERROR_CHECK(mcpwm_capture_timer_enable(timer));ESP_ERROR_CHECK(mcpwm_capture_timer_start(timer));
}
void sensorTask(void *) {
    Capture c;
    for(;;) {
        if(xQueueReceive(captureQueue,&c,portMAX_DELAY)!=pdTRUE)continue;
        Event e{};e.tick=c.tick;e.wall=c.wall;e.kind=c.kind;
        if(c.kind==Drdy) {
            accel::Block b;unsigned n=0;
            if(!sensorOk || !accel::readBlock(b,n)) {++ioErrors;continue;}
            // A block read landing after the next watermark is stale. Never silently accept it.
            if(esp_timer_get_time()-c.wall>500) {++timingErrors;continue;}
            // The watermark marks the last sample of the block; the block mean sits (N-1)/2 samples earlier.
            e.tick=c.tick-uint32_t(ticksPerSample*(accel::decimation-1)/2.0+0.5);
            for(int a=0;a<3;a++) {e.g[a]=b.g[a];liveG[a]=b.g[a];}
            e.clipped=b.clipped;
            liveSampleMs=uint32_t(esp_timer_get_time()/1000);
            e.kind=Data;
        }
        if(xQueueSend(eventQueue,&e,0)!=pdTRUE) ++dataLost;
    }
}
// The FeatherS3[D] owns power. LDO2 (an NCP167BMX330TBG, 700 mA) feeds J4 pin 1, so
// the GPS is dead until this is raised - the default state is off, which is the safe
// direction. LDO2 also feeds the module's RGB LED and the second STEMMA connector.
// vbusSense reads the module's own USB-present divider and replaces BalancerREF's
// pgood pin.
void setupPower() {
    gpio_config_t o{};o.pin_bit_mask=1ULL<<board::ldo2;o.mode=GPIO_MODE_OUTPUT;
    ESP_ERROR_CHECK(gpio_config(&o));
    gpio_config_t i{};i.pin_bit_mask=1ULL<<board::vbusSense;i.mode=GPIO_MODE_INPUT;
    ESP_ERROR_CHECK(gpio_config(&i));
    fuelgauge::setup();          // logs and degrades to NAN readings if absent
}
void setGpsPower(bool on){gpio_set_level(gpio_num_t(board::ldo2),on?1:0);}
// There is no charger on the carrier: the FeatherS3[D] does charging itself, with a
// MAX17048 fuel gauge reporting the result over I2C. BalancerREF's setupCharger() and
// its EN1/EN2/PGOOD/CHG pins are gone. Leaving them would have been actively harmful -
// on this board GPIO5 is the acquire button and GPIO18 is the IIS3DWB's INT1, and that
// code drove both as outputs.
bool inputPresent(){return gpio_get_level(gpio_num_t(board::vbusSense))==1;}
bool charging(){return fuelgauge::charging();}
// The cell itself, straight off the gauge, rather than BalancerREF's SYS_SW/2 on
// ADC2_CH1 - which shared its ADC unit with the radio and could not read the cell at
// all while charging.
double supplyVolts(){return fuelgauge::cellVolts();}
void status() {
    auto *j=cJSON_CreateObject();cJSON_AddStringToObject(j,"type","status");
    cJSON_AddStringToObject(j,"profile",profileName());cJSON_AddBoolToObject(j,"acquiring",running);cJSON_AddBoolToObject(j,"continuous",continuous);num(j,"sequence",sequence);
    cJSON_AddBoolToObject(j,"sensor_ok",sensorOk);cJSON_AddBoolToObject(j,"reference_only",true);
    cJSON_AddBoolToObject(j,"ble_connected",ble_connected());num(j,"sample_rate_hz",accel::sampleRateHz);
    num(j,"full_scale_g",accel::fullScaleG);num(j,"lpf_nominal_hz",accel::odrHz/accel::lpfDivider);num(j,"decimation",accel::decimation);
    cJSON_AddStringToObject(j,"sensor","IIS3DWB SPI");num(j,"capture_hz",captureHz);
    num(j,"battery_v",supplyVolts());num(j,"output_drops",outputLost);
    cJSON_AddBoolToObject(j,"input_present",inputPresent());cJSON_AddBoolToObject(j,"charging",charging());
    num(j,"battery_soc_pct",fuelgauge::stateOfCharge());num(j,"battery_rate_pct_hr",fuelgauge::chargeRate());
    cJSON_AddBoolToObject(j,"fuel_gauge_ok",fuelgauge::present());
    num(j,"capture_drops",captureLost);num(j,"sample_queue_drops",dataLost);
    num(j,"i2c_errors",ioErrors);num(j,"late_reads",timingErrors);
    cJSON_AddBoolToObject(j,"flight",flightMode);cJSON_AddBoolToObject(j,"usb",usb_serial_jtag_is_connected());
    cJSON_AddStringToObject(j,"wake",wakeNote);
    auto *log=cJSON_AddObjectToObject(j,"log");cJSON_AddBoolToObject(log,"mounted",storage::mounted());
    num(log,"records",storage::records());num(log,"bytes",storage::used());num(log,"capacity",storage::total());
    cJSON_AddBoolToObject(log,"full",storage::full());num(log,"write_failures",storage::writeFailures());
    auto *g=cJSON_AddObjectToObject(j,"gps");const auto fix=gps::latest();
    cJSON_AddBoolToObject(g,"present",gps::present());cJSON_AddBoolToObject(g,"fix",fix.valid);
    num(g,"sats",fix.sats);num(g,"speed_mps",fix.speedMps);num(g,"course_deg",fix.courseDeg);
    num(g,"sentences",gps::sentences());num(g,"rejected",gps::rejected());num(g,"baud",gps::baud());
    char iso[24];if(flight::isoTime(fix,iso,sizeof(iso)))cJSON_AddStringToObject(g,"utc",iso);else cJSON_AddNullToObject(g,"utc");
    if(liveSampleMs && uint32_t(esp_timer_get_time()/1000)-liveSampleMs.load()<20) {
        auto *xyz=cJSON_AddArrayToObject(j,"latest_xyz_g");
        for(int a=0;a<3;a++)cJSON_AddItemToArray(xyz,cJSON_CreateNumber(liveG[a]));
    } else cJSON_AddNullToObject(j,"latest_xyz_g");
    auto *c=cJSON_AddObjectToObject(j,"config");configJson(c,configs[profile]);emit(j);
}
void resultJson(const puck::Result &r) {
    auto *j=cJSON_CreateObject();cJSON_AddStringToObject(j,"type","result");
    cJSON_AddBoolToObject(j,"reference_only",true);num(j,"run_id",runId);
    cJSON_AddStringToObject(j,"profile",profileName());cJSON_AddBoolToObject(j,"continuous",continuous);num(j,"sequence",sequence);
    cJSON_AddBoolToObject(j,"valid",r.valid);
    cJSON_AddBoolToObject(j,"stable",r.stable);cJSON_AddBoolToObject(j,"phase_valid",r.phaseValid);
    cJSON_AddBoolToObject(j,"direction_valid",r.directionValid);
    cJSON_AddStringToObject(j,"quality",r.quality==puck::Quality::StableVector?"stable_vector":
        r.quality==puck::Quality::DirectionOnly?"direction_only":"unreliable");
    if(r.flags&puck::Clipping)cJSON_AddStringToObject(j,"message","overrange on selected axis; check mounting and repeat");
    num(j,"flags",r.flags);num(j,"rpm",r.rpm);num(j,"rpm_cv",r.rpmCv);
    num(j,"revolutions",r.revolutions);num(j,"samples",r.samples);num(j,"rejected_tach_edges",r.rejectedEdges);
    num(j,"raw_vector_scatter_ips_peak",r.vectorScatter);num(j,"raw_amplitude_scatter_ips_peak",r.amplitudeScatter);
    num(j,"per_rev_phase_scatter_deg",r.phaseScatterDeg);
    auto *axes=cJSON_AddArrayToObject(j,"raw_axes");const char *names[]={"X","Y","Z"};
    for(int a=0;a<3;a++) {
        auto *v=cJSON_CreateObject();cJSON_AddStringToObject(v,"axis",names[a]);
        num(v,"ips_peak",r.rawPeak[a]);num(v,"ips_rms",r.rawPeak[a]/std::sqrt(2.0));
        num(v,"velocity_phase_deg",r.rawPhase[a]);num(v,"dc_g",r.dcG[a]);
        cJSON_AddBoolToObject(v,"clipped",(r.clippedAxes>>a)&1);cJSON_AddItemToArray(axes,v);
    }
    num(j,"adjusted_ips_peak",r.peak);num(j,"adjusted_ips_rms",r.rms);
    // Direction-only runs keep their phase for rough correction; calibration still needs phase_valid.
    if(r.directionValid)num(j,"adjusted_velocity_phase_deg",r.phase);else cJSON_AddNullToObject(j,"adjusted_velocity_phase_deg");
    num(j,"signed_acceleration_phase_deg",r.accelerationPhase);
    cJSON_AddStringToObject(j,"raw_phase_definition","positive velocity peak after selected tach edge; time-forward degrees");
    auto *c=cJSON_AddObjectToObject(j,"config");configJson(c,configs[profile]);
    const unsigned n=historyCount[profile];
    if(r.stable && n && std::abs(history[profile][(n-1)%20].rpm-r.rpm)/r.rpm<0.02)
        num(j,"raw_delta_ips_peak",r.rawPeak[configs[profile].axis]-history[profile][(n-1)%20].raw);
    else cJSON_AddNullToObject(j,"raw_delta_ips_peak");
    emit(j);
    if(r.stable) {
        history[profile][n%20]={runId,r.rpm,r.rawPeak[configs[profile].axis],r.rawPhase[configs[profile].axis]};
        ++historyCount[profile];
    }
}
void logWindow(const puck::Result &r) {
    if(!flightMode || (r.flags&puck::Cancelled))return;
    const auto &c=configs[profile];
    flight::Record rec;rec.seq=sequence;rec.run=runId;rec.flags=r.flags;rec.uptimeMs=uint32_t(esp_timer_get_time()/1000);
    rec.profile=profileName();rec.valid=r.valid;rec.stable=r.stable;rec.phaseValid=r.phaseValid;
    rec.rpm=r.rpm;rec.rpmCv=r.rpmCv;rec.scatter=r.vectorScatter;rec.axis=c.axis;rec.sign=c.sign;
    for(int a=0;a<3;a++){rec.peak[a]=r.rawPeak[a];rec.phase[a]=r.rawPhase[a];rec.dc[a]=r.dcG[a];}
    rec.fix=gps::latest();rec.fixes=gate.fixes();rec.speedMean=gate.meanSpeed();
    rec.speedSpread=gate.speedSpread();rec.courseSpread=gate.courseSpreadDeg();
    rec.level=gate.level(r.dcG[c.axis]*c.sign,r.stable);
    char line[640];
    if(flight::formatRecord(rec,line,sizeof(line)))storage::append(line);
}
void logBoot() {
    flight::Record rec;rec.type="boot";rec.uptimeMs=uint32_t(esp_timer_get_time()/1000);rec.note=wakeNote;rec.fix=gps::latest();
    char line[200];if(flight::formatRecord(rec,line,sizeof(line)))storage::append(line);
}
void beginRun() {
    gate.reset();
    measurement.begin(configs[profile],captureHz);++runId;running=true;haveResult=false;
    runStart=esp_timer_get_time();lastTach=lastDrdy=0;
    startCaptureLost=captureLost;startDataLost=dataLost;startIo=ioErrors;startTiming=timingErrors;
}
// repeat=true keeps acquiring back to back until stop, the button, or a sensor failure.
void startRun(bool repeat=false) {
    if(running) {response("error","already acquiring");return;}
    if(!sensorOk) {response("error","IIS3DWB initialization failed; check SPI wiring and reboot");return;}
    continuous=repeat;sequence=0;beginRun();
    auto *j=cJSON_CreateObject();cJSON_AddStringToObject(j,"type","started");
    cJSON_AddStringToObject(j,"message",profileName());cJSON_AddStringToObject(j,"profile",profileName());
    cJSON_AddBoolToObject(j,"continuous",continuous);num(j,"duration_s",configs[profile].durationS);emit(j);
}
void finishRun(bool cancelled=false) {
    if(!running)return;
    if(captureLost!=startCaptureLost || dataLost!=startDataLost)measurement.fault(puck::QueueOverflow);
    if(ioErrors!=startIo)measurement.fault(puck::IoError);
    if(timingErrors!=startTiming)measurement.fault(puck::TimingError);
    if(!lastDrdy || esp_timer_get_time()-lastDrdy>5000)measurement.fault(puck::SampleGap);
    if(cancelled)measurement.fault(puck::Cancelled);
    const double timeoutUs=measurement.tachTimeoutSeconds()*1e6;
    lastResult=measurement.finish(lastTach && esp_timer_get_time()-lastTach<timeoutUs);
    running=false;haveResult=true;lastConfig=configs[profile];lastProfile=profile;
    if(continuous)++sequence;
    resultJson(lastResult);
    logWindow(lastResult);
    if(cancelled)continuous=false;
    // Sampling never stops between windows, so the next window starts immediately.
    if(continuous) {
        if(sensorOk)beginRun();
        else {continuous=false;response("error","sensor failure ended continuous acquisition");}
    }
}
// Deep sleep wakes on EXT1: a magnetic tach pulse (rotor spin-up) or an acquire-button press.
// The optical profile has no wake source while the emitter is off; flight logging uses MR-VERT.
void goToSleep() {
    if(running)finishRun(true);
    storage::sync();gps::sleep();
    gpio_set_level(gpio_num_t(board::led),0);setEmitter(false);
    accel::powerDown();
    // MAG_TACH (LM1815 open collector, 5.6k pull-up) and the acquire button both idle high and pulse low.
    esp_sleep_enable_ext1_wakeup((1ULL<<board::mag)|(1ULL<<board::acquire),ESP_EXT1_WAKEUP_ANY_LOW);
    esp_deep_sleep_start();
}
void changeProfile(int p) {
    if(p==profile) {response("profile",profileName());return;}
    const int old=profile;profile=p;
    if(!saveSettings()) {profile=old;response("error","NVS save failed; profile unchanged");return;}
    setEmitter(profile==1);
    haveResult=false;response("profile",profileName());
}
bool readNumber(cJSON *j,const char *key,double &out) {
    auto *v=cJSON_GetObjectItemCaseSensitive(j,key);if(!v)return true;
    if(!cJSON_IsNumber(v) || !std::isfinite(v->valuedouble))return false;
    out=v->valuedouble;return true;
}
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
extern "C" void app_main() {
    gpio_config_t out{};out.pin_bit_mask=(1ULL<<board::led);out.mode=GPIO_MODE_OUTPUT;
    ESP_ERROR_CHECK(gpio_config(&out));setupEmitter();setupPower();
    gpio_config_t in{};in.pin_bit_mask=1ULL<<board::acquire;in.mode=GPIO_MODE_INPUT;in.pull_up_en=GPIO_PULLUP_ENABLE;
    ESP_ERROR_CHECK(gpio_config(&in));
    usb_serial_jtag_driver_config_t usb{};usb.rx_buffer_size=512;usb.tx_buffer_size=4096;
    ESP_ERROR_CHECK(usb_serial_jtag_driver_install(&usb));
    const esp_err_t nvs=nvs_flash_init(); // never silently erase calibration/settings
    if(nvs==ESP_OK)loadSettings();
    captureQueue=xQueueCreate(64,sizeof(Capture));eventQueue=xQueueCreate(256,sizeof(Event));
    commandQueue=xQueueCreate(4,sizeof(Command));outputQueue=xQueueCreate(4,sizeof(Message));
    configASSERT(captureQueue && eventQueue && commandQueue && outputQueue);
    switch(esp_sleep_get_wakeup_cause()){case ESP_SLEEP_WAKEUP_EXT1:wakeNote="wake:tach-or-button";break;
        case ESP_SLEEP_WAKEUP_UNDEFINED:wakeNote="power-on";break;default:wakeNote="wake:other";}
    sensorOk=accel::setup();setupCapture();ticksPerSample=double(captureHz)/accel::odrHz;
    storage::mount();setGpsPower(true);gps::start();
    setEmitter(profile==1);
    configASSERT(xTaskCreatePinnedToCore(sensorTask,"sensor",4096,nullptr,22,nullptr,1)==pdPASS);
    if(sensorOk && !accel::start())sensorOk=false;
    // Let the filter settle and drain initial timing transients before accepting runs.
    vTaskDelay(pdMS_TO_TICKS(100));
    if(!flightMode)ble_start();   // flight mode: nothing to talk to in the air; BLE returns on reboot
    lastTachSeen=esp_timer_get_time();
    if(flightMode)logBoot();
    response("boot","BalancerREF reference firmware; send {\"cmd\":\"status\"}");
    if(nvs!=ESP_OK)response("error","NVS initialization failed; defaults active, persistent settings unavailable");
    configASSERT(xTaskCreatePinnedToCore(analysisTask,"analysis",12288,nullptr,8,nullptr,1)==pdPASS);
    char line[256];unsigned used=0;bool overflow=false;Message message;
    for(;;) {
        char bytes[64];const int n=usb_serial_jtag_read_bytes(bytes,sizeof(bytes),0);
        for(int i=0;i<n;i++) {
            const char c=bytes[i];if(c=='\r')continue;
            if(c=='\n') {
                if(!overflow && used && !submit_command(line,used))response("error","command queue busy");
                if(overflow)response("error","command too long or contains NUL");
                used=0;overflow=false;
            } else if(c==0 || used>=sizeof(line)-1)overflow=true;
            else if(!overflow)line[used++]=c;
        }
        if(xQueueReceive(outputQueue,&message,0)==pdTRUE) {
            const size_t length=std::strlen(message.text);
            const int sent=usb_serial_jtag_write_bytes(message.text,length,pdMS_TO_TICKS(20));
            if(sent<int(length)) {++outputLost;usb_serial_jtag_write_bytes("\n",1,pdMS_TO_TICKS(5));}
            ble_send_line(message.text);
        }
        vTaskDelay(pdMS_TO_TICKS(5));
    }
}

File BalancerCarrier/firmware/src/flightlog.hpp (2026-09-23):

#pragma once
// In-flight logging support with no ESP dependencies: NMEA parsing, the
// level-flight gate, and the terse one-line record format. Compiled and tested
// unchanged on the host (tests/test_flightlog.cpp).
#include <cstddef>
#include <cstdint>

namespace flight {

struct Fix {
    bool valid = false;        // RMC status A with a position
    bool timeValid = false;    // RMC date and time present
    double lat = 0, lon = 0;   // degrees, south/west negative
    double speedMps = 0;       // ground speed
    double courseDeg = 0;      // track over ground, 0-360
    double altM = 0;           // GGA MSL altitude
    int sats = 0;              // GGA satellites used
    int year = 0, month = 0, day = 0, hour = 0, minute = 0;
    double second = 0;
};

// Incremental NMEA 0183 parser for RMC and GGA from any talker (GP/GN/GA...).
class Nmea {
public:
    // Feed one byte; returns true when a complete, checksum-valid RMC or GGA updated the fix.
    bool feed(char c);
    const Fix &fix() const { return fix_; }
    // Advances once per parsed RMC, the only sentence carrying speed and course. The flight
    // gate samples on this, so a GGA in the same epoch never counts the fix twice.
    uint32_t motionSequence() const { return motion_; }
    uint32_t sentences() const { return sentences_; }
    uint32_t rejected() const { return rejected_; }
private:
    bool parseSentence();
    bool parseRmc(char **f, int n);
    bool parseGga(char **f, int n);
    char buf_[120]{};
    unsigned len_ = 0;
    bool inSentence_ = false;
    Fix fix_{};
    uint32_t sentences_ = 0, rejected_ = 0, motion_ = 0;
};

// Accumulates fixes over one acquisition window and decides whether the
// aircraft was in steady level forward flight, so the window can be used as a
// balance sample. Thresholds are deliberately conservative.
struct Gate {
    static constexpr double minSpeedMps = 2.0;      // must actually be moving
    static constexpr double maxSpeedSpreadMps = 1.5;
    static constexpr double maxCourseSpreadDeg = 10.0;
    static constexpr double dcTolerance = 0.06;     // |vertical DC| within 1 g +/- this
    static constexpr unsigned minFixes = 3;

    void reset();
    void add(const Fix &f);       // ignored unless f.valid
    unsigned fixes() const { return count_; }
    double meanSpeed() const;
    double speedSpread() const { return count_ ? maxSpeed_ - minSpeed_ : 0; }
    double courseSpreadDeg() const;   // circular standard deviation, degrees
    // dcVertical: mean gravity reading on the selected axis in g, sign already applied so up is +1.
    bool level(double dcVertical, bool stable) const;
private:
    unsigned count_ = 0;
    double sumSpeed_ = 0, minSpeed_ = 0, maxSpeed_ = 0, sumCos_ = 0, sumSin_ = 0;
};

// One terse log record. Numbers are raw firmware values; nothing here is calibrated.
struct Record {
    const char *type = "log";     // "log" (window) or "boot"
    uint32_t seq = 0, run = 0, flags = 0, uptimeMs = 0;
    const char *profile = "";
    const char *note = nullptr;   // boot records: wake cause etc.
    bool valid = false, stable = false, phaseValid = false;
    double rpm = 0, rpmCv = 0, scatter = 0;
    double peak[3]{}, phase[3]{}, dc[3]{};
    int axis = 2, sign = 1;
    Fix fix{};                    // latest fix at the end of the window
    bool level = false;
    unsigned fixes = 0;
    double speedMean = 0, speedSpread = 0, courseSpread = 0;
};

// Writes "YYYY-MM-DDTHH:MM:SSZ" or returns false when the fix carries no time.
bool isoTime(const Fix &f, char *out, size_t n);
// Formats one JSON line (with trailing newline) into out; returns length or 0 if it did not fit.
size_t formatRecord(const Record &r, char *out, size_t n);

}  // namespace flight

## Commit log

2026-09-11 feat: initial import of HoboBalancer KiCad projects and firmware
    Three KiCad 10 projects:
    - Balancer (STM32, Rev A) - schematic only, PCB is an empty stub
    - BalancerREF / HOBOVibe (ESP32-S3, Rev C) - schematic ERC clean,
    PCB placement in progress
    - BalancerREF_OptHead (Rev A) - optical tach head, split out 2026-09-11
    The optical front end moved to its own board so D1/PD1 can mount at 90 degrees
    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
    [Balancer.kicad_pcb, Balancer.kicad_sch, BalancerREF.kicad_pcb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]
2026-09-13 feat: split optical head to its own board, place both PCBs
    BalancerREF main board (50 x 50, 4 layer):
    - optical front end removed to BalancerREF_OptHead; J5 7-way cable connector
    added, with ground interleaved between OPT_LED_EN and OPT_COMP
    - SW4 (RESET) removed - SW1 feeds U6 VIN and EN, so the power slide already
    power-cycles the MCU; R4/C10/TP13 still hold EN high and probeable
    - R5 removed - it duplicated R9's 10k BOOT pull-up on the same net
    - all 83 footprints placed: ICs, connectors, switches and test points on the
    front, passives on the back under their own IC's power pins
    - M2.5 mounting holes at the four corners
    - UP / LEFT orientation markers on F.SilkS for vertical mountin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
    [BalancerREF.kicad_pcb, BalancerREF.kicad_sch, BalancerREF_OptHead.kicad_pcb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]
2026-09-13 feat: fiducials, net classes, and a BAT sense divider
    Fiducials (1 mm dot / 2 mm mask), three per populated face at three of the
    four corners - never four, since a symmetric set gives the placement machine
    no way to distinguish a 180-degree-rotated panel. Main board gets both faces
    (FID1-3 front, FID4-6 back); the optical head is single-sided so its back has
    none.
    Net classes set in both .kicad_pro, sized from IPC-2221 at 1 oz outer copper
    and a 10 C rise (0.20 mm ~ 0.74 A, 0.50 ~ 1.45 A, 0.80 ~ 2.03 A):
    Default 0.20 Power 0.50 Switch 0.80 (main) Emitter 0.80 (head) USB pair
    Switch clearance stays at 0.20 rather than 0.25: the TPS63031's WSON-10 puts
    its own L1/L2 pads 0.20 mm from it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
    [BalancerREF.kicad_pcb, BalancerREF.kicad_sch, BalancerREF_OptHead.kicad_pcb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]
2026-09-13 docs: mark the main board Rev D
    Rev D is the battery/supply sensing change: BAT_SENSE on GPIO4 alongside
    SUPPLY_SENSE, which is what lets firmware distinguish USB from battery.
    SUPPLY_SENSE alone cannot - SYS is fed from USB through D2 or from the cell
    through Q3, and a USB port at the low end of spec minus D2's drop lands near
    4.30 V against a full cell at 4.20 V, inside divider tolerance plus ADC error.
    The optical head split, the SW4 deletion and the R5 deletion all rode along in
    the same revision; none had been released under a tag.
    - BalancerREF.kicad_sch title block: rev C -> D, date 2026-09-13
    - BalancerREF/README.md: Rev D changes section; corrected the stale claim that
    no PCB ha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
    [BalancerREF.kicad_sch]
2026-09-13 feat: BQ24075 charge management, drop BAT_SENSE, sweep wire stubs
    Replaces the MCP73831 + D2 + Q3 + R27 + R31 discrete charger and power-path
    with a BQ24075RGT, which does the same job with an integrated DPPM path and
    adds what the discrete version could not: independent system/charge supply,
    operation with a defective or absent cell, USB-IF inrush limiting, and VIN-DPM
    so a weak port sags instead of collapsing.
    New support parts: R3 3.57k ISET (~249 mA, about 0.5C), R35 1.6k ILIM (~1.0 A),
    R36 10k on TS for the absent pack thermistor, R37/R38 100k pull-ups, C30 10uF
    on OUT. CE and SYSOFF tied low; TMR left open for the default safety timers.
    EN1/EN2/PGOOD/CHG go to GPIO5/18/21/38.
    BAT_SEN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
    [BalancerREF.kicad_pcb, BalancerREF.kicad_sch, IC-pin-audit.csv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]
2026-09-13 fix: make the connectivity safeguards abort and restore, not just print
    Review feedback on remove_bat_sense.py: it computed the list of surviving nets
    that had moved, printed it, and exited 0 - after already overwriting both the
    schematic and review/unused-pins.json. A regression would have left a corrupted
    sheet looking like a successful run, which is the exact failure the check was
    supposed to prevent.
    The same gap was in two sibling scripts. remove_sw4.py, remove_r5.py and
    split_optical_head.py already exited non-zero on a failed check, so the fix is
    to bring the other three up to that standard and give all of them the restore
    step none of them had:
    * scripts/rollback.py - snapshots t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
    [add_bat_sense.py]
2026-09-13 fix: address repo review findings before routing
    An external review raised seven pre-routing items plus smaller notes. Each was
    checked against the manufacturer source rather than taken on faith; two did not
    survive that check and are recorded as not-confirmed.
    Confirmed and fixed:
    * D1 peak current. The head runs from SYS_SW, and with the BQ24075 regulating
    OUT to 5.5 V, R18 at 3.0 ohm gave ~1.1 A peak against D1's 1 A absolute
    maximum. The BOM note had only checked the 4.2 V battery case, and the
    charger swap - which replaced a Schottky holding SYS near 4.55 V - is what
    pushed it over. R18 -> 3.9 ohm: ~0.49 A at a full cell (the bench-set design
    point) and ~0.90 A w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
    [BalancerREF.kicad_pcb, BalancerREF.kicad_sch, BalancerREF_OptHead.kicad_pcb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]
2026-09-13 docs: mark the boards Rev F and Rev B
    The main sheet goes Rev E -> F. Rev F is the repo-review revision: no new
    function, but corrections that have to be right before any copper is routed.
    One of them cleans up after Rev E. Removing the USB Schottky raised SYS_SW, and
    the head's emitter resistor was still sized for the old rail, so D1 was being
    driven past its absolute maximum on USB. The rest are a logic part run outside
    its input-transition spec and three placement problems, the worst a 2.4 MHz
    switching loop routed through vias.
    The optical head goes Rev A -> B. That is its first change since it was created:
    R18 changed value and the emitter loop and TIA node were both re-placed.
    Two r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
    [BalancerREF.kicad_sch, BalancerREF_OptHead.kicad_sch]
2026-09-13 fix: U9 sourcing metadata, capacitor pin targets, charger docs
    Three review comments on PR #2, all three valid.
    U9 sourcing still said SN74LVC1G08 (P1). The Value field was swapped but the
    footprint's Datasheet and MPN properties, PhotoTach-BOM.csv and the JLCPCB
    checklist all still named the AND gate. An MPN-driven order would have populated
    a part the circuit no longer works with - U10 is wired for the NAND polarity and
    the whole point of the swap is the Schmitt inputs. All four updated, plus the
    Rev C pin-audit line marked superseded so it is not read as current.
    While chasing that: the schematic's lib_symbols cache still held definitions for
    seven parts no longer on the sheet, includin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
    [BalancerREF.kicad_pcb, BalancerREF.kicad_sch, PhotoTach-BOM.csv]
2026-09-14 fix: flip PD1 - the optical comparator could never trip
    Confirmed against the netlist, not the description. PD1 was wired cathode to
    +3V3 and anode to the transimpedance summing node. The reverse bias is correct
    that way, 1.65 V cathode-positive, which is presumably why it survived this long.
    The signal direction is not.
    Photocurrent leaves the ANODE of a reverse-biased photodiode, so with the anode
    on the summing node it was injected into the node rather than pulled out:
    PD1 anode on the node -> current INTO the summing node
    U8A, U8.2 = IN- -> inverting TIA, TIA_OUT FALLS
    U8B, gain -120k/10k -> inverting, OPT_AMP RISES from 1.65 V
    U4, U8.4 = IN- -> against CMP_T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
    [BalancerREF_OptHead.kicad_pcb, BalancerREF_OptHead.kicad_sch]
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2026-09-17 fix: recover_from_dsn replaces existing copper and creates its backup dir
    Review feedback on #4. The DSN is a complete snapshot, so replaying it on
    top of a board that already has copper duplicated every shared track and
    via; replacement is now the default, with --keep-tracks to opt out. The
    gitignored BalancerREF-backups directory is created before anything is
    written into it, so --apply works on a clean checkout.
    [recover_from_dsn.py]
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2026-09-18 fix: BOM fields, silkscreen labels, +3V3 plane, and stale docs before review
    - MPN fields: R3/R35/R36 (were "100k"), U9 (was the 1G08), R18 (was 3R0)
    - Title block: HOBOVibe spelling; head company line no longer says "human
    review required"
    - C20 on the head board rated 10 V; SYS_SW can sit at 5.5 V
    - Silkscreen: board name and rev on both boards, battery and MAG polarity,
    pin-1 marks on J4 and both J5
    - Main PCB: SYS, SYS_SW, BAT and USB_VBUS tracks removed from In2.Cu so the
    +3V3 plane is whole; three vias that only served them removed. Those four
    nets need re-routing on the outer layers.
    - Docs: routing state, ground-pour wording, missing head-board holes,
    JLCPCB parts table reb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
    [BalancerREF.kicad_pcb, BalancerREF.kicad_sch, BalancerREF_OptHead.kicad_pcb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]
2026-09-18 feat: BalancerREF routed to a clean DRC
    Power routing moved off the inner layers so In1 (GND) and In2 (+3V3) are
    uncut planes. Thermal vias under the BQ24075 and TPS63031 exposed pads
    (4 and 5). Switcher caps tight to the pins: C4 1.8 mm from VIN, C5 1.8 mm
    from VINA, C6/C7 1.3 and 2.4 mm from VOUT; U2 decoupling within 1.6 mm.
    SYS_SW bridged across U6 so VIN and VINA share one feed. Autorouter vias
    resized to class values, stacked vias removed, silk polarity marks raised
    to the minimum text height.
    DRC: 0 errors, 0 unconnected. Remaining warnings are the GCT USB-C
    footprint's own peg-to-pad spacing, the ESP32 module's antenna overhang,
    and the local U1 footprint edit.
    Rules: neck-down con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
    [BalancerREF.kicad_pcb]
2026-09-19 fix: Rev G - D3 polarity, USB lines through U7, U9 pull-down, sharper review images
    Three corrections from the Reddit review of the Rev C sheet, all still present in
    Rev F:
    - D3 (SMF5.0A, unidirectional TVS on USB_VBUS) was drawn cathode to GND and anode
    to VBUS: forward biased across the port. Cathode (pin 1) now on USB_VBUS; the
    D_SMF footprint is rotated 180 so pad 1 lands on the VBUS copper.
    DATASHEET-VERIFICATION had recorded the part as bidirectional; corrected.
    - U7 (SRV05-4) pins 4 and 6 were NC and D+/D- hung off the array as stubs. The
    drawing now takes D- in at pin 1 and out at pin 6, D+ in at pin 3 and out at
    pin 4 (the opposite pads of the SOT-23-6). Nets stay the sam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
    [BalancerREF.kicad_pcb, BalancerREF.kicad_sch, IC-pin-audit.csv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]
2026-09-19 docs: board renders and a section-by-section repost draft for the Reddit thread
    The thread (r/PCB 1wjh9hl) had two more comments beyond the three schematic
    points: the board pictures were too low resolution, and a request to explain
    each circuit section before reviewing. render_review_images.py now also renders
    top/bottom of the main board and the head board at 2400 px, and
    review/reddit/POST.md is a paste-ready follow-up built from the repo docs, with
    the assembly split (ICs and connectors front, 0603 passives back) answered.
    Claude-Session: https://claude.ai/code/session_01RAWf9Skey6ZcU82AJn2CyR
2026-09-19 fix: D3 polarity, U9 input bias, USB pair through U7
    D3 SMF5.0A was drawn anode-to-VBUS. It is the unidirectional part of the
    SMF family, so that is a forward diode across the USB supply - the board
    would have collapsed VBUS and tripped the host port rather than
    enumerating. Symbol rotated 180 degrees; the footprint turned with it and
    the two pad nets swapped, so no track moved and the silkscreen band now
    marks the VBUS end.
    R39 and R40 (100k) pull U9's two Schmitt inputs low. Pin 1 floats whenever
    the optical head is unplugged from J5 - normal for MR-VERT - and pin 2
    while GPIO13 is still high-Z through the ESP32 boot. Low is the fail-safe
    direction: the NAND holds Y high and U10's ~A trig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
    [BalancerREF.kicad_pcb, BalancerREF.kicad_sch]
2026-09-20 feat: hand re-layout of the USB front end
    U7 moved to (131.20, 136.75) rot -90, R39 to (111.40, 114.60) and R40 to
    (109.65, 114.60), with the data pair re-routed to suit. R6 and R7 stay put.
    D3's corrected polarity and U7's IO3/IO4 wiring both carry over unchanged,
    so each USB line still enters one pad of the array and leaves the pad
    opposite rather than spurring off the series resistors.
    kicad_pro: sch_revision F -> G, sheet_component_classes enabled.
    DRC 7 violations, 0 unconnected. The seven are the pre-existing footprint
    issues - the GCT USB-C peg-to-pad spacing (x4), the ESP32 antenna overhang
    (x2) and the local U1 footprint edit. Schematic parity is 7, all of them
    extra_footprint on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
    [BalancerREF.kicad_pcb]
2026-09-21 feat: BalancerCarrier on a FeatherS3[D], and two board fixes
    Adds BalancerCarrier: the HOBOVibe instrument rebuilt as a carrier around an
    Unexpected Maker FeatherS3[D] (ESP32-S3, 16 MB flash, 8 MB QSPI PSRAM), so the
    MCU, LiPo charger, fuel gauge and USB come from a proven module instead of being
    respun. 31 parts, ERC 0 violations.
    The module is a Feather, so U1 uses Module:Adafruit_Feather-compatible geometry -
    Unexpected Maker's own 28-pad footprint and symbol, checked pin-for-pin against
    their FeatherS3[D] schematic headers J1 and JP3. That makes the footprint
    vendor-independent: another Feather drops in without a respin, which is the
    exposure that bit this project when the DFR0975 went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
    [BalancerCarrier.kicad_sch, BalancerREF.kicad_pcb, BalancerREF.kicad_sch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]
2026-09-22 feat: carrier PCB first layout, schematic fixes, OptHead 3D models
    BalancerCarrier
    - First .kicad_pcb into git: 4 layers, 139 tracks, 51 vias, GND on In1.Cu
    and +3V3 on In2.Cu, 0 unconnected. Placement recovered from
    temp-freerouting.dsn after the Freerouting crash took the board file.
    - Schematic fixes found in review: LED1 was wired backwards (cathode on the
    GPIO), R13 sat in series with J5.5 instead of returning to GND, and
    GPS_UART_RX collided with the module I2C bus on IO9 - moved to IO7.
    - The GPS block is kept but DNP for the first round; the board is a
    proof-of-concept that the balancer works before the GPS is added on.
    - .kicad_pro carries the netclasses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
    [BalancerCarrier.kicad_pcb, BalancerCarrier.kicad_sch, BalancerREF_OptHead.kicad_pcb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]
2026-09-23 fix: IIS3DWB at fixed 16 g, per-sample clipping, direction-only results
    Accelerometer range
    - Run the IIS3DWB at a fixed +/-16 g from one setting (src/accelscale.hpp)
    that drives the register, raw-to-g scale, clip threshold and reported
    full_scale_g. The old +/-2 g range clipped 2.0 IPS at 2200 RPM plus
    gravity. DS12569 noise density is independent of full scale, so the
    wider range costs no usable resolution, and never switching range means
    no run can mix differently scaled samples.
    - Judge clipping on every raw FIFO sample before the 16-sample average, per
    axis, at 95% of full scale. Only the selected axis invalidates a run;
    others are reported per axis.
    Measurement
    - Split p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
    [accel.cpp, main.cpp, measurement.hpp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]
2026-09-23 fix: GGA without a fix clears validity; only RMC feeds the flight gate
    A quality-0 GGA left the last RMC fix valid, and every accepted sentence bumped fixSequence. With RMC lost and GGA still arriving, the level-flight gate kept adding the stale fix as current; with both arriving it counted every fix twice per epoch.
    GGA quality 0 or empty now clears fix.valid. Nmea::motionSequence() advances only on RMC, the sentence carrying speed and course, and gps.cpp publishes that as fixSequence. lastValidUs still refreshes on any checksum-valid sentence, since it drives baud detection and module presence. Six new host checks.
    [flightlog.hpp, gps.cpp]
2026-09-23 fix: package releases from the carrier build
    package_release.py read .pio/build/balancerref, which the only environment in platformio.ini never produces, so it always failed, or packaged a stale BalancerREF image with 8 MB flashing instructions. It now reads .pio/build/balancercarrier, records the FeatherS3[D] target and 16 MB DIO flash (offsets 0x0/0x8000/0x10000 match partitions.csv), copies the build's actual .map and sdkconfig.balancercarrier, and takes the version from main.cpp. Checked by packaging the 2026-09-23 build.
    [package_release.py]
2026-09-23 docs: carrier firmware README describes the FeatherS3[D] board
    The README was copied from BalancerREF: an 8 MB no-PSRAM MINI-1 target, BQ24075 charger pins, and the old GPIO map in the accelerometer, sleep-wake and GPS sections. It now names the FeatherS3[D] (16 MB flash, 8 MB PSRAM), describes what the module owns (charging, MAX17048 gauge, VBUS sense on GPIO34, LDO2 GPS power on GPIO39), uses board.hpp's GPIOs throughout, and gives the module's BOOT/RST flashing steps and the verified carrier build. accel.hpp's pin comment is corrected the same way.
2026-09-23 fix: verify_netlist checks the live schematic, and covers the battery switch
    The verifier read review/BalancerREF.net, which is only as fresh as its last regeneration, so it could not verify the Rev G fixes it specified. It now exports a netlist from BalancerREF.kicad_sch with kicad-cli on every run; --netlist FILE checks a saved one instead.
    Checking the live schematic showed the spec was also behind it: the Q4/Q5 back-to-back battery path switch with its Q6 enable (R41-R44, C31) was unspecified. Added as BAT, BAT_CONNECTOR, BPS_SRC, BPS_GATE, BPS_PULLDOWN and BPS_SENSE, with Q4.1 out of and Q6.2/R44.2 into GND. PASS: 53 exact circuit nets, 306 pin endpoints, 140 IC pads.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
2026-09-24 feat: carrier J5 moved toward the optical head; head gain redistributed
    Carrier: J5 moved up the left edge, next to the optical head, clear of the
    FeatherS3[D] battery connector, opening away from the module. Each J5 ground
    pin and 3V3 now drops to its plane through its own via within ~2 mm, and
    OPT_COMP no longer runs alongside OPT_LED_EN. DRC 0 violations, 0
    unconnected, 0 schematic parity (with the local U5 LGA pad-to-pad rule).
    Optical head: R21 10k -> 4.99k, R23 120k -> 240k, C21 22p -> 47p C0G. Same
    ~120 kOhm total gain with about twice the TIA ambient headroom (~160 to
    ~320 uA photocurrent), per the 2026-09-23 SPICE review; to be bench-tested
    before production. Silkscreen cleanup cle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
    [BalancerCarrier.kicad_pcb, BalancerCarrier.kicad_sch, BalancerREF_OptHead.kicad_pcb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]
2026-10-02 Add Digi-Key order list for parts still missing on the carrier and optical head
    Claude-Session: https://claude.ai/code/session_01XT5akMmBgbqYX83ryU4fFA
    [digikey-missing-parts-2026-10-02.csv]
2026-10-02 Fix four Yageo resistor Digi-Key part numbers in the order list
    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
    [digikey-missing-parts-2026-10-02.csv]
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2026-10-22 v2 notes: ADXL357 eval board replaces the analog accelerometer front end
    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
2026-10-22 v2 main unit: OMGS3 module on pads replaces the FeatherS3
    Official Unexpected Maker symbol and footprint copied under
    BalancerMain/vendor with their CERN OHL license. New GPIO map, PROG
    header for USB D+/D-, IO0 and RESET, 5 V OR-ing diode removed. Board
    regenerated with the module's antenna end at the board edge and the
    LED moved off it. Pin map and design notes updated.
    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
2026-11-09 Carrier firmware: anti-alias FIR, explicit speed band, pre-anchor samples
    - Replace the 16-sample boxcar with a 161-tap linear-phase FIR decimator
    (flat to 400 Hz, >=79 dB from 1266.7 Hz). A rotor-locked 1 g tone at
    1706.7 Hz with no 1/rev input read as a stable 0.036 IPS vector through
    the boxcar; it now reads 0.00004 IPS and is classed weak. Timestamps
    shift by the exact 80-sample group delay; the FIR resets on any failed
    block.
    - Drop samples delivered after the first tach edge but timestamped up to
    5 ms before it instead of raising TimingError. A first edge in the late
    part of a FIFO block failed an otherwise clean run; with the FIR's 3 ms
    delay that would have been every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
2026-11-09 Solver: verified imports, keyed runs, installable moves, signed learning
    - History import: a record is used only if every field is plausible and
    the stored level is a power-of-two multiple of solution/SENS. All five
    A1090731 runs pass and match the MicroBase screen; all eight A1090021
    runs fail (run 3 decoded as 2.12e38 IPS against 0.933) and are shown
    but kept out of solving and learning.
    - Runs are keyed by aircraft, session and profile revision (FNV hash of
    the group section, so A1090731 lines up with A109.grp); coefficients
    by aircraft, profile revision and task. Regimes combine only when they
    name the same correction plane; T/R BAL no longer joins GND LT just
    because bot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
2026-11-09 Cross-check carrier firmware against the boards as manufactured
    - Extract pad -> net tables from the Gerber X2 attributes of the
    BalancerCarrier and BalancerREF_OptHead fab packages
    (scripts/gerber_pads.py); both match the repo .kicad_pcb files pad for
    pad. Provenance and package hashes in manufactured/SOURCE.txt.
    - check_pinmap.py now checks board.hpp against the as-built carrier
    instead of BalancerCarrier.net, which is stale against the PCB (GPIO7
    and all of J4 unconnected, J5.5 on GND) and was why the check failed.
    It also checks the far end of every signal. All 13 header signals and
    14 far-end pads match the firmware.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
2026-11-09 Solver: scope coefficients to sensor calibration, keep pending changes
    - Coefficient key is now aircraft|profile revision|calibration|task, so a
    new calibration starts from the profile seed instead of reusing (and
    then blending into) another sensor's SENS/TACH. Reset uses the same
    key; .HST imports seed under calibration "MicroVib", which their runs
    carry. State version 3; version 2 keys migrate under the blank
    calibration they were learned with.
    - Per-position changes typed but not yet added survive re-renders (any
    setting change used to blank them, so Add run recorded no change,
    skipped learning and left the installed inventory wrong). They clear
    only after a run is added.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
2026-11-09 Solver: per-calibration runs, faithful v2 migration, keyed pending changes
    - Runs feed solutions, learning and the polar plot only under the sensor
    calibration they were measured with; other calibrations stay listed as
    not used. Switching cal-A -> cal-B no longer solves cal-A's run with
    cal-B's coefficient (100 g became 320 g with no new measurement).
    - Version 2 coefficients migrate to the calibration of the runs they were
    used with, or to the active calibration if they have none. One used
    under several calibrations is held back in coefHeldBack and reported
    on load; the profile seed applies.
    - Pending per-position changes are keyed by aircraft, profile revision,
    session and ta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
2026-11-09 Solver: learn against the true predecessor, prove v2 coefficient ownership
    - Learning compares against the run immediately before this one for the
    task, whatever calibration it was under and whether or not it passed
    its checks, then applies M.compatible. Taking the last same-calibration
    run skipped adjustments installed in between: 1.0 IPS, +10 g under
    cal-B, +10 g under cal-A at 0.6 IPS learned SENS 25 instead of 50. Now
    that pair is refused and the next consecutive cal-A pair learns 50.
    - Version 2 migration assigns a coefficient to a calibration only when
    every run of the task was under that one calibration and the value
    still equals what the latest run recorded as in effect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
